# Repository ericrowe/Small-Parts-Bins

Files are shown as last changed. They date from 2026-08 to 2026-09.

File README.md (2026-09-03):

# Gridfinity Glass-Window Cassette System

This project is developing a durable, modular storage system for screws, nuts,
bolts, and other small hardware. Individually closed and labeled cassettes sit
inside stackable Gridfinity-compatible carrier trays, preventing the broad spill
failure of conventional open bins while keeping contents and approximate stock
levels visible through replaceable microscope-slide glass.

> [!WARNING]
> **AI-assisted development:** This project includes dimensions, code, geometry,
> documentation, and recommendations produced with assistance from generative
> AI. AI output can be incomplete, internally inconsistent, or geometrically
> wrong even when source calculations, previews, or mesh audits appear valid.
> Nothing in this repository is a certified engineering design or a substitute
> for independent review, slicer inspection, test prints, measurements, and
> real-world validation.
>
> Printed parts and glass can fail. Inspect every exported STL and sliced toolpath,
> reject chipped or forced glass, wear appropriate eye protection when handling
> or testing glass, and keep hands clear of sharp fragments. Do not rely on an
> unverified cassette or carrier to contain hazardous, valuable, food-contact,
> medical, electrical-safety-critical, or otherwise safety-critical contents.
> The person fabricating and using these parts is responsible for determining
> whether a particular revision, material, printer, and application are safe.

> [!CAUTION]
> **Active development:** This project is a work in progress. Dimensions,
> tolerances, interfaces, filenames, instructions, and compatibility may change
> at any time without notice as physical-test results become available. A part
> that fits one revision, material, printer, or slicer configuration may not fit
> another, and compatibility with future releases is not guaranteed unless it is
> explicitly documented.
>
> Before printing, record the exact Git commit and part version being used,
> review the matching README, manifest, and physical-test notes, and inspect the
> sliced toolpath. Print the supplied functional coupons and one complete sample
> before committing to a large batch. Do not mix revisions based only on similar
> appearance or filenames; use the documented compatibility rules. Keep known-
> good printed parts until their replacements have passed the same real-world
> tests, and expect failed or superseded prototypes during development.

## Project goals

- Keep every cassette individually closed when removed, handled, or tipped.
- Make contents and 9 mm Brother TZe labels visible from above in an open drawer.
- Use replaceable, mechanically retained microscope-slide glass rather than
  press-fit acrylic.
- Build a compatible family of cassette sizes on a consistent cassette sub-grid.
- Support optional removable dividers that form two or three equal compartments
  and minimize very-small-part transfer during rollover.
- Hold cassettes in loaded, stackable carriers using the standard 42 mm
  Gridfinity pitch, base, stacking interface, and 7 mm height increments.
- Fit practical loaded stacks below the measured drawer ceiling of
  **111.125 mm (4 3/8 in)**.
- Treat exported-STL audits and physical prints—not visual plausibility—as the
  authority for functional geometry.

## Human and AI Roles in Development

This project uses an iterative Human-in-the-Loop (HITL) engineering methodology. Responsibilities are clearly divided:

- **Human Collaborator:**
  - **Strategic Direction & Requirements:** Defines project goals, physical boundaries (e.g. drawer depth, glass sizes, hardware volumes), and prioritizes/approves plans.
  - **Fabrication & Machine Operation:** Manages slicer setup, material selection (PETG, ASA, PLA), print profiles, and printer execution.
  - **Ground-Truth Physical Validation:** Performs assembly, caliper measurements, tactile/ergonomic evaluation (grasp ease, latch tension), and real-world failure testing (stacking fit, rollover, drops).
  - **Authoritative Adjudication:** Physical observations are binding. When prints contradict CAD or mathematical models, the human's findings govern all redesigns.

- **AI Coding Agent:**
  - **Parametric CAD Generation:** Maintains editable Python mesh generators producing support-free printable STL files.
  - **Automated Geometry Auditing:** Audits STL meshes for 0 boundary edges, 0 non-manifold edges, finite coordinates, and shell connectivity.
  - **Tolerance Budgeting & Pipeline Management:** Tracks stack calculations, clearance budgets, and structured plans in `Plans/`.
  - **Continuous Documentation Integrity:** Reviews and updates all READMEs, manifests, and test notes with every commit.

## Current status — 2026-08-28

The 14U vertical carrier stack architecture has been **physically verified**
([Plan 001](hardware/plans/Completed/2026-08-28-001-validate-14u-carrier-stack.md)): two 3 × 4 × 7U
carrier trays seat onto standard Gridfinity baseplates in the target drawer with ample
clearance below the 111.125 mm drawer ceiling.

The height-optimized cassette standard is **physically verified** as **v0.8**
([Plan 002](hardware/plans/Completed/2026-08-28-002-optimize-cassette-and-carrier-height.md)):
closed envelope of **$39.55 \times 80.0 \times 36.0\text{ mm}$** (body height $32.80\text{ mm}$,
lid height $3.20\text{ mm}$), providing **$30.80\text{ mm}$ of usable internal depth**
(+35.1% capacity increase over the $28.0\text{ mm}$ baseline) and tested non-interference
clearance below the upper carrier tray's downward-protruding Gridfinity feet ($Z = 44.25\text{ mm}$).
The physically verified v0.7 lid, glass slide channel, 6.75 mm compliant PETG latch, and
3-knuckle filament hinge are 100% reusable.

The removable divider system is **physically verified**
([Plan 003](hardware/plans/Completed/2026-08-28-003-develop-optional-cassette-dividers.md)):
$1.40\text{ mm}$ recessed side-wall channels and floor groove with a thickened $4.30\text{ mm}$
left wall providing $+0.65\text{ mm}$ unobstructed vertical drop-in clearance past the hinge knuckle,
and two stations at $Y = \pm 12.87\text{ mm}$ creating three equal $24.53\text{ mm}$ compartments.

The verified closure latch plan is **[Plan 010](hardware/plans/Completed/2026-08-29-010-re-evaluate-cassette-closure-latch.md)**
(Priority 1): re-evaluate and redesign the cassette closure latch to prevent disengagement
caused by front-wall outward deflection when removable dividers are installed.

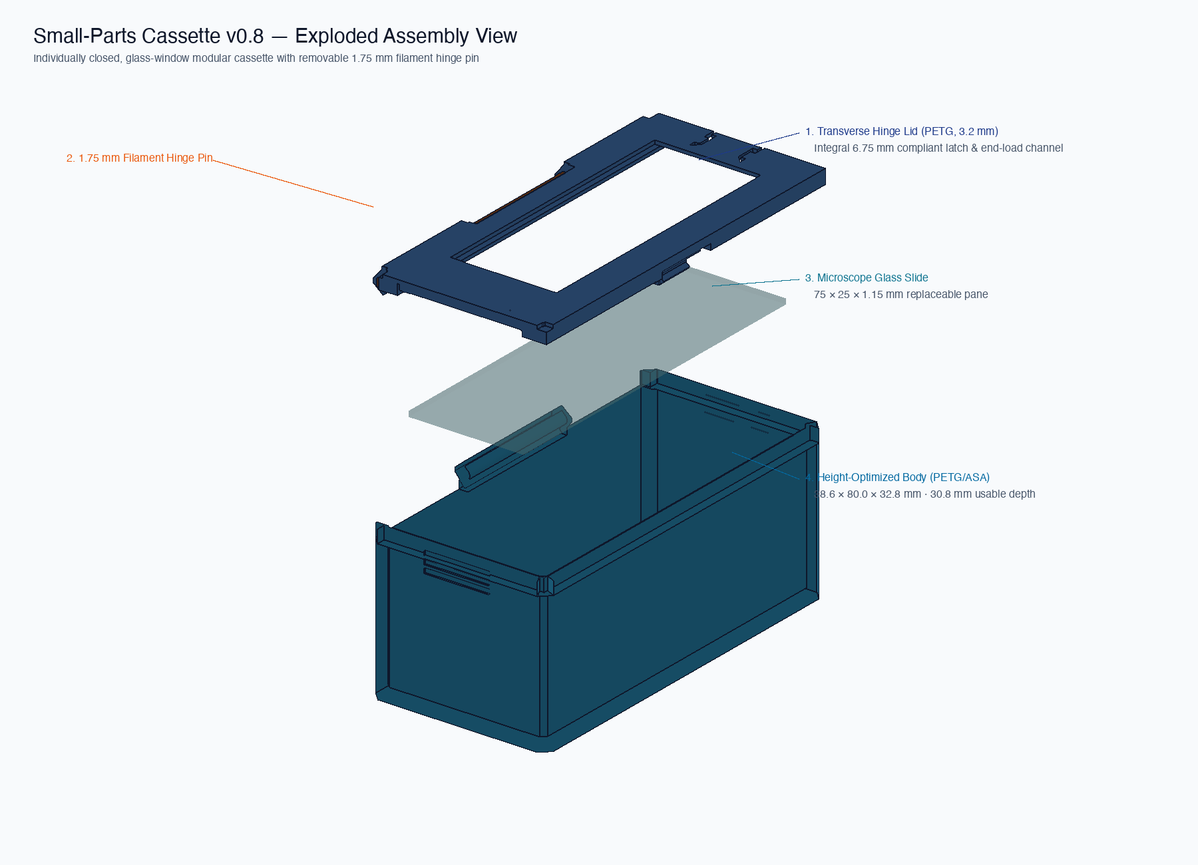
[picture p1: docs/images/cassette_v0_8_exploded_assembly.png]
Small-Parts Cassette v0.8 Exploded Assembly


## 3D System Architecture & Model Gallery

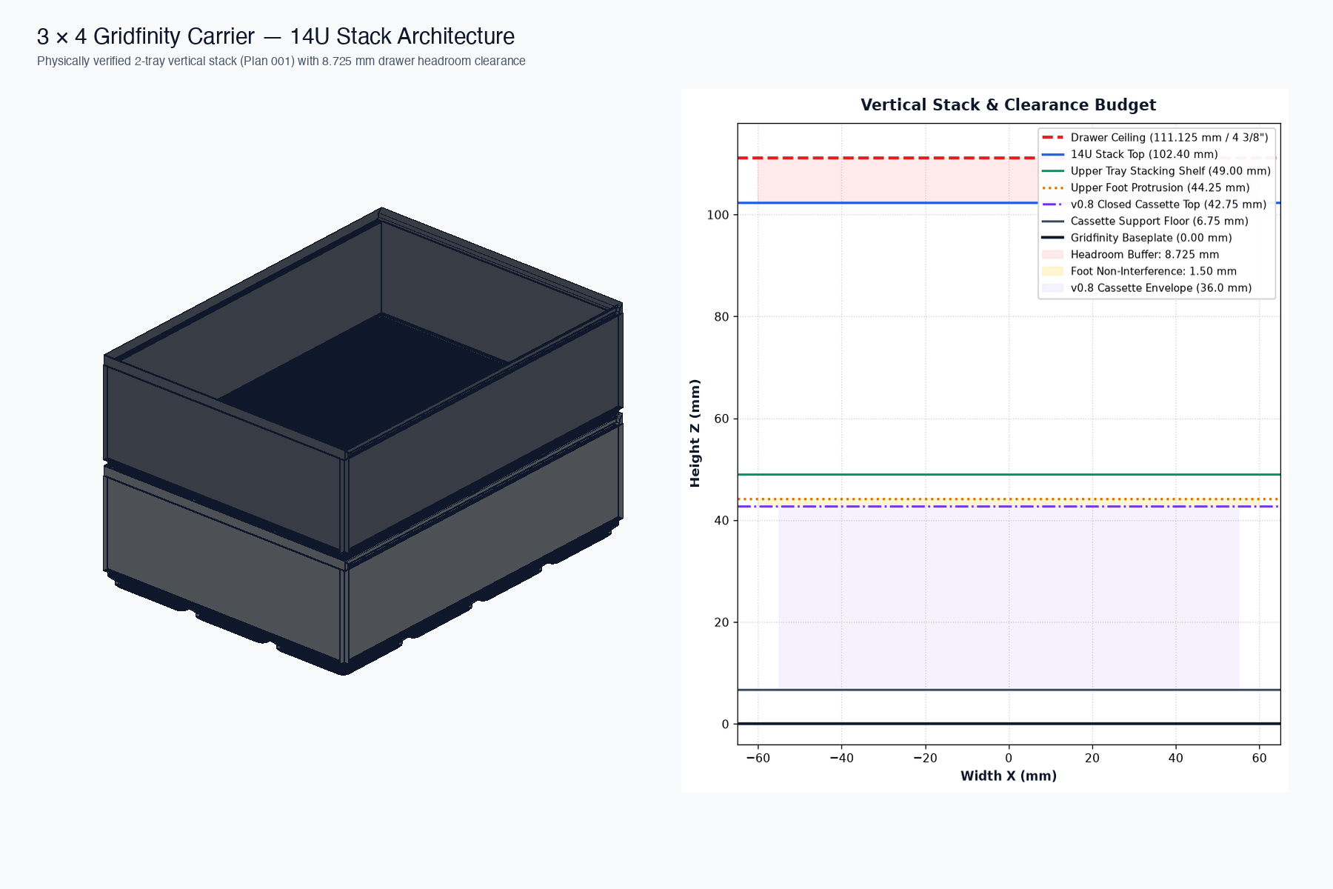
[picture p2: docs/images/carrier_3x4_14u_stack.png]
14U Carrier Stack & Tolerance Budget


| Component 3D Drawing | Description |
|---|---|
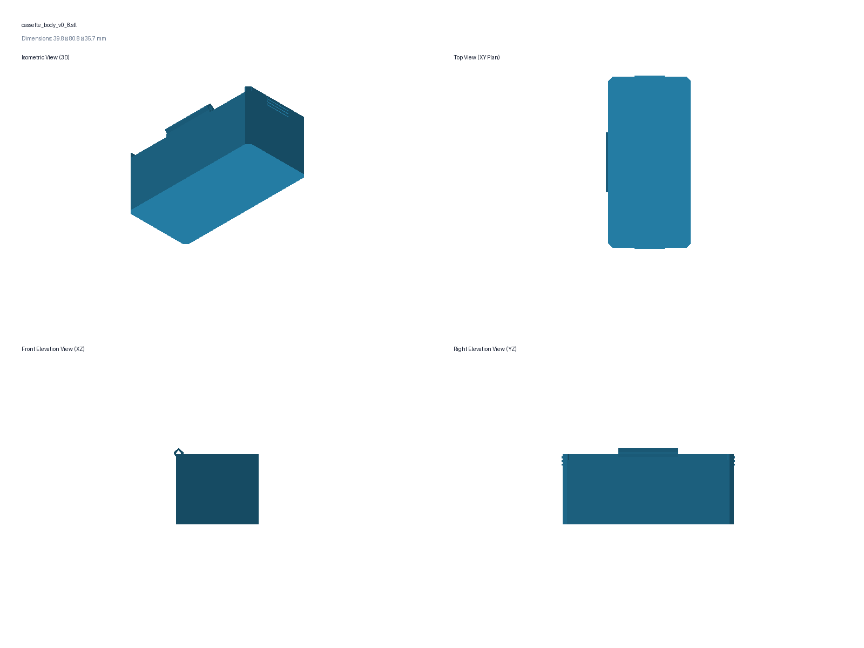
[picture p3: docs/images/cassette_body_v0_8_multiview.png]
v0.8 Body
|  | **v0.8 Cassette Body:** $38.6 \times 80.0 \times 32.8\text{ mm}$, $30.8\text{ mm}$ cavity depth, $2.0\text{ mm}$ floor. |
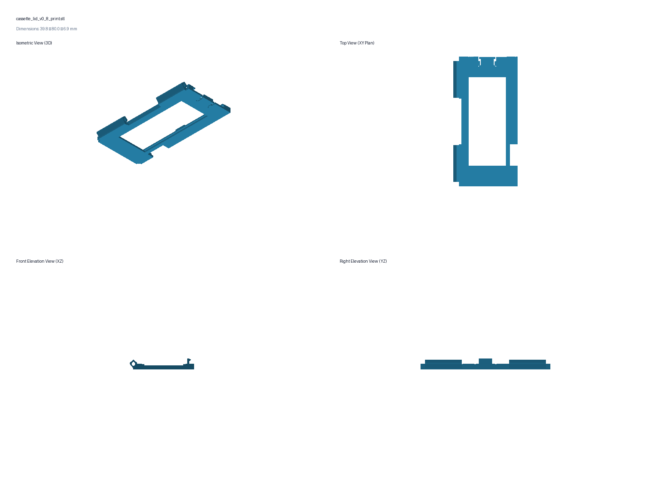
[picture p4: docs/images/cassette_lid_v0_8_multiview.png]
v0.8 Lid
|  | **v0.8 / v0.7 Transverse Lid:** End-loaded $27.0 \times 1.4\text{ mm}$ channel, compliant PETG latch. |
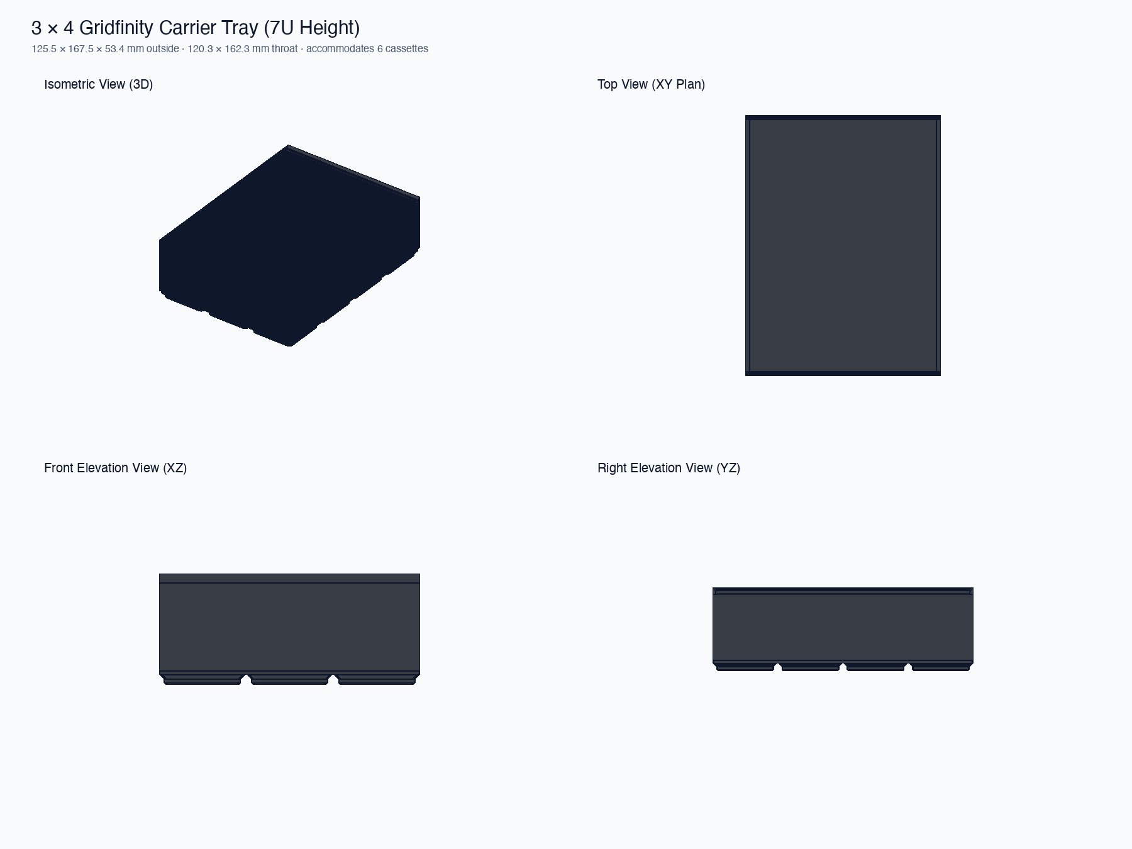
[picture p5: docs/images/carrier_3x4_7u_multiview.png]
Carrier Tray
|  | **3 × 4 × 7U Carrier:** Holds 6 modular cassettes with solid $2.6\text{ mm}$ walls. |

## Current reference configuration

| Component | Current reference | Validation state |
|---|---|---|
| Optimized cassette | v0.8 ($39.55 \times 80.0 \times 36.0\text{ mm}$ closed; $32.8\text{ mm}$ body) | **Physically verified** (Plan 002 complete) |
| Removable dividers | $1.40\text{ mm}$ slot channels, $1.20\text{ mm}$ card, 3 equal compartments | **Physically verified** (Plan 003 complete; latch re-evaluation pending in Plan 010) |
| Low-profile baseline | v0.7 ($39.55 \times 80.0 \times 28.0\text{ mm}$ closed; $24.8\text{ mm}$ body) | Physically verified; hinge, capture, clasp, and split line pass |
| Window | Plain slide glass, maximum intended 26.3 × 76.3 × 1.2 mm | Measure each delivered batch |
| Pane capture | End-loaded 27.0 × 1.4 mm channel; integral 6.75 mm PETG latch | Physically verified (Plan 009 complete) |
| Hinge pin | Straight 1.75 mm printer filament | Works well in the verified hinge pair |
| Reference carrier | 3 × 4 × 7U, six cassettes | **Physically verified** (Plan 001 complete) |
| Two-carrier stack | 14U, modeled 102.4 mm overall | **Physically verified** in target drawer (Plan 001 complete) |
| Drawer ceiling | 111.125 mm | Measured absolute ceiling |

## Development Sequence & Plan Lifecycle

The project utilizes a centralized multi-prefix plan lifecycle under [`docs/plans/`](docs/plans/):
- **`MNN` (Master / Cross-Subsystem Plans)**: End-to-end integration across hardware, labels, web catalog, and server infrastructure.
- **`HNN` (Hardware Subsystem Plans)**: 3D CAD models, Gridfinity carriers, slide cassettes, divider cards, and Cricut cut sheets under [`hardware/`](hardware/).
- **`SNN` (Server Subsystem Plans)**: FastAPI web application, SQLite schema/migrations, REST endpoints, and HTML5 camera QR scanner under [`server/`](server/).

Historical mechanical 3D print plans are archived in [`hardware/plans/Completed/`](hardware/plans/Completed/). Active software and cross-system plans are tracked in [`docs/plans/AGENTS.md`](docs/plans/AGENTS.md).

The active cassette 3D models are located in [`hardware/cassettes/glass_slide_cassette_40x80/`](hardware/cassettes/glass_slide_cassette_40x80/) as `cassette_body_v0_8.stl` and `cassette_lid_v0_8_print.stl`.

New ideas belong in [`docs/plans/IDEAS.md`](docs/plans/IDEAS.md).

## Repository Architecture

- [`AGENTS.md`](AGENTS.md) — binding dimensions, physical findings, validation rules, compatibility history, and repository working agreements.
- [`.agents/`](.agents/) — modular agent customization directory containing `skills/` (e.g. `mesh-auditor`, `cad-renderer`, `plan-pipeline`, `hardware-prototyper`) and `plugins/`.
- [`hardware/`](hardware/) — physical 3D fabrication CAD models, printable releases, manifests, previews, labels, and mechanical test archives:
  - [`hardware/carriers/`](hardware/carriers/) — Gridfinity modular trays and rocker inserts.
  - [`hardware/cassettes/`](hardware/cassettes/) — glass slide storage cassettes and divider cards.
  - [`hardware/labels/`](hardware/labels/) — SVG vector label generators, fastener database, and Cricut print-then-cut sheets.
  - [`hardware/scripts/`](hardware/scripts/) — batch STL rendering and CAD build automation.
  - [`hardware/plans/`](hardware/plans/) — historical mechanical 3D design plan archives.
- [`server/`](server/) — web catalog microservice, inventory database, and QR code scanner:
  - `server/app/` — FastAPI application and catalog routes.
  - `server/database/` — SQLite parts/bins schema and models.
  - `server/static/` & `server/templates/` — responsive web UI and HTML5 camera QR barcode scanner.
  - `server/scripts/` — automated SQLite atomic `VACUUM INTO` backup script ([`server/scripts/backup_parts.sh`](server/scripts/backup_parts.sh)) and turnkey bare-metal node provisioner ([`server/scripts/bootstrap_node.sh`](server/scripts/bootstrap_node.sh)).
  - `server/docs/` — disaster recovery runbook ([`server/docs/BACKUP_AND_RECOVERY.md`](server/docs/BACKUP_AND_RECOVERY.md)).
  - `server/tests/` — hermetic test suite.
- [`docs/plans/`](docs/plans/) — centralized multi-prefix plan lifecycle, master registry ([`docs/plans/AGENTS.md`](docs/plans/AGENTS.md)), and backlog ([`docs/plans/IDEAS.md`](docs/plans/IDEAS.md)).

## Web Catalog Server & Inventory Microservice

The server provides a responsive web UI and REST API for searching hardware specifications, reviewing tap drills, and managing bin inventory. In production, it is deployed to **Node 02 (`tasker-pi`, Pi 4B)** on port `:8090` with persistent storage on the external Samsung SSD at `/srv/database/parts/parts.db`:

1. **Setup & Start Server (Local Workstation):**
   ```bash
   cd server
   ./run.sh  # Starts on http://0.0.0.0:8090
   ```
2. **Access Points:**
   - **Dashboard:** [http://localhost:8090/](http://localhost:8090/) (or `http://tasker-pi.local:8090/`) — Overview metrics, category distribution, and active physical bins.
   - **Fastener Catalog:** [http://localhost:8090/parts](http://localhost:8090/parts) — Full-text searchable database with bi-directional column sorting, thread pitches, and tap drills.
   - **Fastener Technical Specs:** [http://localhost:8090/p/{part_id}](http://localhost:8090/p/M3-12mm-SHCS) — Detailed engineering specs and physical bin locations.
   - **Cassette Bin Management:** [http://localhost:8090/b/{bin_id}](http://localhost:8090/b/BIN-001) — Visual 1, 2, or 3-compartment cassette layout with dynamic part mapper dropdowns and one-tap stock adjusters.
   - **REST API Docs:** [http://localhost:8090/docs](http://localhost:8090/docs) — Interactive OpenAPI Swagger UI.

## Automated Backup & Turnkey Disaster Recovery

- **Target Host**: Node 02 (`tasker-pi.local`, `192.168.0.191`) co-located with Personal-Assistant.
- **Database Location**: Persistent Samsung SSD at `/srv/database/parts/parts.db` (Write-Ahead Logging).
- **Atomic SQLite Snapshots (`VACUUM INTO`)**: Daily zero-downtime snapshots captured via [`server/scripts/backup_parts.sh`](server/scripts/backup_parts.sh).
- **Encrypted Node 04 Storage**: Shipped encrypted via `restic` over SFTP to Node 04 (`pi-backup.local:/srv/backups/restic/parts-database/`).
- **Retention**: 14 daily, 8 weekly, 12 monthly snapshots.
- **Turnkey Provisioning**: Fresh nodes provisioned from bare-metal in under 5 minutes via [`server/scripts/bootstrap_node.sh`](server/scripts/bootstrap_node.sh). See [`server/docs/BACKUP_AND_RECOVERY.md`](server/docs/BACKUP_AND_RECOVERY.md).

## Working rules

- Read this README, `AGENTS.md`, the active plan, relevant release README and
  manifest, and the latest physical-test notes before changing geometry.
- Print exact functional coupons before committing material to complete parts.
- Never scale parts in the slicer to correct tolerances; change named source
  dimensions and release a new version.
- Preserve tested history through Git. A working release directory may replace
  old generated artifacts after a checkpoint when the user explicitly chooses
  Git rather than parallel copies as the revision store.
- Keep modeled, printed, and physically verified claims clearly separated.
- Treat all AI-assisted output as unverified until independently reviewed and
  validated against the actual exported artifact and physical print.
- Record the exact revision before printing, validate one sample before a batch,
  and do not assume compatibility between versions unless it is documented.
- Before completing a plan, reconcile every required project and release
  document listed in `AGENTS.md`, then archive the plan with its walkthrough.

## License

This project is available under the [MIT License](LICENSE). The license's
software warranty disclaimer supplements, and does not replace, the AI-use,
glass-handling, print-validation, and physical-safety warning above.

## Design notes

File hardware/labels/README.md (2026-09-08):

# Printable Fastener Label System & Multi-Medium Batch Exporter

This toolchain generates high-density, standardized, professional hardware labels for the **Gridfinity Glass-Window Cassette System** and workshop parts storage.

Labels adhere to the standard **$34.0 \times 10.0\text{ mm}$ strip layout** ($R = 1.0\text{ mm}$ rounded corners) with color-coded taxonomy bars, high-contrast typography, head/drive silhouette icons, and pure vector QR codes.

---

## 1. Supported Export Formats & Mediums

The batch generation engine supports 4 distinct physical output mediums:

1. **✂️ Cricut Print-Then-Cut (Letter SVG)**:
   - Multi-up Letter sheets (4 columns $\times$ 15 rows = up to 60 labels per sheet).
   - $+1.0\text{ mm}$ full bleed artwork envelope ($36 \times 12\text{ mm}$, $R=2.0\text{ mm}$) to absorb printer/Cricut mechanical drift.
   - Precision vector cut paths ($34 \times 10\text{ mm}$, $R=1.0\text{ mm}$) on red `#FF0000` stroke layer.
   - High-contrast optical registration bounding box for sensor tracking.
2. **📄 Avery 5160 / 8160 Pre-Cut Sheets (30-Up Letter)**:
   - Standard 3 columns $\times$ 10 rows on Letter paper ($1" \times 2-5/8"$ / $66.7 \times 25.4\text{ mm}$).
   - Fastener specs formatted to fit standard commercial laser/inkjet label sheets.
3. **📄 Avery 5167 / 8167 Pre-Cut Micro Sheets (80-Up Letter)**:
   - High-density 4 columns $\times$ 20 rows on Letter paper ($1/2" \times 1-3/4"$ / $44.5 \times 12.7\text{ mm}$).
   - Perfectly centers canonical $34 \times 10\text{ mm}$ labels within micro die-cut cells.
4. **📜 Continuous Thermal Roll Stream**:
   - Continuous vertical stream for Brother QL, Dymo LabelWriter, or Rollo thermal tape printers.
   - Configurable margins, gap spacing, and dashed cut guides.

---

## 2. Interactive Web Catalog Exporter (`:8090/labels`)

Access the batch export UI directly in your browser:
- Open [`http://tasker-pi.local:8090/labels`](http://tasker-pi.local:8090/labels) (or `http://localhost:8090/labels` in staging).
- Filter items by category (Metric, Imperial, Washers, Inserts, Specialty).
- Select individual parts or use "Select All".
- Choose output medium (Cricut, Avery 5160, Avery 5167, Thermal Roll).
- Preview live SVG sheet in-browser and 1-click download print-ready SVGs.

---

## 3. Hardware Taxonomy & Filament Color Mapping

| Category | Primary Hardware | Filament Material / Color | Label Accent Color |
|---|---|---|---|
| **Metric Hardware (ISO)** | M1.6, M2, M2.5, M3, M4, M5, M6, M8 (SHCS, BHCS, FHCS) | **Elegoo Blue PETG** | Blue (`#0077CC`) |
| **Imperial Hardware (SAE)** | #2-56, #4-40, #6-32, #8-32, #10-24, #10-32, 1/4"-20 | **Elegoo Orange PETG** | Orange (`#E65100`) |
| **Washers & Spacers** | Flat washers, Split lock washers, Star washers, Spacers | **Elegoo / Geeetech Green PETG** | Green (`#2E7D32`) |
| **Specialty & Wood/Pins** | Wood screws, sheet metal screws, grub screws, pins | **Elegoo / Overture Yellow PETG** | Yellow (`#D4A017`) |
| **Carrier Trays & Lids** | 3×4 7U Carrier Trays & Cassette Lids | **Elegoo Black PETG** | Neutral Black Base |
| **Heat-Set Inserts** | M2, M2.5, M3 (Short/Std/Voron), M4, M5 Brass Inserts | **Elegoo Black PETG** | Brass / Gold (`#C5A059`) |

---

## 4. Fabrication & Cricut Print-Then-Cut Workflow

1. **Export Batch Sheet:**
   - Download SVG from `/labels` or generate via `generate_labels.py`.
2. **Load into Cricut Design Space / Silhouette Studio:**
   - Import the SVG into Cricut Design Space.
   - Ungroup layers: assign the `cut-lines` layer to **Basic Cut** and `print-artwork` to **Standard Print**.
   - Align both groups to $(0,0)$ and click **Attach**.
3. **Print:**
   - Print on full-sheet printable vinyl/polyester sticker paper with a color laser or inkjet printer at 100% scale ("Actual Size").
4. **Cut:**
   - Place printed sheet on Cricut mat. Optical sensor registers fiducial corner frame and performs precision kiss-cutting ($R = 1.0\text{ mm}$ corners).
5. **Apply:**
   - Peel and apply directly to the $34 \times 10\text{ mm}$ front recessed zone of assembled cassette lids.

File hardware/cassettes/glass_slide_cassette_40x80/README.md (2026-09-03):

# Glass-slide small-parts cassette — prototype v0.8 (Optimized Height, Body Pull Tab & Dividers)

Version 0.8 implements the vertical height optimization (Plan 002), removable divider system (Plan 003), internal flanking wall ridges with reinforced closure clasp (Plan 010), $1.20\text{ mm}$ reinforced compliant glass retention clip, and body-anchored vertical dovetail pull tab for effortless in-drawer extraction (Plan 011).
It establishes the closed cassette envelope at **$39.55 \times 80.0 \times 36.4\text{ mm}$**
(body height $32.80\text{ mm}$, lid height $3.60\text{ mm}$), providing **$30.80\text{ mm}$ of
usable internal cavity depth** (+35.1% internal volume increase over the v0.7 baseline)
while maintaining a safe **$1.10\text{ mm}$ clearance margin** below the upper carrier
tray's bottom Gridfinity feet (lowest foot surface at $Z = 44.25\text{ mm}$, cassette floor at $Z = 6.75\text{ mm}$).

Key features:
1. **Optimized Usable Depth:** $30.80\text{ mm}$ internal cavity depth with $2.0\text{ mm}$ solid floor.
2. **Body-Anchored Vertical Dovetail Pull Tab (`pull_tab_v0_8.stl`):** A $15.0\text{ mm}$ tall male dovetail shank slides vertically into a monolithic reinforced boss keyway on the front/right body wall ($Y \in [15.00, 28.00\text{ mm}]$). Sized at the physically verified **$+0.10\text{ mm}$ fit standard** ($7.80\text{ mm}$ base, $5.80\text{ mm}$ neck, $2.80\text{ mm}$ thickness), it slides firmly and locks against the $45^\circ$ lead-in bottom floor stop. The upper ergonomic grip fin ($11.0\text{ mm}$ wide $\times 4.0\text{ mm}$ raised above lid) provides deep concave finger purchase scoops for effortless vertical one-handed extraction straight out of packed carrier trays in open drawers.
3. **Matching Lid Perimeter Cutaway & Symmetrical Dual Label Zones:** The lid's front perimeter skirt features an enlarged **$15.00\text{ mm}$ through-cutout** ($Y \in [14.00, 29.00\text{ mm}]$, $X \in [14.50, 19.30\text{ mm}]$) providing $+2.0\text{ mm}$ of clear air around the pull tab. Symmetrical solid **$34.0 \times 10.0\text{ mm}$ flat label zones** on BOTH the entry and far ends allow standard 9 mm Brother TZe tape to be applied on either end (or both) so labels read consistently regardless of carrier drawer orientation.
4. **Reinforced $1.20\text{ mm}$ Compliant Glass Clip:** The compliant tongue and solid roof frame are $1.20\text{ mm}$ (6 solid layers in PETG, +125% stronger) with widened $2.5\text{ mm}$ 3D root gussets, eliminating bed-peel root tear failures upon removing prints from PEI build plates while maintaining smooth manual slide service.
5. **Internal Flanking Ridges (Plan 010):** Vertical ridges projecting $+0.80\text{ mm}$ into the cavity ($1.50\text{ mm}$ wide along Y) flank the divider slots on the front wall. They create deep $1.40\text{–}1.60\text{ mm}$ guide channels ($3.00\text{ mm}$ total engagement across the cavity) and brace the front wall span down from $80\text{ mm}$ to $22.6\text{ mm}$ around the center latch.
6. **Loose-Fit Gravity Drop-In Dividers:** $33.00\text{ mm}$ wide divider cards provide **$+1.10\text{ mm}$ of lateral float clearance** across the $34.10\text{ mm}$ channel bottom span, completely eliminating outward wall wedging while maintaining $\ge 0.75\text{ mm}$ of positive capture overlap past the channel lips.
7. **Reinforced $0.85\text{ mm}$ Closure Clasp:** $1.25\text{ mm}$ thick cantilever beam on the lid with $0.85\text{ mm}$ undercut catch on the front body wall guarantees firm, positive snap retention in both divided and undivided configurations.

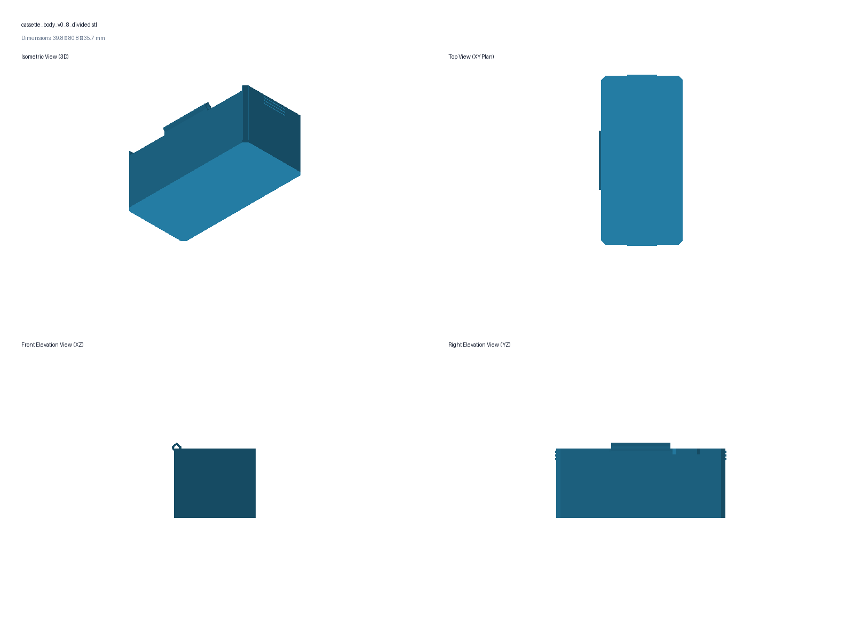
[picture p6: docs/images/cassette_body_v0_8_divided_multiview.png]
v0.8 Body Divided 3D Multi-View


v0.8 Lid 3D Multi-View

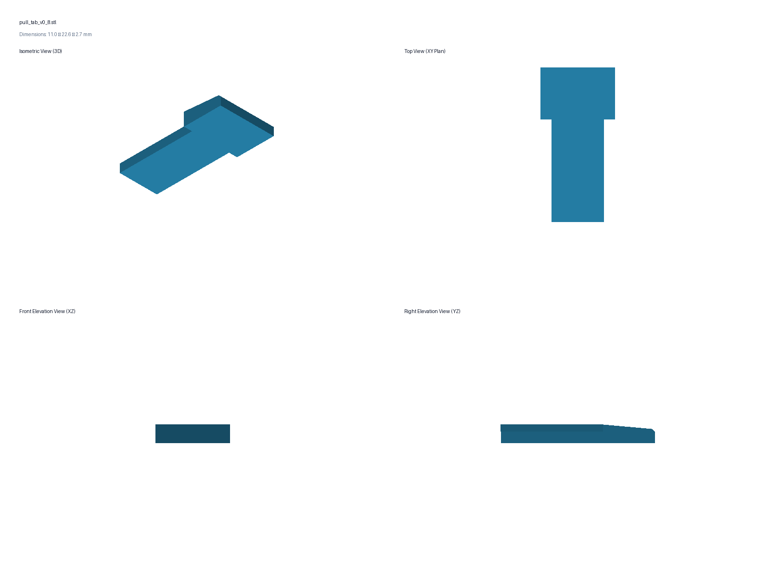
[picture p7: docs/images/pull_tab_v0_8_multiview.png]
v0.8 Pull Tab 3D Multi-View


## Print these files

- `build/cassette_body_v0_8_divided.stl` (divided body with reinforced front-wall dovetail boss keyway, $45^\circ$ under-shelf lead-in, and $0.85\text{ mm}$ catch; print upright in PETG or ASA)
- `build/cassette_body_v0_8.stl` (undivided body with dovetail keyway; print upright in PETG or ASA)
- `build/cassette_lid_v0_8_print.stl` (lid with $15.0\text{ mm}$ pull-tab clearance cutaway, dual 9 mm label zones, & $1.20\text{ mm}$ reinforced clip; print top/label-face down in PETG)
- `build/pull_tab_v0_8.stl` (ergonomic rigid pull tab with physically verified $+0.10\text{ mm}$ fit; print flat on back face in PETG, ~1 min print)
- `build/divider_card_1_2mm.stl` (baseline $33.00 \times 31.20 \times 1.20\text{ mm}$ divider card with top extraction notch and lead-in chamfers)

Print all parts exactly as supplied without internal support. A 0.4 mm nozzle,
0.20 mm layers, and four perimeters remain reasonable starting settings. Keep the
seam away from the hinge bores.

Do not print `REFERENCE_closed_assembly_DO_NOT_PRINT.stl`.

## Pane-capture geometry

| Feature | Dimension |
|---|---:|
| Loading channel | 27.0 mm wide × 1.4 mm clear height |
| Top/visible opening | 23.0 × 55.0 mm (centered at Y = 0.0 mm) |
| Opposite opening | 24.0 mm |
| Tested glass width | 24.9 mm |
| Overlap per side on tested glass | 0.95 mm top / 0.45 mm opposite |
| Maximum intended pane | 26.3 × 76.3 × 1.2 mm |
| Axial clearance at 76.3 mm length | 0.70 mm |
| PETG tongue | 8.0 mm wide × **1.20 mm thick** (6 layers) × 6.75 mm free length with 2.5 mm 3D root gussets |
| Latch finger pad | 10.0 mm wide |
| Frame entry slot cutout | Tight 0.50 mm perimeter outline (11.0 mm pad cut / 9.0 mm tongue cut) |
| Relaxed tongue-to-glass gap | Flush at channel ceiling (0.2–0.3 mm clearance over 1.1–1.2 mm glass) |
| Symmetrical end borders | Symmetrical 12.5 mm end borders (34.0 × 10.0 mm label zones) on both ends for 9 mm TZe tape |

The pane enters at the end opposite the label, slides under the solid label band,
and stops at the far end. Manually depress the compliant tongue outward, slide
the pane completely past the shoulder, then release it.

The visible window is **23.0 × 55.0 mm** (centered at $Y = 0.0\text{ mm}$) and both label zones are **34.0 × 10.0 mm**.
The closed envelope without pull tab is **39.55 × 80.0 × 36.4 mm**; with pull tab installed, height reaches **40.4 mm** in the inter-foot stacking clearance valley (+1.85 mm safety margin).

## Assembly and test order

1. Inspect the printed body, dovetail keyway, divider channels, flanking ridges, pane channel, and hinge bores.
2. Insert pane into lid by depressing compliant tongue manually. Slide pane to far stop and release.
3. Slide `pull_tab_v0_8.stl` down into the body's front-wall dovetail keyway until seated against the bottom stop.
4. Assemble the lid to the body with approximately 75 mm of straight 1.75 mm filament.
5. Drop in divider cards: verify smooth gravity drop-in without wall friction.
6. Verify smooth hinge rotation through at least 120 degrees, clean lid closure around pull tab, and positive clasp closure.
7. Place cassette inside a 3 × 4 carrier tray, pinch the pull tab, and verify effortless vertical extraction directly from above.
8. Stack a second carrier tray on top to confirm full seating with $+1.85\text{ mm}$ clearance above pull tabs.

## Export validation

All binary STLs pass topological inspection reporting zero boundary edges, zero non-manifold edges, zero degenerate triangles, and finite coordinates.

Regenerate all current artifacts with:

```bash
python3 generate_cassette.py --out build --preview
```

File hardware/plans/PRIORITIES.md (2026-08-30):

# Queued-plan priorities

Plan numbers are permanent historical identifiers, not execution priority. This
file is the authoritative order for selecting the next queued plan after the
currently in-work plans. Priority ranks exist only in this file; never copy them
into individual plan documents.

## Prioritization method

Review every queued plan against these factors, in order:

1. **Safety and containment risk:** known failures involving glass, spills,
   sharp parts, or unstable loaded assemblies take precedence.
2. **Dependency blocking:** work needed by several later plans ranks ahead of
   work that affects only one optional variant.
3. **Rework avoidance:** resolve uncertain interfaces before optimizing or
   duplicating geometry that depends on them.
4. **Evidence and information gain:** prefer focused tests that can eliminate
   major design uncertainty at reasonable print cost.
5. **User value:** prioritize features that materially improve routine storage,
   handling, visibility, capacity, or configuration.
6. **Readiness and cost:** when higher factors are comparable, prefer work that
   can be tested with available parts and smaller prints.

Priority is reassessed whenever physical feedback reveals a new failure, a plan
changes a downstream dependency, or the user changes project goals. Changing
priority does not renumber plan files. Record the reason and date below, edit
only this table, run the pipeline checker, and commit the change.

Several plans may be in work simultaneously. The table orders work that remains
queued; it does not rank active plans against one another. A lower-ranked queued
plan may be activated alongside higher-ranked work when its current steps are
independent, capacity is available, and all dependency-gated decisions remain
explicitly provisional.

## Current order — 2026-08-29

| Priority | Plan | Reason |
|---:|---|---|
| 1 | 005 — Develop the larger cassette family | Extends the verified smallest interfaces without propagating unresolved geometry. |
| 2 | 006 — Develop mixed-layout carriers | Requires physical envelopes from the completed cassette family. |
| 3 | 007 — Validate system durability and materials | Exercises production-candidate cassettes and carriers after their interfaces stabilize. |
| 4 | 008 — Prepare and archive the production baseline | Final integration and release work; depends on all prior physical evidence. |

Plans 001 (14U carrier stack validation), 002 (cassette height optimization),
003 (removable cassette dividers), 004 (smallest cassette & carrier finalization),
010 (closure latch re-evaluation & clip reinforcement), and 011 (cassette removal features) are completed and archived.
Plan 013 (direct 1x2 7U Gridfinity cassette bin) was canceled per user directive.
Plan 012 (generate printable label sheets) is currently active in execution. The next queued plan is Plan 005.

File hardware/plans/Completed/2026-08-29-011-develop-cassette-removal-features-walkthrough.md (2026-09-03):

# Walkthrough — Plan 011: Develop Cassette Features to Aid Removal from Carrier

## Executive Summary

Plan 011 resolved the challenge of extracting individual cassettes from tightly packed Gridfinity carrier trays ($3 \times 4$ array with minimal $0.4\text{ mm}$ inter-cassette spacing) directly from above inside open drawers.
Through rapid prototyping and Human-in-the-Loop (HITL) physical validation, a modular, body-anchored vertical dovetail pull tab (`pull_tab_v0_8.stl`), reinforced boss keyway on the body wall, and matching enlarged lid through-notch were designed, printed in PETG, and physically verified.

---

## 1. Problem Exploration & Mechanism Selection

In densely packed $3 \times 4$ carrier arrays:
* **Friction & Finger Purchase:** Smooth-sided cassettes with $0.4\text{ mm}$ gaps leave no purchase room for fingers to lift them vertically.
* **Evaluated Alternatives:**
  * *Top Pinch Flutes:* Tested on earlier lids; lacked sufficient tactile purchase for heavy hardware bins.
  * *Push-to-Tilt Tray Rockers:* Evaluated with physical rocker prints; pivoting the cassette elevated the corner by only ~4 mm, which was inadequate for comfortable finger grasp without disturbing neighboring bins.
  * *Tray Side Scallops:* Rejected to prevent reducing carrier wall strength under heavy loads and to avoid requiring tray removal from drawers.
  * *Lid-Mounted Pull Tabs:* Investigated; determined there was insufficient structural room on the front lid rail without compromising the internal glass channel or label area.
* **Selected Standard:** A rigid, standalone pull tab (`pull_tab_v0_8.stl`) that anchors into a vertical dovetail keyway integrated directly into the front body wall, passing through a generous clearance notch in the lid.

---

## 2. Geometry Architecture & Design

```
+-------------------------------------------------------------+
|                     Closed Cassette v0.8                    |
|                                                             |
|  [ Hinge ] ===== [ Glass Window ] ===== [ Lid Clearance ]   |
|     |                                           |           |
|     +-----------------------------------+       |           |
|     |  Body Cavity & Dividers           |   [ Pull Tab ]    |
|     |                                   |  (Grip + Shank)   |
|     |                                   |       |           |
|     +-----------------------------------+   [ Dovetail ]    |
|                                             [ Boss Keyway ] |
+-------------------------------------------------------------+
```

### Key Dimensions & Features:
1. **Monolithic Reinforced Body Boss Keyway:**
   * **Span:** $Y \in [15.00, 28.00\text{ mm}]$ ($13.00\text{ mm}$ wide solid boss column) on the inside front/right body wall.
   * **Sidewalls:** Solid **$2.50\text{ mm}$ thick sidewalls** ($X \in [14.80, 17.80\text{ mm}]$) flanking the dovetail slot with $45^\circ$ lead-in chamfers into the cavity wall.
   * **Outer Wall:** **$1.50\text{ mm}$ solid wall** behind the keyway ($X \in [17.80, 19.30\text{ mm}]$).
   * **Floor Stop:** Solid bottom stop at $Z = 17.80\text{ mm}$ supported by a **$45^\circ$ support-free lead-in taper** sloping down to $Z = 15.30\text{ mm}$ where it meets the inner vertical cavity wall.
   * **Slot Envelope:** $8.00\text{ mm}$ base width, $6.00\text{ mm}$ throat neck width, $3.00\text{ mm}$ depth ($X \in [14.80, 17.80\text{ mm}]$).

2. **Physically Verified Pull Tab (`pull_tab_v0_8.stl`):**
   * Sized at the physically verified **$+0.10\text{ mm}$ fit clearance standard**:
     * **Base Width:** $7.80\text{ mm}$ ($Y \in [-3.90, +3.90\text{ mm}]$).
     * **Throat Neck Width:** $5.80\text{ mm}$ ($Y \in [-2.90, +2.90\text{ mm}]$).
     * **Shank Thickness:** $2.80\text{ mm}$ ($X \in [14.90, 17.70\text{ mm}]$).
   * **Ergonomic Grip Head:** $+4.00\text{ mm}$ raised fin above the lid with deep concave thumb/finger hollow scoops and tactile horizontal grip ribs on the face-up side.
   * **Print Orientation:** Prints 100% flat on its back face directly on the print bed with zero supports in **~60 seconds** in PETG.

3. **Enlarged Sloppy Lid Clearance Cutaway:**
   * **Notch Span:** Full-depth through-notch spanning **$15.00\text{ mm}$** ($Y \in [14.00, 29.00\text{ mm}]$) from $X = 14.50$ to $19.30\text{ mm}$ across all $3.60\text{ mm}$ of lid thickness.
   * **Clearance:** Provides **$+2.00\text{ mm}$ clear sloppy air** on each side around the $11.0\text{ mm}$ pull tab grip fin, allowing the lid to swing freely through 120° and latch securely with zero binding.
   * **Protection:** Preserves a solid plastic barrier enclosing the internal glass microscope slide loading channel.

4. **Stacking Clearance Budget:**
   * Pull tab apex sits at $Z = 40.40\text{ mm}$ (carrier $Z = 47.15\text{ mm}$).
   * Located inside the upper carrier tray's central inter-foot clearance valley (ceiling $Z = 49.00\text{ mm}$), preserving **$+1.85\text{ mm}$ of clear vertical air** below loaded upper carrier trays.

---

## 3. Physical Validation Record

* **2026-08-29 (HITL Physical Validation):**
  * **Test Articles:** Body with reinforced boss keyway, lid with $15.00\text{ mm}$ through-notch, and progressive pull tab tolerance ladder (`_fit_0_20`, `_fit_0_15`, `_fit_0_10`, `_fit_0_05`) printed in PETG on PEI textured sheet.
  * **Results:**
    * The $+0.10\text{ mm}$ clearance variant (`pull_tab_v0_8_fit_0_10.stl`) seated firmly into the keyway, locked positively against the bottom stop, and eliminated lateral wobble while remaining removable by hand when desired.
    * The lid closed, swung through its full arc, and latched securely with zero interference against the installed tab: *"10 worked, and the cover closes now."*
  * **Outcome:** $+0.10\text{ mm}$ adopted as the standard default for `pull_tab_v0_8.stl`.

---

## 4. Verification and Artifact Deliverables

| Artifact | Description | Audit Status |
|---|---|---|
| [`cassette_body_v0_8_divided.stl`](../../cassettes/glass_slide_cassette_40x80/build/cassette_body_v0_8_divided.stl) | Divided body with monolithic reinforced boss keyway & $45^\circ$ lead-in | Passed (0 boundary / 0 non-manifold) |
| [`cassette_body_v0_8.stl`](../../cassettes/glass_slide_cassette_40x80/build/cassette_body_v0_8.stl) | Undivided body with monolithic reinforced boss keyway & $45^\circ$ lead-in | Passed (0 boundary / 0 non-manifold) |
| [`cassette_lid_v0_8_print.stl`](../../cassettes/glass_slide_cassette_40x80/build/cassette_lid_v0_8_print.stl) | Lid with $15.0\text{ mm}$ sloppy through-cutout & $1.20\text{ mm}$ glass clip | Passed (0 boundary / 0 non-manifold) |
| [`pull_tab_v0_8.stl`](../../cassettes/glass_slide_cassette_40x80/build/pull_tab_v0_8.stl) | Production pull tab (+0.10 mm verified fit standard) | Passed (0 boundary / 0 non-manifold) |
| [`pull_tab_v0_8_multiview.png`](../../../docs/images/pull_tab_v0_8_multiview.png) | 3D multi-view engineering drawing of pull tab | Complete |
| [`cassette_lid_v0_8_multiview.png`](../../../docs/images/cassette_lid_v0_8_multiview.png) | 3D multi-view engineering drawing of lid with pull tab cutout | Complete |
| [`cassette_body_v0_8_divided_multiview.png`](../../../docs/images/cassette_body_v0_8_divided_multiview.png) | 3D multi-view engineering drawing of divided body | Complete |

Plan 011 is complete and archived.

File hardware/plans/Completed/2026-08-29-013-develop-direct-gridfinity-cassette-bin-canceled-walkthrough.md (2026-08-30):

# Plan 013 Walkthrough — Develop Direct 1x2 7U Gridfinity Cassette Bin (CANCELED)

## Summary

Plan 013 explored developing a standalone $1 \times 2$ Gridfinity-compatible cassette bin (7U height) with a direct bin-on-bin stacking interface and replaceable glass microscope slide window.

## Iteration History

1. **Embedded Hinge Exploration:** Attempts to embed the peaked 3-knuckle filament hinge below the stacking lip encountered geometry conflicts between the hinge pin insertion bore and the divider channels.
2. **Horizontal Sliding Lid Variant:** A horizontal sliding lid architecture was developed with continuous guide rails recessed below the stacking lip and an open front entry mouth.
3. **Cancellation:** The design iterations highlighted excessive geometric complexity around the sliding guide tracks, corner closures, and finger pull mechanisms compared to the verified, highly functional **Cassette + Carrier Tray System Architecture** (Plans 001–004, 010, 011).

Per user directive on 2026-08-29, the experiment was canceled to preserve project focus on the proven modular cassette family and carrier ecosystem.

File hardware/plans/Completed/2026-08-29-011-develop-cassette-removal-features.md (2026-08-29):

# Plan 011 — Develop cassette features to aid removal from carrier

- Status: Completed
- Depends on: Plans 001–003, 009, and 010 completed
- Created: 2026-08-29
- Started: 2026-08-29
- Completed: 2026-08-29
- Git start: `d3ba095`
- Git completion: `3e2091f`

## Outcome

Develop and evaluate cassette and carrier features to solve the problem of extracting individual
cassettes from closely packed Gridfinity carrier trays (3 × 4 layout with 0.4 mm inter-cassette gaps),
enabling human fingers to easily and reliably grasp and remove any loaded cassette directly from above
while the carrier remains inside an open drawer.

## Problem Statement & Exploratory Scope

In tightly packed $3 \times 4$ carrier arrays with minimal ($0.4\text{ mm}$) inter-cassette spacing:
* Smooth-sided cassettes leave insufficient purchase room for fingers to lift them vertically.
* Shallow tilt/rocker mechanisms do not elevate the cassette enough above adjacent bins.
* Outer tray scallops weaken carrier wall integrity under heavy hardware loads and require removing the tray from the drawer.

This plan encompasses designing, testing, and selecting effective extraction solutions—such as body-anchored vertical pull tabs, finger purchase contours, push-assist aids, or lid clearance features—to provide effortless tool-free removal from above.

## Requirements

- Enable effortless two-finger vertical extraction directly from above without tools and without prying against the glass.
- Provide a robust anchor mechanism:
  - Utilize a $15.0\text{ mm}$ vertical dovetail keyway integrated into the front/right body wall ($X \in [14.80, 17.80\text{ mm}]$, $Y \in [15.00, 28.00\text{ mm}]$).
  - Add a clean clearance notch in the lid's front perimeter skirt ($Y \in [14.00, 29.00\text{ mm}]$) leaving $\ge 0.5\text{ mm}$ solid plastic between the glass channel and the cutout.
  - Sized pull tab (`pull_tab_v0_8.stl`) with $15.0\text{ mm}$ vertical dovetail shank and $+4.0\text{ mm}$ raised contoured grip fin with concave finger purchase scoops.
- Maintain support-free FDM 3D printing for all parts (lid prints top-face down directly on bed; pull tab prints flat on its back face in PETG in ~1 minute).
- Stacking clearance: Ensure all removal features remain strictly below the upper carrier tray's central inter-foot clearance valley ($Z \le 40.50\text{ mm}$, providing $\ge +1.80\text{ mm}$ of clear vertical air below upper carrier trays).
- Preserve backwards compatibility and modularity: pull tab is modular and optional per box.

## Non-goals

- Do not alter the 14U carrier tray external walls, base feet, or stacking interface.
- Do not reduce carrier wall thickness or add cutouts that weaken carrier load capacity.
- Do not alter the glass microscope slide dimensions ($75 \times 25 \times 1.1\text{–}1.2\text{ mm}$) or positive slide retention mechanism.

## Implementation steps

1. [x] **Problem Exploration & Mechanism Prototyping:** Evaluated top pinch flutes, push-to-tilt rocker inserts, and lid-mounted tabs; established requirement for robust body-anchored vertical extraction feature.
2. [x] **Body Dovetail Keyway Integration:** Added monolithic reinforced $13.0\text{ mm}$ boss column with $2.5\text{ mm}$ solid sidewalls, $1.5\text{ mm}$ outer back wall, and $45^\circ$ under-shelf lead-in taper into `build_divided_body()` and `build_body()`.
3. [x] **Lid Clearance Cutaway & Solid Roof Restoration:** Added $15.0\text{ mm}$ wide full-depth through-notch ($Y \in [14.00, 29.00\text{ mm}]$) in `build_lid_local()` allowing generous sloppy clearance around the pull tab while preserving the solid flat rear label roof.
4. [x] **Pull Tab Generator (`pull_tab_v0_8.stl`):** Modeled vertical shank male dovetail and ergonomic grip head in `build_pull_tab()`, printable flat on back face.
5. [x] **Tolerance Fit Ladder Calibration:** Generated progressive fit variants (`_fit_0_20`, `_fit_0_15`, `_fit_0_10`, `_fit_0_05`).
6. [x] **Physical Validation:** Sliced and printed in PETG. The $+0.10\text{ mm}$ fit variant (`pull_tab_v0_8_fit_0_10.stl`) seated firmly against the bottom stop, eliminated wobble, and the lid closed and latched cleanly without interference. Set $+0.10\text{ mm}$ as production baseline standard.
7. [x] **Export & Mesh Audit:** Verified all STLs for 0 boundary edges and 0 non-manifold edges.
8. [x] **CAD Multi-Views & Documentation:** Rendered multi-view sheets and updated `README.md` and `AGENTS.md`.
9. [x] **Plan Archive:** Archived Plan 011 with comprehensive walkthrough narrative.

## Acceptance criteria

- [x] Pull tab slides firmly down into the body wall dovetail keyway and seats against the bottom stop.
- [x] Lid closes completely and latches without binding against the pull tab.
- [x] Pull tab allows effortless vertical finger extraction from a fully packed carrier tray.
- [x] Closed assembly with pull tab fits under stacked upper carrier trays with $\ge +1.50\text{ mm}$ clearance.
- [x] All exported binary STLs pass mesh audit (0 boundary edges, 0 non-manifold edges).

## Validation record

- **Physical Finding (2026-08-29):** The $+0.10\text{ mm}$ fit clearance variant (`pull_tab_v0_8_fit_0_10.stl`, $7.80\text{ mm}$ base, $5.80\text{ mm}$ neck, $2.80\text{ mm}$ thickness) was physically printed and tested by the user. Confirmed: "10 worked, and the cover closes now."
- **Lid Cutout Finding (2026-08-29):** The enlarged $15.00\text{ mm}$ through-notch allows the lid to swing freely through 120° and positively latch without touching or deflecting against the installed pull tab.

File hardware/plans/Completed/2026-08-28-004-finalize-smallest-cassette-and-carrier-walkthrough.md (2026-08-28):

# Plan 004 Walkthrough — Finalize the Smallest Cassette and Six-Cassette Carrier

- Completed: 2026-08-28
- Archived plan: `2026-08-28-004-finalize-smallest-cassette-and-carrier.md`
- Git range: `main..main`

## 1. Objective and Scope

Plan 004 aimed to consolidate the verified carrier (Plan 001), height-optimized cassette body (Plan 002), removable divider system (Plan 003), and positive glass capture (Plan 009) into a production release candidate for the smallest $40 \times 80\text{ mm}$ cassette family member and its 6-cassette $3 \times 4$ carrier tray.

## 2. Boundary Condition & Physical Failure Mode

During physical testing of the integrated v0.8 divided body and divider cards:
1. **Front-Wall Deflection:** Inserting the baseline $1.20\text{ mm}$ divider cards into the $1.40\text{ mm}$ side-wall slots creates outward deflection on the front (latch-side) long wall of the cassette body.
2. **Latch Disengagement:** The v0.7/v0.8 closure clasp features a $1.20\text{ mm}$ thick cantilever beam on the lid that engages a central $0.65\text{ mm}$ undercut catch on the front body wall ($Y \in [-4.0, +4.0\text{ mm}]$). The outward deflection of the front wall under divider insertion reduces or eliminates this $0.65\text{ mm}$ engagement overlap, causing the latch to fail to remain positively closed.

## 3. Plan Closeout and Transition

Per the stop and rollback criteria defined in Plan 004, production candidate finalization cannot proceed while a critical containment interface (the closure latch) fails under valid operational conditions (divider installation).

Plan 004 is therefore closed, and a dedicated, focused engineering ticket—**Plan 010: Re-evaluate Cassette Closure Latch**—has been created and queued at **Priority 1** to redesign the latch and front-wall interface.

## 4. Reusable Parts & Stable Baseline

- **3 × 4 × 7U Carrier Trays:** Fully verified and physically stable (Plan 001).
- **v0.8 Envelope & Internal Cavity:** $39.55 \times 80.0 \times 36.0\text{ mm}$ closed envelope, $30.8\text{ mm}$ depth (Plan 002).
- **Thickened Hinge Wall & Divider Channels:** $4.30\text{ mm}$ left wall with $+0.65\text{ mm}$ knuckle clearance and $1.40\text{ mm}$ slot channels (Plan 003).
- **Glass Capture & Hinge:** $27.0 \times 1.4\text{ mm}$ end-loaded glass channel, $6.75\text{ mm}$ PETG slide tongue, and support-free 3-knuckle filament hinge (Plan 009).

## 5. Next Steps

Execution proceeds immediately to **Plan 010** to investigate and resolve the latch engagement failure across divided and undivided configurations via rapid tolerance and geometry coupons before resuming the production release freeze.

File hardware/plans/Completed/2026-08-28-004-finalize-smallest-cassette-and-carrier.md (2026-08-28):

# Plan 004 — Finalize the smallest cassette and six-cassette carrier

- Status: Complete
- Depends on: Plans 001–003 and 009 completed and physically accepted
- Created: 2026-08-27
- Started: 2026-08-28
- Completed: 2026-08-28
- Git start: `main` (activating Plan 004)
- Git completion: `main` (Plan 004 closeout)

## Outcome

Combine the verified carrier, optimized height, divider system, hinge, latch,
glass retention, label, and dedicated cassette grab/removal features into the
production candidate for the smallest cassette module and its six-cassette 3 × 4 carrier.

## Requirements

- Preserve all binding dimensions selected by Plans 001–003.
- Provide zero-, one-, and two-divider cassette configurations without changing
  the closed external envelope.
- Implement positive grab features (such as tactile pinch ribs, recessed end
  grips, or edge-grasping features on the cassette ends/rim) to facilitate
  grasping and lifting cassettes from tightly packed carrier trays without
  requiring tools or loading/prying against the glass.
- Keep all cassette features, including grab ribs and pulls, below the carrier
  stacking engagement plane.
- Address outside hinge overhang geometry to ensure clean printability, minimal droop, and proper inter-cassette packing clearance.
- Remove legacy corner overhangs / step blocks at the ends of the hinge side of the body and lid.
- Preserve the standard Gridfinity base/lip interface and 2.0 mm minimum carrier
  walls.
- Maintain visible glass and labels when the drawer is open.
- Retain individual cassette closure during removal and carrier tip-over.

## Non-goals

- Do not add larger cassette footprints or mixed-size layouts.
- Do not introduce cosmetic geometry that jeopardizes verified interfaces.
- Do not replace microscope-slide glass or the 1.75 mm filament hinge pin.

## Reusable parts and compatibility

- Identify and reuse every verified lid, body, retainer, glass pane, hinge pin,
  and carrier that remains geometrically compatible.
- A version-label change alone must not force a reprint.
- Preserve all earlier tested release directories and document superseded parts.

## Implementation steps and test prints

1. [x] Reconcile the authoritative dimensions and physical results from Plans
   001–003 into one release parameter table.
2. [x] Review source geometry and examine hinge overhang, pocket, label, divider, and clasp interfaces.
3. [x] Evaluate divider-body physical interaction and closure latch holding force under loaded divider conditions.
4. [x] **Physical Finding / Boundary Event:** Physical testing revealed that inserting divider cards into the body channels exerts outward lateral deflection on the front (latch-side) wall, causing the central closure clasp ($0.65\text{ mm}$ undercut) to lose engagement and fail to hold closed.
5. [x] **Closeout Decision:** Per the stop condition, close out Plan 004 and spin out a dedicated high-priority plan (**Plan 010: Re-evaluate Cassette Closure Latch**) before final production candidate freeze.

## Acceptance criteria

- [x] Physical boundary conditions and failure modes documented.
- [x] Latch failure under divider insertion identified and isolated.
- [x] Dedicated follow-up plan (Plan 010) created and prioritized to resolve latch retention.
- [x] Repository documentation reconciled.

## Validation record

### Physical Testing Finding — 2026-08-28

- **Test Assembly:** Full-size v0.8 divided cassette body with baseline $1.20\text{ mm}$ divider cards installed in the $1.40\text{ mm}$ wall slots, paired with the v0.7/v0.8 lid.
- **Observed Behavior:** Inserting the divider cards pushes the front (latch-side) wall of the body outward. Because the existing closure clasp relies on a $1.20\text{ mm}$ cantilever beam engaging a $0.65\text{ mm}$ undercut catch on the center of the front body wall ($Y \in [-4.0, +4.0\text{ mm}]$), the outward wall deflection reduces the effective clasp overlap below retention threshold, causing the latch to fail/disengage.
- **Action Taken:** Plan 004 is closed. Plan 010 is queued at Priority 1 to re-evaluate and redesign the latch architecture (evaluating deeper catch engagement, front-wall stiffening ribs, divider width clearance, and/or alternative latch geometries) before final cassette release.

## Stop and rollback conditions

- Do not declare a production candidate if any accepted feature regresses.
- If a feature needs geometry changes, keep this plan active only for a bounded
  correction to the established smallest system; place broader redesigns back
  into the idea pipeline.

## Archive handoff

This walkthrough documents the state of the smallest cassette system at closeout of Plan 004, the discovery of the divider-induced latch failure mode, and the transition to Plan 010 for latch re-evaluation.

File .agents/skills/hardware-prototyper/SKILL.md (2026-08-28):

---
name: hardware-prototyper
description: >-
  Design rapid physical test coupons, tolerance fit ladders, and document Human-in-the-Loop (HITL)
  physical measurements. Use this skill when calibrating 3D printer tolerances, snap-fits,
  sliding channels, or hinge clearances before committing to large production prints.
---

# Hardware Prototyper Skill

This skill standardizes rapid iterative physical prototyping and caliper measurement logging.

## Core Rules for Physical Validation

1. **Always Print Fit Coupons First:**
   - Never print a large 5-hour multi-feature part to test a 0.2 mm fit tolerance.
   - Design isolated, 15-minute test coupons (e.g. 4-step fit ladder) to physically calibrate clearances under actual slicer and material conditions.
2. **Preserve Tested Ladders in Git History:**
   - Record exact measured dimensions (e.g. caliper readings to 2 decimal places), material (PETG/ASA/PLA), nozzle size, and slicer layer height.
3. **The Physical Print Governs CAD:**
   - If a physical print contradicts CAD model assumptions (e.g. bore sag, thermal shrinkage, bed adhesion warping), update the model to match physical reality rather than scaling in the slicer.

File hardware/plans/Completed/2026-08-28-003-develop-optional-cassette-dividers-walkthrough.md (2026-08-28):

# Plan 003 Walkthrough — Develop Optional Cassette Dividers

## 1. Objective and Scope

Plan 003 developed a removable divider system for the height-optimized **v0.8** cassette ($36.0\text{ mm}$ closed height). The goal was to provide optional multi-compartment storage (dividing the cassette into 3 equal compartments) with positive floor and side-wall retention to prevent part transfer during rollover, while keeping the cavity smooth and unobstructed when dividers are omitted.

## 2. Locating Concept & Fit Coupon Validation

1. **Locating Architecture:**
   - Rather than protruding internal ribs that consume volume when undivided, Plan 003 uses **$0.60\text{ mm}$ recessed side-wall channels** and a continuous **$0.60\text{ mm}$ floor groove**.
   - A dedicated 4-station tolerance coupon (`Cassettes/divider_fit_coupon_v0_1/`) evaluated slot widths from $1.30\text{ mm}$ to $1.60\text{ mm}$ against a baseline $1.20\text{ mm}$ divider card.
2. **Coupon Physical Result:**
   - **Station 2 ($1.40\text{ mm}$ slot width, $+0.20\text{ mm}$ clearance)** was physically selected for its smooth tactile slide, secure seating, and absence of binding.

## 3. Full-Size Body Engineering & Hinge/Clasp Clearance

When translating the coupon interface to the full $80.0\text{ mm}$ body span, two physical geometric interferences were resolved:

1. **Straight-Line Vertical Drop-In (Hinge Knuckle Clearance):**
   - The body's peaked hinge knuckle on the left rim extends inward to $X = -16.15\text{ mm}$.
   - To provide a 100% straight vertical drop-in path without requiring the user to angle or tilt the card, the inner left wall was thickened to **$4.30\text{ mm}$** (inner face at $X = -15.00\text{ mm}$, slot recess to $X = -15.60\text{ mm}$).
   - The divider card's left edge ($X = -15.50\text{ mm}$) has **$+0.65\text{ mm}$ of clear vertical air** past the hinge knuckle, while the increased wall thickness eliminates long-wall flex.
2. **Closure Clasp Integrity & Station Layout:**
   - The central closure catch on the right wall spans $Y \in [-4.00, +4.00\text{ mm}]$.
   - Testing showed that a center slot crowded the clasp and was redundant with the two thirds stations.
   - The center slot was omitted, leaving the closure catch 100% solid and continuous. Two stations at **$Y = \pm 12.87\text{ mm}$** create three equal **$24.53\text{ mm}$** compartments.

## 4. Final Standard Specifications

- **Cassette Body Envelope:** $38.60 \times 80.00 \times 32.80\text{ mm}$ ($36.0\text{ mm}$ closed height).
- **Usable Cavity:** $32.30\text{ mm}$ width $\times 76.00\text{ mm}$ length $\times 30.80\text{ mm}$ depth.
- **Divider Stations:** $Y = \pm 12.87\text{ mm}$ (3 equal $24.53\text{ mm}$ compartments).
- **Slot Geometry:** $1.40\text{ mm}$ slot width, $0.60\text{ mm}$ wall recess, $0.60\text{ mm}$ floor groove.
- **Divider Card:** $33.30 \times 31.20 \times 1.20\text{ mm}$ with top finger notch ($10 \times 1.5\text{ mm}$) and $0.6\text{ mm}$ bottom corner lead-ins ($0.20\text{ mm}$ lid clearance).
- **STL Audits:**
  - `cassette_body_v0_8_divided.stl`: 476 triangles, **0 boundary / 0 non-manifold edges**.
  - `divider_card_full_1_2mm.stl`: 48 triangles, **0 boundary / 0 non-manifold edges**.

## 5. Physical Validation & Status

The full-size divided body and divider cards were 3D printed in PETG and physically verified: straight drop-in insertion, positive retention, and smooth lid closure were confirmed. Plan 003 is complete and ready for integration into the production candidate release in **Plan 004**.

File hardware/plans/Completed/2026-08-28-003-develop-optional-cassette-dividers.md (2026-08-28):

# Plan 003 — Develop optional cassette dividers

- Status: Complete
- Depends on: Early concept/coupon work may use the v0.6 cavity; final divider geometry requires Plan 002 verified height and internal cavity
- Created: 2026-08-27
- Started: 2026-08-28
- Completed: 2026-08-28
- Git start: `ac102ce`
- Git completion: `main` (Plan 003 completion commit)

## Outcome

Provide removable divider configurations for one, two, or three equal cassette
compartments while minimizing transfer of very small parts when a closed
cassette rolls over.

## Requirements

- Support zero dividers or two equally spaced dividers (creating three equal compartments).
- Positively locate dividers at the floor and side walls so they cannot become
  loose inside a closed cassette.
- Minimize transfer gaps at the floor, walls, and closed-lid interface; complete
  isolation is explicitly not required.
- Permit removal without damaging the body, lid, glass, or divider.
- Avoid interference with the hinge, latch, glass pocket, retainer, label area,
  fingernail relief, and cassette removal features.
- Provide straight-line vertical drop-in clearance past the hinge knuckle without tilting.
- Establish a divider interface that can be repeated or scaled consistently in
  larger cassette sizes.

## Non-goals

- Do not create sealed or liquid-tight compartments.
- Do not change the outer cassette or carrier envelope solely to fit dividers.
- Do not require supports trapped inside divider slots.

## Reusable parts and compatibility

- The verified v0.8/v0.7 lid, glass pane, 1.75 mm filament pin, and 3 × 4 7U carrier trays remain 100% reusable with the divided cassette body.
- Retain an undivided configuration when dividers are omitted (smooth floor and recessed wall channels maintain full usable volume).
- Existing v0.6/v0.8 bodies remain valid undivided cassettes even if they cannot accept the new removable dividers.

## Implementation steps and test prints

1. [x] Measure the Plan 002 printed cavity ($34.60\text{ mm}$ width, $76.00\text{ mm}$ length, $30.80\text{ mm}$ usable depth) and closed lid-to-floor relationship at the proposed divider stations.
2. [x] Select representative small test parts and record their dimensions so rollover results are reproducible.
3. [x] Compare locating concepts (recessed wall channels and floor groove selected to maintain smooth cavity walls when dividers are omitted).
4. [x] Generate a compact divider-fit coupon containing the real floor, both side-wall interfaces, lid-side clearance, and a ladder of named tolerances ($1.30, 1.40, 1.50, 1.60\text{ mm}$).
5. [x] Print the coupon and test insertion, retention, removal, floor gaps, wall gaps, deformation, and rattling. *(Coupon result: 1.2 mm card in Station 2 [1.40 mm slot] preferred by physical tactile test).*
6. [x] Generate full-width test bodies using equal cavity spacing measured between the functional divider faces.
7. [x] Audit the exported body and divider STLs, including slot support, minimum wall thickness, floating islands, manifold edges, and closed-envelope compatibility.
8. [x] Thickened left hinge wall to $4.30\text{ mm}$ ($X = -15.00\text{ mm}$) to provide $+0.65\text{ mm}$ straight vertical drop-in clearance past the hinge knuckle and eliminate 80 mm wall flex.
9. [x] Omit center 1-divider slot for simplicity and complete clearance of the right-wall closure catch tab.
10. [x] Physically test full-size v0.8 divided cassette body with baseline 1.20 mm divider cards; confirm tactile sliding fit, straight drop-in, and positive seating.
11. [x] Reconcile all documentation, generate multi-view CAD sheets, update AGENTS.md and README.md, and archive Plan 003.

## Acceptance criteria

- [x] Two dividers create three equal usable compartments ($24.53\text{ mm}$ each) within documented print tolerance.
- [x] Dividers remain located during normal handling and rollover.
- [x] Observed transfer is limited and documented; no claim of complete isolation is made.
- [x] No divider contacts or applies force to the installed glass ($0.20\text{ mm}$ nominal lid clearance).
- [x] The hinge, latch, label, fingernail opening, and carrier fit remain 100% usable.
- [x] Divider installation/removal does not require destructive flexing or tools likely to contact the glass.
- [x] All printable files pass the complete exported-STL audit (0 boundary edges, 0 non-manifold edges).

## Validation record

### Physical Full-Size Body Validation — 2026-08-28

- **Test Article:** `cassette_body_v0_8_divided.stl` and `divider_card_full_1_2mm.stl` printed in PETG.
- **Physical Finding:** The full-size divided cassette body and 1.20 mm cards work well at this scale. The straight vertical drop-in, sliding fit in the $1.40\text{ mm}$ slots, floor groove seating, and lid/clasp interactions are physically verified.
- **Center Slot Decision:** The center slot is omitted from the production layout as it is too close to the two side stations to provide meaningful utility and would crowd the closure clasp. The two thirds stations at $Y = \pm 12.87\text{ mm}$ are frozen for the smallest cassette standard.

### Full-Size Body Geometry Standard — 2026-08-28

- **Directory:** `Cassettes/divider_test_cassette_v0_8/`
- **Body Dimensions:** $38.60 \times 80.00 \times 32.80\text{ mm}$ ($36.0\text{ mm}$ closed height).
- **Thickened Left Wall:** $4.30\text{ mm}$ thickness (inner face at $X = -15.00\text{ mm}$), providing **$+0.65\text{ mm}$ straight vertical drop-in clearance** past the hinge knuckle ($X = -16.15\text{ mm}$) and high structural rigidity.
- **Right Wall:** $2.00\text{ mm}$ thickness (inner face at $X = +17.30\text{ mm}$) with continuous, uncut closure catch profile at $Y \in [-4.00, +4.00\text{ mm}]$.
- **Usable Cavity:** $32.30\text{ mm}$ width $\times 76.00\text{ mm}$ length $\times 30.80\text{ mm}$ depth.
- **Divider Stations:** $Y = \pm 12.87\text{ mm}$ (3 equal $24.53\text{ mm}$ compartments).
- **Slot Cross-Section:** $1.40\text{ mm}$ width, $0.60\text{ mm}$ wall recess, $0.60\text{ mm}$ floor groove.
- **Divider Card:** $33.30\text{ mm}$ width $\times 31.20\text{ mm}$ height $\times 1.20\text{ mm}$ thickness with top finger notch ($10 \times 1.5\text{ mm}$) and $0.6\text{ mm}$ bottom lead-in chamfers.
- **STL Audits:**
  - `cassette_body_v0_8_divided.stl`: 476 triangles, 0 boundary edges, 0 non-manifold edges, 0 degenerate triangles.
  - `divider_card_full_1_2mm.stl`: 48 triangles, 0 boundary edges, 0 non-manifold edges, 0 degenerate triangles.

### Physical Divider Coupon Fit Test — 2026-08-28

- **Test Article:** `divider_slot_coupon.stl` and `divider_card_1_2mm.stl` printed in PETG.
- **Physical Finding:** The **1.20 mm card in Station 2 (1.40 mm slot, +0.20 mm clearance)** is the preferred fit for insertion, smooth sliding, and positive seating without binding.

### Divider Coupon Architecture — 2026-08-28

- **Coupon Directory:** `Cassettes/divider_fit_coupon_v0_1/`
- **Slot Width Ladder (on 1.20 mm test card):**
  - Station 1 ($Y = -12.0\text{ mm}$): $1.30\text{ mm}$ slot width ($+0.10\text{ mm}$ clearance)
  - Station 2 ($Y = -4.0\text{ mm}$): $1.40\text{ mm}$ slot width ($+0.20\text{ mm}$ clearance) — **PHYSICALLY SELECTED**
  - Station 3 ($Y = +4.0\text{ mm}$): $1.50\text{ mm}$ slot width ($+0.30\text{ mm}$ clearance)
  - Station 4 ($Y = +12.0\text{ mm}$): $1.60\text{ mm}$ slot width ($+0.40\text{ mm}$ clearance)
- **Recess Depths:** $0.60\text{ mm}$ wall recess, $0.60\text{ mm}$ floor groove.
- **STL Audits:**
  - `divider_slot_coupon.stl`: 240 triangles, 0 boundary edges, 0 non-manifold edges, 0 degenerate triangles.
  - `divider_card_1_2mm.stl`: 24 triangles, 0 boundary edges, 0 non-manifold edges, 0 degenerate triangles.

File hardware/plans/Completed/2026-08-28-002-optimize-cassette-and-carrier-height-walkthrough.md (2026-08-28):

# Plan 002 Walkthrough — Optimize Cassette and Carrier Height

- Plan: `Plans/Completed/2026-08-28-002-optimize-cassette-and-carrier-height.md`
- Completed: 2026-08-28
- Outcome: **Physically Verified and Accepted**

## 1. Executive Summary

Plan 002 optimized the vertical height of the modular small-parts cassette to maximize internal hardware storage volume while maintaining strict non-interference clearance below the upper carrier tray's downward-protruding Gridfinity feet.

The physical test confirmed:
1. The **v0.8 body** ($32.80\text{ mm}$ body height, $36.00\text{ mm}$ closed cassette height) fits cleanly inside the 3 × 4 × 7U carrier tray with positive non-interference clearance below the upper carrier's Gridfinity feet.
2. Usable cavity depth increased from $22.80\text{ mm}$ (v0.7 baseline) to **$30.80\text{ mm}$ (+35.1% capacity gain)**.
3. The lid remains 100% backwards-compatible: existing printed v0.7 lids, glass slides, 6.75 mm compliant PETG latches, and 1.75 mm filament hinge pins mate directly with the v0.8 body.
4. The $36.00\text{ mm}$ closed height ($32.80\text{ mm}$ body height) is frozen as the system vertical standard for all 1U cassette models.

## 2. Complete Vertical Tolerance Budget

| Datum / Feature | Z Height | Delta / Role |
|---|---:|---|
| Drawer Ceiling Datum | $111.125\text{ mm}$ | Measured absolute ceiling ($4\text{ }^3/_8\text{ in}$) |
| Top of Upper Carrier Lip | $102.40\text{ mm}$ | $+8.725\text{ mm}$ drawer headroom |
| Upper Carrier Stacking Lip Shelf | $49.00\text{ mm}$ | Standard 7U engaged height plane |
| Lowest Surface of Upper Carrier Feet | $44.25\text{ mm}$ | Feet protrude $4.75\text{ mm}$ below shelf |
| Top of Closed v0.8 Cassette Lid | $42.75\text{ mm}$ | $+1.50\text{ mm}$ safe foot non-interference buffer |
| Cassette Split-Line Rim | $39.55\text{ mm}$ | $3.20\text{ mm}$ lid thickness |
| Cassette Inside Floor | $8.75\text{ mm}$ | $30.80\text{ mm}$ usable cavity depth (+35.1% volume) |
| Lower Carrier Support Floor Datum | $6.75\text{ mm}$ | $2.00\text{ mm}$ cassette bottom floor |
| Baseplate Datum | $0.00\text{ mm}$ | $6.75\text{ mm}$ carrier base & floor |

## 3. Physical Validation Results

- **Component:** `Cassettes/glass_slide_cassette_40x80/build/cassette_body_v0_8.stl` printed in PETG.
- **Assembly:** Paired with physically verified v0.7/v0.8 PETG lid, 1.15 mm microscope slide glass, and 1.75 mm filament hinge pin.
- **Fit & Stacking:** Installed into the lower 3 × 4 carrier tray; upper carrier tray placed on top. The upper tray seated completely on the lower tray's lip shelf without any contact or binding against the cassette.

## 4. Released Component Inventory

- Printable Body STL: `Cassettes/glass_slide_cassette_40x80/build/cassette_body_v0_8.stl` (376 triangles, 0 boundary edges, 0 non-manifold edges)
- Printable Lid STL: `Cassettes/glass_slide_cassette_40x80/build/cassette_lid_v0_8_print.stl` (780 triangles, 0 boundary edges, 0 non-manifold edges)
- Component README: `Cassettes/glass_slide_cassette_40x80/README.md`

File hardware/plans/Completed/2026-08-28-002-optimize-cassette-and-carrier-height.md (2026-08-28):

# Plan 002 — Optimize cassette and carrier height

- Status: Complete
- Depends on: Plan 001 physical measurements and Plan 009 verified lid/capture envelope
- Created: 2026-08-27
- Started: 2026-08-27
- Completed: 2026-08-28
- Git start: `e13dfba`
- Git completion: `main` (Plan 002 completion commit)

## Outcome

Establish the physically supported vertical design standard and use it to
increase cassette capacity without violating the 7U carrier engagement plane,
the 14U drawer stack, or practical handling clearance.

## Requirements

- Treat 111.125 mm as the absolute measured drawer ceiling.
- Preserve 7 mm Gridfinity height increments and the selected base/lip profile.
- Include the support floor, print variation, labels, hinge, latch, glass, and
  removal motion in the usable-height calculation.
- Keep every cassette feature below the carrier stacking engagement plane and upper tray feet.
- Retain 2.0 mm cassette walls and floor unless a tested revision explicitly
  documents a stronger requirement.
- Preserve the microscope-slide standard, 1.75 mm hinge pin, label format, and
  verified v0.6 hinge principles.

## Non-goals

- Do not change the cassette XY sub-grid in this plan.
- Do not develop dividers or larger cassette footprints.
- Do not claim that the tallest modeled cassette is usable without a print.

## Reusable parts and compatibility

- Reuse the Plan 009 verified lid/capture interface and successful v0.6 hinge
  components. The v0.8 height increase is confined to the body, making the v0.7 lid 100% reusable.
- Preserve the tested Plan 001 carriers.
- Version changed body as v0.8.

## Implementation steps and test prints

1. [x] Import Plan 001 measurements for engaged height, support-floor height,
   lip seating, drawer clearance, warping, and loaded behavior.
2. [x] Define the vertical tolerance budget, including a named practical drawer
   clearance, carrier foot depth, and cassette-to-engagement-plane clearance.
3. [x] Generate a low-material stepped height gauge reproducing the actual
   carrier floor and stacking plane, with clearly labeled candidate cassette
   heights.
4. [x] Measure carrier foot protrusion (4.75 mm downward from lip shelf) and calculate exact upper foot datum (Z = 44.25 mm).
5. [x] Generate a body-height coupon / full model using the selected wall, floor, hinge-side
   attachment, and latch-side geometry in the full print orientation.
6. [x] Print the v0.8 body and check wall quality, hinge/latch attachment support,
   dimensional accuracy, and fit in a loaded carrier.
7. [x] Create a versioned optimized-height cassette body and assembly reference.
8. [x] Audit the exported STL for topology, integrity, envelope, hinge/latch
   clearances, unsupported starts, and engagement-plane clearance.
9. [x] Assemble v0.8 body with verified v0.7/v0.8 lid and test closure, handling, and carrier stacking.
10. [x] Physically test two-tray 14U stack loaded with v0.8 cassette in target drawer; verify upper carrier seats fully with clearance under feet.
11. [x] Record measurements, settings, reusable components, and the selected vertical standard in release notes and manifest.

## Acceptance criteria

- [x] The selected cassette height has a documented tolerance budget rather
  than relying on nominal subtraction.
- [x] The complete cassette closes and operates without altered slicer scale.
- [x] The upper loaded carrier seats fully without cassette contact under Gridfinity feet.
- [x] The 14U loaded stack fits the drawer with the practical clearance defined
  from Plan 001 evidence.
- [x] The height increase produces useful internal capacity (+35.1% volume gain) and does not make
  cassette removal materially worse.
- [x] All printable STLs pass binary, finite-coordinate, degenerate-triangle,
  boundary-edge, and non-manifold-edge audits.
- [x] Physical results distinguish the tested material/settings from untested
  alternatives.

## Validation record

### Vertical Tolerance Budget & Upper Tray Foot Clearance — 2026-08-28

- **Measured Drawer Ceiling:** 111.125 mm (4 3/8 in).
- **14U Stack Engagement Height (Two 7U carriers):** 49.00 + 53.40 = 102.40 mm.
- **Stack-to-Drawer Ceiling Margin:** 111.125 - 102.40 = 8.725 mm.
- **Carrier Internal Vertical Cavity:** Carrier support floor at Z = 6.75 mm, stacking plane at Z = 49.00 mm.
- **Upper Tray Gridfinity Feet Protrusion:** The 3 × 4 array of feet extends 4.75 mm downward below the 49.00 mm lip shelf into the lower tray's throat cavity -> lowest surface of upper tray sits at Z = 44.25 mm.
- **Total Usable Internal Space:** 44.25 mm - 6.75 mm = 37.50 mm.
- **Selected Closed Cassette Height:** 36.00 mm (`BODY_H = 32.80 mm`, `LID_H = 3.20 mm`).
- **Internal Usable Cavity Depth:** 30.80 mm (2.0 mm floor) vs. baseline 22.80 mm (+35.1% capacity increase).
- **Stacking Non-Interference Buffer:** 37.50 - 36.00 = 1.50 mm safe clearance below the upper carrier feet (accounting for 0.15 mm label tape and print layer variations).

### Physical Test Outcome — 2026-08-28

- Printed `cassette_body_v0_8.stl` in PETG.
- Assembled with existing v0.7/v0.8 lid and glass slide.
- Installed in lower 3 × 4 carrier tray and stacked upper carrier tray on top.
- Confirmed: Upper tray seats completely with clean clearance under its Gridfinity feet. Height standard is physically verified and frozen at 36.00 mm closed height (32.80 mm body).

### Exported v0.8 STL Audit — 2026-08-28

- `cassette_body_v0_8.stl`: 39.55 × 80.0 × 35.45 mm (nominal 38.6 × 80.0 × 32.8 mm), 376 triangles, 0 boundary edges, 0 non-manifold edges, 0 degenerate triangles, finite coordinates.
- `cassette_lid_v0_8_print.stl`: 39.55 × 80.0 × 6.5 mm, 780 triangles, 0 boundary edges, 0 non-manifold edges, 0 degenerate triangles, fully connected shell overlap graph.
- `REFERENCE_closed_assembly_DO_NOT_PRINT.stl`: 39.55 × 80.0 × 36.0 mm, 1168 triangles, 0 boundary edges, 0 non-manifold edges, 0 degenerate triangles.

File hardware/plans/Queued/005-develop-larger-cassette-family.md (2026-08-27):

# Plan 005 — Develop the larger cassette family

- Status: Queued
- Depends on: Plan 004 verified smallest-module baseline
- Created: 2026-08-27
- Started: Not started
- Completed: Not completed
- Git start: Not committed
- Git completion: Not completed

## Outcome

Develop a deliberately limited family of larger, individually closed cassettes
using integer multiples of the verified cassette sub-grid and the same carrier,
window, label, closure, and divider principles.

## Requirements

- Select sizes from demonstrated hardware-volume needs and useful carrier mixes.
- Use integer multiples of the verified cassette sub-grid; do not enlarge parts
  merely to align them to a 42 mm Gridfinity cell.
- Maintain a consistent external clearance convention across the family.
- Support removable dividers that create equal partitions and minimize small-
  part transfer during rollover.
- Use one or more standard microscope-slide window modules without press fits.
- Keep hinge access, latch access, labels, and all features below the carrier
  engagement plane.

## Non-goals

- Do not attempt every mathematically possible sub-grid multiple.
- Do not change the verified smallest cassette to simplify larger sizes.
- Do not assume one long hinge or one large glass pane will print or behave like
  the smallest verified components.

## Reusable parts and compatibility

- Reuse the verified hinge profile, pin material, Plan 009 pane-capture strategy,
  label tape, divider interface, and carrier datums when their tested spans
  permit.
- Prefer repeated standard window or hinge modules over untested long spans.
- Mark every new size provisional until its own complete print passes.

## Implementation steps and test prints

1. [ ] Inventory representative stored hardware and select the smallest useful
   set of larger module footprints and target volumes.
2. [ ] Produce a packing matrix showing each proposed cassette in verified and
   prospective carrier throats with real inter-cassette clearance.
3. [ ] Define per-size window count, hinge-knuckle arrangement, latch count,
   divider stations, label zones, and removal access.
4. [ ] Generate size-specific fit coupons for hinge spans, latch regions,
   divider interfaces, glass pockets/retainers, and carrier throat clearance.
5. [ ] Print and validate coupons for the first proposed size; revise named
   tolerances instead of scaling parts.
6. [ ] Generate and audit one complete cassette of that size, including opening
   sweep, pin containment, glass capture, divider clearance, islands, topology,
   and closed envelope.
7. [ ] Print, assemble, load, and test the complete cassette for hinge/latch
   operation, divider transfer, glass security, removal, rollover, and stacking.
8. [ ] Repeat steps 4–7 independently for each additional selected size; do not
   infer physical success from another footprint.
9. [ ] Print a representative mixed group and verify that the family shares a
   consistent sub-grid and clearance convention.
10. [ ] Publish a compatibility matrix covering bodies, lids, retainers,
    dividers, pins, windows, and carrier layouts.

## Acceptance criteria

- [ ] Every released size occupies an integer sub-grid multiple and participates
  in at least one useful carrier layout.
- [ ] Each size has its own successful coupon and complete physical print.
- [ ] Windows are mechanically captured without forcing glass.
- [ ] Hinges and latches operate throughout their required range without support
  trapped in functional voids.
- [ ] Divider configurations remain installed and have documented rollover
  transfer results.
- [ ] All features remain below the appropriate carrier engagement plane.
- [ ] Every printable STL passes the full exported-artifact audit.

## Validation record

Maintain a per-size table of dimensions, material/settings, coupon results,
complete-print measurements, cycle tests, rollover transfers, compatible layouts,
and verified versus provisional components.

## Stop and rollback conditions

- Remove a proposed size from this plan if it lacks a useful carrier layout or
  requires an incompatible interface solely for extra volume.
- Split an unexpectedly complex size into a later idea rather than holding the
  entire family plan open indefinitely.

## Archive handoff

The walkthrough must explain the selected family, rejected sizes, sub-grid
math, per-size test evidence, shared parts, unique parts, and mixing rules.

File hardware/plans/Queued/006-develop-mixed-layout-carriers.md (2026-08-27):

# Plan 006 — Develop mixed-layout carriers

- Status: Queued
- Depends on: Plan 005 verified cassette-family envelopes
- Created: 2026-08-27
- Started: Not started
- Completed: Not completed
- Git start: Not committed
- Git completion: Not completed

## Outcome

Create a small, useful carrier family that organizes verified cassette-size
combinations while remaining stackable, Gridfinity compatible, removable from
the drawer, and safe for the glass windows.

## Requirements

- Base footprints on the 42 mm Gridfinity pitch and verified base/lip profile.
- Calculate layouts against each carrier's narrowest measured or authoritative
  stacking-lip throat.
- Maintain at least 2.0 mm printed walls and real insertion clearance.
- Keep every cassette feature below the stacking engagement plane.
- Provide fingertip or equivalent removal access without prying on glass.
- Prefer fewer than ten cassettes per carrier when practical while allowing
  dense layouts where part size or packing clearly benefits.

## Non-goals

- Do not create a unique carrier for every possible cassette permutation.
- Do not reduce walls or use zero-clearance packing to rescue a layout.
- Do not alter cassette envelopes in this plan.

## Reusable parts and compatibility

- Preserve the verified 3 × 4 six-smallest-cassette carrier as the baseline.
- Reuse the verified 7U vertical architecture unless a specific cassette family
  member has an already documented height requirement.
- Keep carriers mutually stackable regardless of their internal layout.

## Implementation steps and test prints

1. [ ] Rank mixed layouts by real storage use, cassette count, wasted throat
   area, removal access, and compatibility with drawer footprints.
2. [ ] Select the minimum carrier set that covers the valuable combinations.
3. [ ] Calculate exact packed envelopes, inter-cassette gaps, throat clearances,
   wall thicknesses, and engagement-plane clearance for each layout.
4. [ ] Generate shallow throat/packing coupons with the actual corner and access
   geometry for every selected layout.
5. [ ] Print coupons and insert the complete physical cassette mix; record
   binding, rattle, orientation errors, and removal behavior.
6. [ ] Revise named clearances and generate one full carrier for the first layout.
7. [ ] Audit its STL for profile, topology, coordinates, degenerates, islands,
   throat dimensions, floor support, walls, and stacking envelope.
8. [ ] Print the full carrier, load it, stack it above and below the baseline
   carrier, and test handling and drawer clearance.
9. [ ] Repeat full generation and testing for each remaining selected layout.
10. [ ] Test deliberately incorrect cassette placements and add simple visual or
    geometric orientation cues only where they prevent plausible misuse.
11. [ ] Publish layout diagrams and a compatibility table.

## Acceptance criteria

- [ ] Every released layout has a successful packing coupon and full loaded print.
- [ ] All intended cassettes insert and remove without glass loading.
- [ ] No unintended orientation appears to fit while preventing stacking or
  damaging a functional feature.
- [ ] Mixed carriers stack with the baseline in both orders and remain engaged
  during normal handling.
- [ ] Loaded stacks fit the drawer with the verified practical clearance.
- [ ] All printed walls meet the 2.0 mm minimum and all STLs pass their audits.

## Validation record

Record each layout, physical cassette identities, measured gaps, material and
settings, stack order, drawer measurements, access observations, failures, and
final compatibility classification.

## Stop and rollback conditions

- Reject layouts that require fragile wall sections, glass contact, awkward
  removal, or ambiguous cassette orientation.
- Keep low-value mathematical permutations documented but unreleased.

## Archive handoff

The walkthrough must show each released layout, supported combinations, stacking
tests, removal method, packing clearances, and which layouts were rejected.

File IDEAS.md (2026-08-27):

# Ideas

This is the project inbox. Each idea must be no more than three sentences and
must describe the desired outcome rather than a complete implementation.

When an idea is selected, remove it from this file and develop it into the next
numbered plan in `Plans/`. Only one numbered plan may be active at a time.

## Inbox

No unprocessed ideas currently recorded.

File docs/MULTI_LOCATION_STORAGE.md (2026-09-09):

# Multi-Location Inventory Allocation & Bulk Overstock Management

## 1. Overview & Storage Philosophy

The **Parts-Database** workshop inventory platform supports tiered physical storage architectures. High-frequency assembly workflows demand immediate accessibility at the workbench, whereas large bulk orders (such as 500-pack or 1000-pack fastener boxes) occupy significant physical volume that should not consume prime benchtop real estate.

To solve this, inventory is partitioned across two primary operational tiers:

```mermaid
flowchart TD
    subgraph Ingress["Incoming Bulk Orders / Restock"]
        Box["500-Pack / 1000-Pack Fastener Box"]
    end

    subgraph DeepStorage["Drawer 06: Bulk Overstock (BULK_RESERVE)"]
        BulkBin["High-Capacity Bulk Bin / Tub<br/>(e.g., BIN-080 · 500 pcs)"]
    end

    subgraph Workbench["Drawer 01: Benchtop Cassette (PRIMARY)"]
        PrimaryBin["14U Modular Gridfinity Cassette<br/>(e.g., BIN-001 · 25 pcs)"]
    end

    subgraph Workstation["Active Fabrication / Assembly"]
        Assembly["3D Printer / CNC Assembly Bench"]
    end

    Box -->|"Initial Ingest"| BulkBin
    BulkBin -->|"POST /api/inventory/transfer<br/>(Restock Transfer)"| PrimaryBin
    PrimaryBin -->|"Consume Fasteners"| Assembly
    PrimaryBin -.->|"Low Stock Alert Triggered"| BulkBin
```

---

## 2. Storage Roles & Tiers

Each physical compartment in the database is tagged with an operational `storage_role`:

| Storage Role | Typical Location | Description | Restock Behavior |
| :--- | :--- | :--- | :--- |
| **`PRIMARY`** | Benchtop Gridfinity Drawers (`DRAWER-01`) | Fast-access modular slide cassette bins immediately within arm's reach. | Generates low-stock replenishment alert when $Q \le \text{reorder\_threshold}$. |
| **`BULK_RESERVE`** | Deep Workshop Drawers (`DRAWER-06`) | High-capacity bulk tubs, original manufacturer packaging, or deep storage bins. | Acts as replenishment source for `PRIMARY` bins. |
| **`OVERFLOW`** | Auxiliary Storage Shelves / Staging | Overflow inventory when bulk capacity is exceeded or staging for upcoming builds. | Acts as secondary replenishment source. |

---

## 3. Inventory Aggregation & Technical Views

When browsing the Fastener Catalog or viewing an individual part's specifications:

1. **Total Stock on Hand**: $Q_{\text{total}} = Q_{\text{primary}} + Q_{\text{bulk}} + Q_{\text{overflow}}$
2. **Primary Working Stock**: $Q_{\text{primary}} = \sum_{c \in \text{PRIMARY}} c.q$
3. **Bulk Reserve Stock**: $Q_{\text{bulk}} = \sum_{c \in \text{BULK\_RESERVE}} c.q$

### API Representation (`GET /api/parts/{part_id}`)
```json
{
  "id": "M3-12mm-SHCS",
  "name": "M3 × 12 mm Socket Head Cap Screw",
  "primary_quantity": 25,
  "bulk_quantity": 480,
  "total_quantity": 505,
  "compartments": [
    {
      "id": "BIN-002-C1",
      "bin_id": "BIN-002",
      "storage_role": "PRIMARY",
      "quantity_on_hand": 25,
      "reorder_threshold": 10,
      "location_name": "Modular Fastener Drawer 01",
      "location_tier": "PRIMARY_BENCH"
    },
    {
      "id": "BIN-081-C1",
      "bin_id": "BIN-081",
      "storage_role": "BULK_RESERVE",
      "quantity_on_hand": 480,
      "reorder_threshold": 50,
      "location_name": "Deep Storage Drawer 06",
      "location_tier": "BULK_OVERSTOCK"
    }
  ]
}
```

---

## 4. Atomic Stock Transfer Workflow

When primary benchtop inventory runs low, technicians can transfer stock from bulk storage into the primary cassette without manual math:

### API Endpoint: `POST /api/inventory/transfer`

**Request Payload**:
```json
{
  "from_compartment_id": "BIN-081-C1",
  "to_compartment_id": "BIN-002-C1",
  "quantity": 25,
  "reason": "Restock primary bench bin from bulk overstock"
}
```

**Validation Rules**:
1. **Quantity Gating**: $Q_{\text{transfer}} > 0$.
2. **Source Balance Gating**: $Q_{\text{source}} \ge Q_{\text{transfer}}$.
3. **Part Compatibility**: `from_comp.part_id` must match `to_comp.part_id` (or target compartment must be unassigned, in which case the part assignment is inherited).
4. **Audit Logging**: Every transfer is permanently committed to `stock_transfer_logs` with a unique UUID, timestamp, and reason.

---

## 5. Automated Replenishment Alerts

The dashboard monitors all `PRIMARY` compartments in real-time. When a compartment falls below its `reorder_threshold` and there exists stock in a `BULK_RESERVE` or `OVERFLOW` compartment for the same part, a **Restock Required** alert card is displayed on the dashboard:

- **Endpoint**: `GET /api/inventory/replenish-alerts`
- **Dashboard Widget**: Lists low primary bins alongside available bulk source locations and provides a 1-click **Restock →** shortcut to execute the transfer.

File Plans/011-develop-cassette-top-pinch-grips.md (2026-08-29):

# Plan 011 — Develop cassette top-surface pinch grips

- Status: Executing
- Depends on: Plans 001–003, 009, 010 completed
- Created: 2026-08-28
- Started: 2026-08-29
- Completed: Not completed
- Git start: `845f42c`
- Git completion: Not completed

## Outcome

Design and integrate low-profile, ergonomic top-surface pinch grips directly onto the
solid roof zones of the cassette lid. This enables effortless, reliable one-handed
vertical extraction of cassettes from tightly packed carrier trays from directly above,
without requiring lateral finger clearance between adjacent cassettes, without loading
or touching the glass, and while remaining strictly within the carrier stacking clearance envelope.

## Requirements

- Implement positive top-surface pinch features on the two solid roof zones of the lid:
  1. **Entry End Roof:** $Y \in [-39.5, -34.5\text{ mm}]$ (flanking the slide entry slot).
  2. **Label End Roof:** $Y \in [33.0, 38.0\text{ mm}]$ (adjacent to the 34 × 10 mm label zone).
- Keep pull feature height low-profile: $\le 1.00\text{ mm}$ above the $Z = 3.20\text{ mm}$ lid top surface.
  - Inside the carrier, cassette bottom sits at $Z = 6.75\text{ mm}$, giving a maximum top feature height of $Z = 6.75 + 3.20 + 32.80 + 1.00 = 43.75\text{ mm}$.
  - This preserves $\ge \mathbf{+0.50\text{ mm}}$ of clear vertical air below the lowest Gridfinity feet of an upper stacked carrier tray ($Z = 44.25\text{ mm}$).
- Ensure support-free FDM 3D printing in PETG:
  - Since the lid prints top-face-down on the build plate (print $Z = 0$), design the top pinch grips with $45^\circ$ draft chamfers or as bed-level textured grip flutes that print cleanly without support.
- Eliminate external body end protrusions:
  - Remove the legacy $+0.40\text{ mm}$ horizontal body end ribs to keep the body ends flat at $80.00\text{ mm}$ overall length, restoring the full $\approx 2.30\text{ mm}$ lateral clearance in $Y$ across the carrier throat and preventing inter-row binding.
- Preserve all existing verified functional interfaces:
  - 34 × 10 mm Brother TZe label zone.
  - 23.0 × 58.5 mm visible glass aperture.
  - $27.0 \times 1.4\text{ mm}$ end-loaded slide channel and 6.75 mm compliant PETG pane latch.
  - 3-knuckle 1.75 mm filament hinge.
  - $0.85\text{ mm}$ undercut closure clasp.

## Non-goals

- Do not modify the Gridfinity 3 × 4 carrier tray walls or stacking lip.
- Do not alter the microscope-slide glass dimensions.
- Do not require tools, picks, or prying against the glass for extraction.

## Reusable parts and compatibility

- The v0.8 divided cassette bodies (`cassette_body_v0_8_divided.stl`), 3 × 4 7U carrier trays, glass slide panes, hinge pins, and divider cards remain 100% compatible.
- Upgrading to top pinch grips requires reprinting only the lid (`cassette_lid_v0_8_print.stl`), minimizing reprint time and material.

## Implementation steps

1. [ ] **Top-Pinch Geometry Design:** Model candidate top-surface pinch grip profiles in `generate_cassette.py` on the solid entry and label roof areas (evaluating transverse serrated grip ribs and recessed fingernail ledges with $45^\circ$ bed draft).
2. [ ] **Body End Clearance Cleanup:** Remove the $+0.40\text{ mm}$ protruding end ribs from `build_body()` and `build_divided_body()` to ensure flat $80.0\text{ mm}$ end walls.
3. [ ] **STL Export & Mesh Audit:** Generate and audit updated STLs for 0 boundary edges and 0 non-manifold edges.
4. [ ] **Print Test Lids:** Print test lids in PETG (top-face-down) and verify first-layer bed adhesion, grip sharpness, and smooth hinge/clasp action.
5. [ ] **Packed Carrier Extraction Test:** Load a 3 × 4 carrier with 6 cassettes; test thumb-and-forefinger extraction from center and edge positions. Verify zero binding and effortless lifting.
6. [ ] **Stacking Clearance Verification:** Stack a loaded upper 7U carrier tray on top; measure and confirm non-interference below the upper tray feet.
7. [ ] **Documentation & Archive:** Update READMEs, manifests, CAD drawings, and archive Plan 011 with its walkthrough narrative.

## Acceptance criteria

- [ ] Cassettes can be extracted easily with one hand from any position in a packed carrier using only the top-surface pinch grips.
- [ ] No feature contacts or applies force to the glass during extraction.
- [ ] Body ends are flat with zero inter-row binding in the carrier tray.
- [ ] Upper carrier tray stacks fully with $\ge +0.50\text{ mm}$ clearance below its Gridfinity feet.
- [ ] All exported STLs pass topological mesh audit (0 boundary edges, 0 non-manifold edges).
- [ ] Release documentation unambiguously identifies print settings and compatibility.

## Validation record

Record measurements, print settings, tactile extraction findings, and stacking clearances here during execution.

## Stop and rollback conditions

- If top grip features exceed the $Z = 44.25\text{ mm}$ upper carrier foot clearance limit or interfere with tray stacking, reduce feature height immediately.
- If top grip features impair top-face-down print bed adhesion, adjust draft angles.

## Archive handoff

The walkthrough must document the top grip geometry, extraction ergonomic evaluation, and verified stacking clearance budget.

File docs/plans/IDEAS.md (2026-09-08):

# Parts-Database Idea Backlog & Design Intake

Persistent asynchronous backlog for database schema design, QR code generation, physical bin tagging, and inventory API endpoints for **Parts-Database**.

---

## 1. Master & Cross-Subsystem Backlog (`MNN`)

### [FEATURE] End-to-End QR Fastener Tagging & Camera Scanner Resolution
- **Context**: Need a seamless pipeline connecting vector SVG label generation with QR codes to immediate mobile camera scanning and SQLite record resolution.
- **Proposed Solution**: Standardize QR payload format (e.g. `https://parts.local/b/<bin_uuid>` or `PARTS:<id>`), inject dynamic QR codes into SVG label sheets, and decode instantly in the web catalog.
- **Status**: Prioritized for follow-up after Plan M01.

---

## 2. Server Subsystem Backlog (`SNN`)

### [FEATURE] FastAPI Catalog Server & SQLite Parts Database (`S01`)
- **Context**: Need a fast, lightweight, self-hosted web catalog to query fastener specs, thread pitches, quantities on hand, and bin slot assignments.
- **Proposed Solution**: FastAPI backend, SQLite WAL storage, Jinja2/Tailwind templates, and mobile-first responsive layout.
- **Status**: Queued for S01.

### [FEATURE] Camera QR Barcode Scanner (`S02`)
- **Context**: Scanning bin QR codes directly from a phone browser without installing a native app.
- **Proposed Solution**: Integrated HTML5 QR scanner using WebRTC / `html5-qrcode` library pointing to `/scan`.
- **Status**: Queued for S02.

### [FEATURE] Household Consumables & Fleet Maintenance Inventory Expansion (`S03`)
- **Context**: The database is currently focused on small modular fastener bins. Household maintenance items (HVAC air filters, water filters, LED light bulbs, lawnmower blades) and vehicle maintenance items (motor oil, oil filters, spark plugs, brake pads) require tracking larger items in shelves, cabinets, and closets.
- **Proposed Solution**: Expand schema to support broader location hierarchies (e.g. `Garage Shelf B2`, `Utility Closet Rack`), multi-pack quantities, item specification attributes (e.g. `16x25x1 MERV 11`, `5W-30 Full Synthetic`), and minimum stock reorder thresholds.
- **Status**: Triaged Idea (Backlog)

### [FEATURE] Computer Vision Camera Fastener Counter (Snapshot Piece Counting) (`S04`)
- **Context**: Counting small fasteners (screws, nuts, washers, pins) by hand is slow, and weight scales can suffer from tare/tolerance inaccuracies. Spreading fasteners across a tray or bin and taking a quick smartphone photo provides an instant, auditable count.
- **Proposed Solution**:
  1. Add a camera snapshot / file upload dialog on the restock page.
  2. Process the image using computer vision / contour blob detection (or local vision AI inference) to segment and count individual items.
  3. Overlay detected dot markers / count badges on the image with the calculated count (e.g. "Detected: 48 pieces"), allowing 1-tap manual adjustment before committing to `parts.db`.
- **Status**: Triaged Idea (Backlog)

### [FEATURE] Standardized Batch Label Sheet Generator & Cricut Print-Then-Cut Exporter (`S05`)
- **Context**: Setting up workshop storage requires batch-generating labels for dozens or hundreds of bins at once. The visual format must remain strictly standardized and consistent across all physical media types, whether using pre-cut label templates, continuous thermal tape, or uncut sticker paper cut on a digital crafting cutter.
- **Proposed Solution**:
  1. Define a strict canonical label specification (QR code placement, high-contrast typography, part description, pitch/drive icon, bin coordinate ID).
  2. Implement batch export in the web catalog supporting:
     - **Pre-cut Label Sheets**: Standard Avery templates (e.g. Avery 5160, 5167).
     - **Continuous Thermal Rolls**: Brother QL / Dymo label streams.
     - **Cricut "Print Then Cut"**: Full-sheet SVG/PDF generator with standard registration marks and precision cut-boundary vector paths for kiss-cutting on uncut vinyl/sticker sheets.
- **Status**: Completed & Operational ([`Plan S05`](complete/2026-09-08-S05_standardized_batch_labels_and_cricut_exporter_plan.md)).

---

## 3. Hardware Subsystem Backlog (`HNN`)

### [FEATURE] Mixed-Layout Gridfinity Carriers & Deep Bin Cassettes (`H01`)
- **Context**: Expanding the 3D-printable modular hardware catalog for larger bolts (M8+) and mixed compartment carriers.
- **Proposed Solution**: Parametric OpenSCAD / Build123d generators for 2x2 and 3x3 deep Gridfinity carriers.
- **Status**: Queued in hardware backlog.

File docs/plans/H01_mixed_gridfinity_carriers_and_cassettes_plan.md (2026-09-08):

# Plan H01: Mixed-Layout Gridfinity Carriers & Deep Bin Cassettes

## 1. Goal Description
While standard 1x1, 1x2, and 2x2 Gridfinity bins hold standard M2–M4 screws, larger hardware (M8+ structural bolts, long screws > 50mm, and mixed fastener kits) requires deeper bin cassettes and custom multi-compartment carriers.
This plan expands the 3D parametric CAD generator pipeline:
1. **Parametric OpenSCAD / Build123d Models**: Create parametric models for 2x2, 2x3, and 3x3 deep Gridfinity carriers with reinforced ribs and magnet pockets.
2. **Divided & Mixed Compartment Cassettes**: Support 1/2/3/4 compartment divided cassettes with removable slide lids.
3. **Automated STL & Render Generation**: Integrate into `hardware/scripts/generate_all_renders.py` for automated vector previews and 3D print file generation.

---

## 2. Architecture & Workflow Diagram

```mermaid
flowchart TD
    subgraph CAD["Parametric CAD Pipeline"]
        Script["hardware/cad/generate_deep_bins.py (Build123d / OpenSCAD)"]
        Configs["Bin Configs (Units: 2x3, Height: 12U, Dividers: 3)"]
    end

    subgraph Output["Generated 3D Assets"]
        STL["Exported STL / 3MF Print Files"]
        Previews["Multi-View Orthographic Previews (docs/images/)"]
    end

    subgraph WebCatalog["Web Catalog (:8090)"]
        Catalog["Parts Database STL Download & 3D Viewer"]
    end

    Configs --> Script
    Script --> STL
    Script --> Previews
    STL --> Catalog
```

---

## 3. Code Modifications

### Hardware CAD & Automation Scripts
- `[NEW]` `hardware/cad/generate_deep_bins.py`: Parametric Build123d script generating deep 2x2 and 3x3 Gridfinity carriers and slide-lid cassettes.
- `[MODIFY]` [`hardware/scripts/generate_all_renders.py`](../../hardware/scripts/generate_all_renders.py): Add build targets for large cassettes and carriers.
- `[MODIFY]` [`server/templates/parts.html`](../../server/templates/parts.html): Link 3D STL download buttons for large bins.

### Tests
- `[NEW]` `hardware/tests/test_cad_generation.py`: Unit tests asserting non-empty STL generation and valid geometric bounding boxes.

---

## 4. Test Updates & Specifications

### Test Harness (`hardware/tests/test_cad_generation.py`)
1. **`test_parametric_bin_generation()`**:
   - Executes `generate_deep_bins.py` with test dimensions (2x2, 12U).
   - Asserts generated STL file size > 50KB and mesh bounding box equals $(84\text{mm} \times 84\text{mm} \times 84\text{mm} \pm 0.5\text{mm})$.

---

## 5. Documentation Updates
- `[MODIFY]` [`Parts-Database/README.md`](../../README.md): Document new hardware carrier specs and print recommendations (PETG / PLA).
- `[MODIFY]` [`Parts-Database/docs/plans/AGENTS.md`](AGENTS.md): Register Plan H01.

---

## 6. Verification Plan

### Automated Tests:
```bash
./run_tests.sh
```

### Manual Verification:
1. Run `python3 hardware/cad/generate_deep_bins.py --preview`.
2. Inspect exported STL in slicer (PrusaSlicer / Bambu Studio / Cura) to verify base Gridfinity mesh fit and wall thicknesses.

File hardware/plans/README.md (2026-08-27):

# Plan pipeline

The project may execute multiple defined plans concurrently while retaining a
prioritized queue for work that has not started:

`Idea → Queued plan → In-work execution → Archive`

## 1. Idea

Record new work in `../IDEAS.md`. Keep each idea under three sentences. Ideas
may be clarified or combined in the inbox, but implementation does not begin
until one idea is promoted into a numbered plan.

## 2. Plan

Create a Markdown file in `Queued/` using the next unused number and a short
kebab-case name, such as `Queued/009-design-carrier-removal-feature.md`. Copy
`_templates/plan.md`, replace every placeholder, and develop the idea into a
bounded implementation plan with requirements, non-goals, ordered steps, test
prints, validation, and rollback/reuse notes.

Plan numbers are permanent and never reused. `README.md` and `_templates/` do
not count as plans. Queued plans may be developed in advance, but they authorize
no implementation work and must use `Status: Queued`.

## Prioritization

[`PRIORITIES.md`](PRIORITIES.md) is the authoritative execution order for queued
plans and the only location where priority ranks are stored. Permanent plan
numbers describe creation history and do not determine priority. Do not add
priority fields to individual plan files. The priority table must list every
queued plan exactly once in a contiguous sequence beginning at 1.

Prioritize known safety/containment failures first, followed by dependency
blocking, rework avoidance, information gain, user value, and finally readiness
and print cost. Reassess and commit the priority table whenever physical
feedback reveals a failure, dependencies change, or project goals change.
Record the reason in that single file; never renumber existing plan files merely
to reorder execution.

## 3. Execution

Move a selected plan from `Queued/` directly into `Plans/` and set its status to
`Executing` before changing implementation files. Remove it from the priority
table and renumber the remaining queued ranks in `PRIORITIES.md` in the same
transition.

Multiple numbered plans may be in work directly inside `Plans/`. Concurrency is
appropriate when work is independent or when one plan is waiting for a print,
measurement, material, or other external result. For example, Plan 009 glass-
capture concepts and Plan 003 divider concepts may progress while Plan 001 waits
for carrier prints.

Concurrency does not waive dependencies. Each plan must state which steps may
proceed provisionally and which steps are gated by another plan's verified
result. Do not freeze dependent dimensions, release geometry, or claim physical
validation before the prerequisite evidence exists.

Keep concurrent work traceable:

- Update each plan's status and checklist independently.
- Use plan-numbered, focused Git commits; avoid combining unrelated plan changes
  in one commit.
- Record shared-interface decisions in every affected plan and update queue
  priorities if the dependency graph changes.
- A plan waiting on a physical result remains `Executing — waiting on ...`; it
  does not prevent eligible work in another active plan.

Use Git to preserve continuity:

1. Commit the accepted plan before implementation with a message beginning
   `plan-NNN:`.
2. Make focused implementation checkpoints that reference the same plan
   number.
3. Do not rewrite or delete tested revisions; record replacements explicitly.
4. Before archiving, require a clean validation result or clearly document
   every remaining limitation.

## 4. Archive

When every acceptance criterion is satisfied:

1. Set the plan status to `Complete` and add its completion date and final
   commit references.
2. Complete the required documentation reconciliation checklist in `AGENTS.md`,
   including the top-level project README and all applicable release records.
3. Move it into `Completed/`, prefixing the original filename with the ISO
   completion date: `YYYY-MM-DD-NNN-name.md`.
4. Create a detailed walkthrough beside it named
   `YYYY-MM-DD-NNN-name-walkthrough.md`, using the walkthrough template.
5. Commit the move and walkthrough with a message beginning `plan-NNN:`.
6. After that archive commit, continue other in-work plans and activate further
   eligible queued work only when the dependency and workload rules above permit.

Archived plans and walkthroughs are immutable historical records. Corrections
must be appended and committed, not silently rewritten.

Run `python3 Plans/check_pipeline.py` from the repository root before committing
a plan transition. It verifies active and queued filenames, unique plan numbers,
the single-source priority table, contiguous queued ranks, and completed
plan/walkthrough pairs.

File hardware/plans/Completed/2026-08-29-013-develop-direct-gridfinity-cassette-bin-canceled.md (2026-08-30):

# Plan 013 — Develop direct 1x2 7U Gridfinity cassette bin (CANCELED)

- Status: CANCELED
- Depends on: Baseline glass slide capture, hinge, and closure latch mechanics
- Created: 2026-08-29
- Started: 2026-08-29
- Completed: 2026-08-29 (Discontinued per user directive)
- Git start: `7e03e71`
- Git completion: `4dc3d9d`

## Outcome

Develop a standalone $1 \times 2$ Gridfinity-compatible cassette bin (7U height) that sits directly on standard Gridfinity baseplates and accepts standard Gridfinity bins stacked directly on top of its lid, while retaining the replaceable glass microscope slide window, positive slide capture, and internal dividers.

## Cancellation Rationale

During design iterations of both the embedded hinge mechanism and the subsequent horizontal sliding lid variant with stacking lip, the geometric complexity of integrating direct bin-on-bin stacking interfaces around a removable cassette lid proved excessive and problematic compared to the proven, physically verified **Cassette + Carrier Tray System Architecture** (Plans 001, 002, 003, 010, 011).

Per user directive on 2026-08-29 ("Cancel this experiment. We're not making progress."), this experiment was discontinued. The project maintains focus on the verified cassette family, removable dividers, dovetail pull tabs, 14U carrier trays, and fastener label generation.

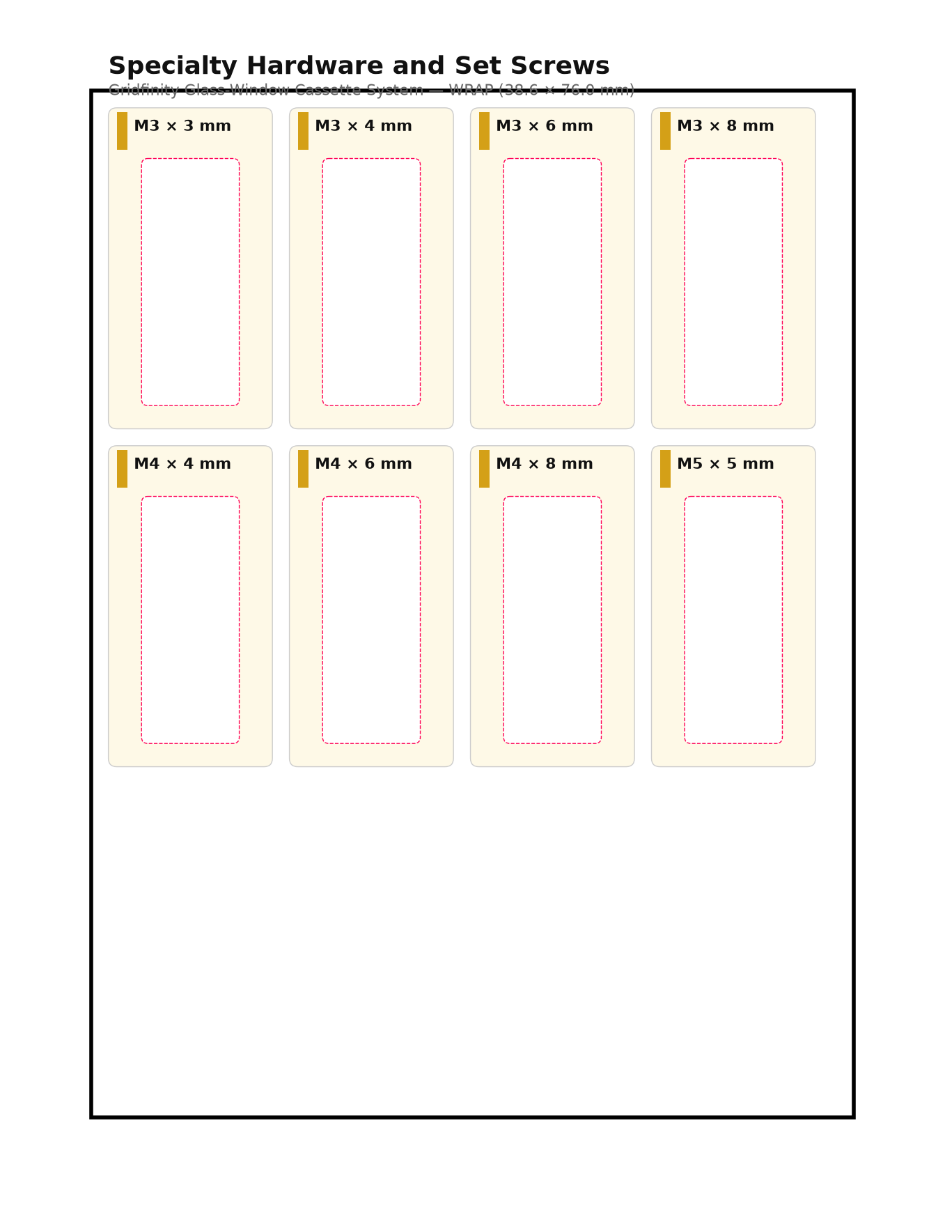
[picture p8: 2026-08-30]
hardware/labels/build/specialty_hardware_and_set_screws_preview_wrap.png

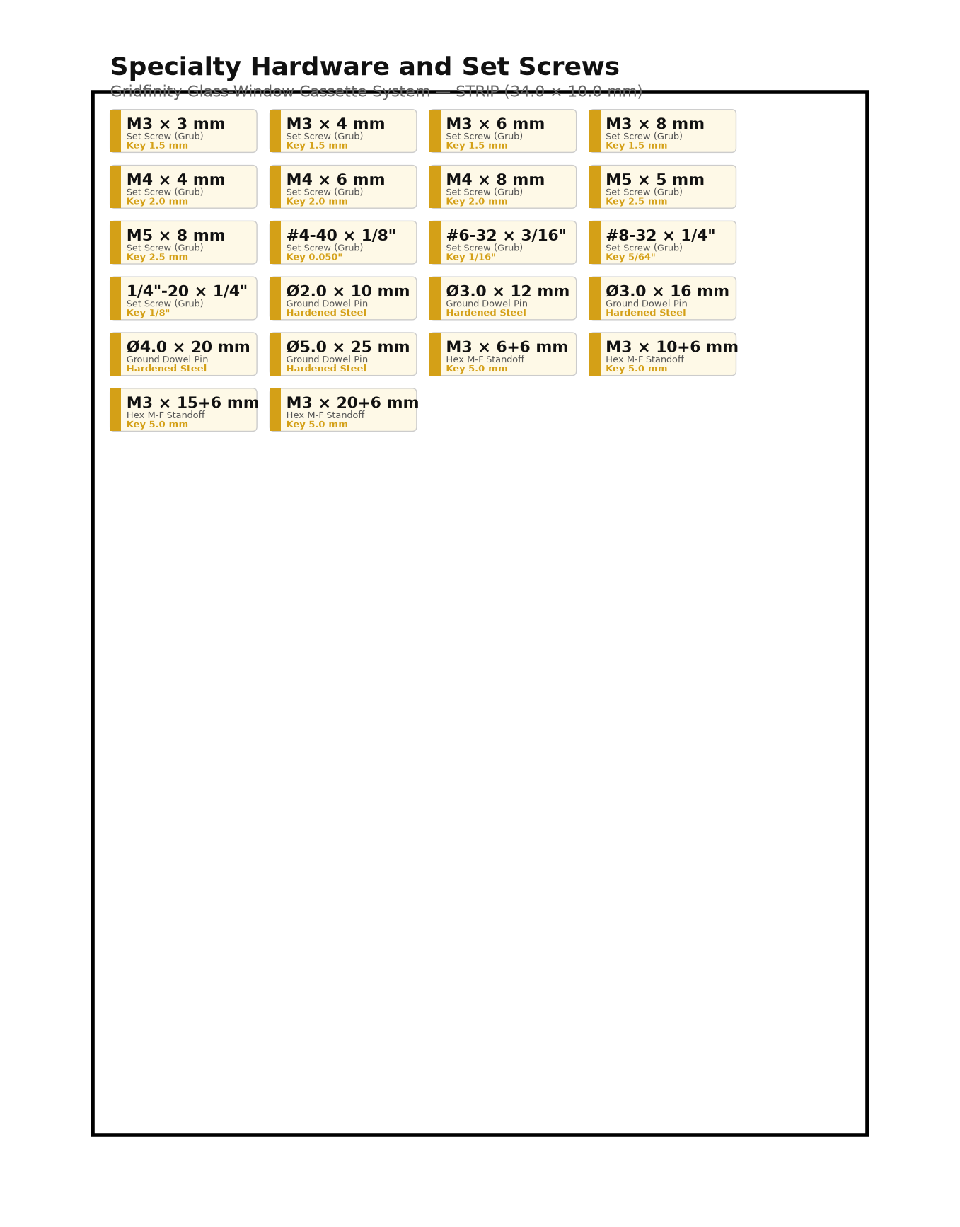
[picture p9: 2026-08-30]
hardware/labels/build/specialty_hardware_and_set_screws_preview_strip.png

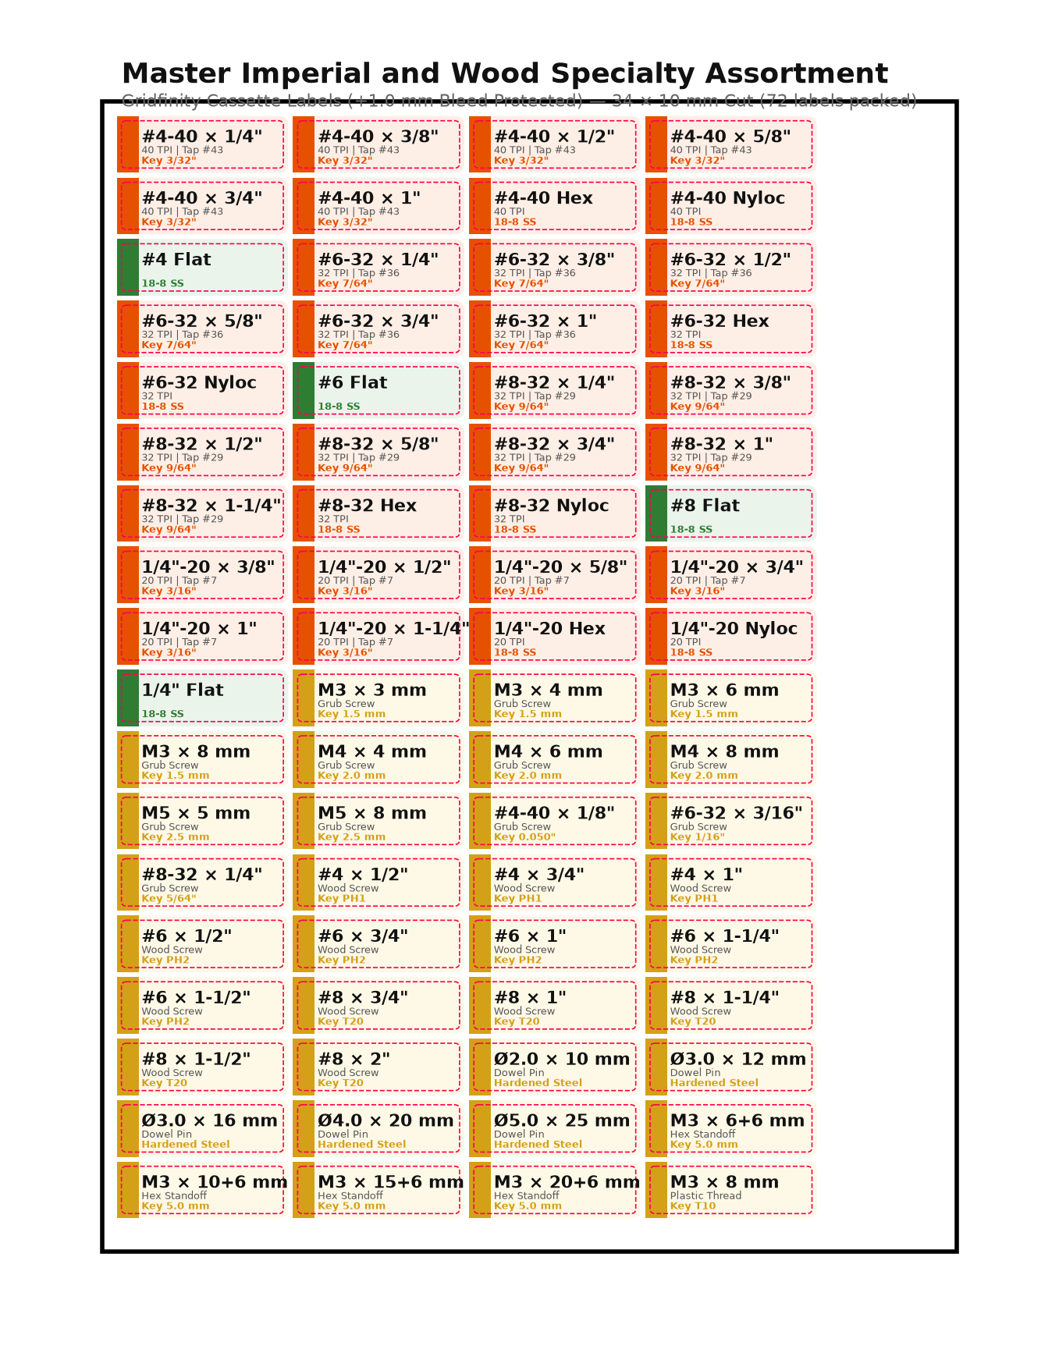
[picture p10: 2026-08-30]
hardware/labels/build/master_imperial_and_wood_specialty_assortment_preview.png

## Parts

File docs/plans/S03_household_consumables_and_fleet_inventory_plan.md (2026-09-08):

# Plan S03: Household Consumables & Fleet Maintenance Inventory Expansion

## 1. Goal Description
The `Parts-Database` schema is currently optimized for small fasteners in modular Gridfinity bins. To support whole-home and estate operations, the system needs to expand to track larger household maintenance consumables (HVAC air filters, water filters, LED light bulbs, lawnmower blades) and automotive fleet parts (motor oil, oil filters, spark plugs, fluids) stored across various locations (garage shelves, utility closets, basement racks).
This plan:
1. Expands `server/app/models.py` to support hierarchical storage locations (`Shelf`, `Cabinet`, `Bin`, `Rack`, `Slot`) and multi-pack item quantities.
2. Adds structured specification attributes (e.g. `16x25x1 MERV 11`, `5W-30 Full Synthetic`, `E26 2700K 60W`).
3. Introduces low-stock reorder thresholds and REST endpoints for external consumers (such as `Personal-Assistant`).

---

## 2. Architecture & Workflow Diagram

```mermaid
flowchart TD
    subgraph LocationHierarchy["Expanded Location Hierarchy"]
        Room["Location: Garage / Workshop / Utility Closet"]
        Unit["Storage Unit: Shelf B2 / Cabinet 01 / Wire Rack"]
        Bin["Container: Gridfinity Bin / Box / Bulk Shelf Spot"]
    end

    subgraph DataModel["SQLite Schema Expansion"]
        PartItem["Part / Consumable Record"]
        Specs["Item Specs JSON (MERV rating, Viscosity, Dimensions)"]
        Stock["Stock Ledger (Quantity, Minimum Threshold, Pack Size)"]
    end

    subgraph Clients["Consumers"]
        WebCatalog["Parts Catalog UI (:8090)"]
        PersonalAssistant["Personal-Assistant (:5000) REST Link"]
    end

    Room --> Unit --> Bin --> PartItem
    PartItem --> Specs
    PartItem --> Stock
    PartItem --> WebCatalog
    PartItem --> PersonalAssistant
```

---

## 3. Code Modifications

### Backend Server & Models
- `[MODIFY]` [`server/app/models.py`](../../server/app/models.py): Add `LocationHierarchy`, `ItemCategory` (Fastener, HVAC, Fleet, Plumbing, Electrical), `item_attributes` JSON field, and `reorder_threshold`.
- `[MODIFY]` [`server/app/database.py`](../../server/app/database.py): Add schema migration for new location and category columns.
- `[MODIFY]` [`server/app/main.py`](../../server/app/main.py): Add `/api/parts/search` and `/api/parts/{part_id}/decrement` endpoints.
- `[MODIFY]` [`server/templates/parts.html`](../../server/templates/parts.html): Add category filters (Hardware, HVAC, Fleet, Electrical) and location hierarchy breadcrumbs.

### Tests
- `[NEW]` `server/tests/test_consumables_inventory.py`: Automated tests verifying location hierarchy creation, attribute queries, reorder threshold alerts, and stock decrements.

---

## 4. Test Updates & Specifications

### Test Harness (`server/tests/test_consumables_inventory.py`)
1. **`test_create_consumable_with_hierarchy_location()`**:
   - Creates an HVAC filter record with location `"Utility Room > Shelf 2 > Rack A"`, specs `{"size": "16x25x1", "merv": 11}`, quantity 4, reorder threshold 2.
   - Asserts record persists and queries return correct hierarchy path.
2. **`test_stock_decrement_below_threshold_flags_reorder()`**:
   - Decrements stock from 2 to 1. Asserts `is_low_stock` boolean evaluates to True.

---

## 5. Documentation Updates
- `[MODIFY]` [`Parts-Database/README.md`](../../README.md): Document expanded taxonomy and API specifications.
- `[MODIFY]` [`Parts-Database/docs/plans/AGENTS.md`](AGENTS.md): Register Plan S03.

---

## 6. Verification Plan

### Automated Tests:
```bash
./run_tests.sh
```

### Manual Verification:
1. Open catalog web UI (`:8090/catalog`).
2. Add a new fleet oil filter item with location `Garage Shelf 1`.
3. Filter catalog by `Fleet` category and verify item appears with location breadcrumb.

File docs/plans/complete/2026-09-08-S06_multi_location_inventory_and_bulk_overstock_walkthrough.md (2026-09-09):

# Plan S06 Walkthrough: Multi-Location Inventory Allocation & Bulk Overstock Management

## 1. Executive Summary

- **Plan ID**: `Plan S06`
- **Subsystem**: `Parts-Database`
- **Status**: `COMPLETED & ARCHIVED`
- **Pass Rate**: 100% (29 of 29 hermetic tests passing)
- **Coverage**: 88% statement coverage ($\ge 85\%$ target) | 100% behavioral invariant coverage

Plan S06 introduces multi-location physical inventory allocation, bulk reserve storage tiers, replenishment alerts, and atomic stock transfer workflows in `Parts-Database`. Technicians can now keep compact working quantities at benchtop workstations while tracking high-volume bulk overstock in deep storage drawers.

---

## 2. Implemented Architecture & Data Flow

```mermaid
flowchart TD
    subgraph MultiLocationStorage["Workshop Tiered Storage Hierarchy"]
        direction TB
        subgraph PrimaryTier["Drawer 01: Benchtop Gridfinity (PRIMARY)"]
            PBIN["BIN-001-C1 (M3x12 Socket Head)<br/>Role: PRIMARY<br/>Qty: 25 / Reorder Threshold: 10"]
        end
        
        subgraph BulkTier["Drawer 06: Deep Storage (BULK_RESERVE)"]
            BBIN["BIN-081-C1 (M3x12 Socket Head)<br/>Role: BULK_RESERVE<br/>Qty: 480 pieces"]
        end
    end

    subgraph REST_API["FastAPI REST Endpoints & Ledger"]
        PART["PartRecord: M3-12mm-SHCS<br/>Total: 505x | Primary: 25x | Bulk: 480x"]
        XFER["POST /api/inventory/transfer<br/>(Atomic Decrement / Increment)"]
        ALERT["GET /api/inventory/replenish-alerts<br/>(Finds low primary bins with bulk stock)"]
        LOG["StockTransferLogRecord<br/>(Immutable audit log with UUID)"]

        PART --> PBIN
        PART --> BBIN
        BBIN -->|Atomic Stock Move| XFER --> PBIN
        XFER --> LOG
        PBIN -.->|Stock <= 10| ALERT
    end
```

---

## 3. Code Modifications & Key Files

| File | Status | Description |
| :--- | :--- | :--- |
| [`server/app/models.py`](../../server/app/models.py) | `[MODIFY]` | Added `storage_role` to `BinCompartmentRecord`, `tier` to `StorageLocationRecord`, and created `StockTransferLogRecord`. |
| [`server/app/routes/api.py`](../../server/app/routes/api.py) | `[MODIFY]` | Implemented `POST /api/inventory/transfer`, `GET /api/inventory/replenish-alerts`, `POST /api/compartments/{id}/role`, and enhanced part stock aggregations. |
| [`server/app/routes/views.py`](../../server/app/routes/views.py) | `[MODIFY]` | Updated `part_detail_view` and `dashboard_view` contexts with multi-location stock rollups and replenish alerts. |
| [`server/app/seed.py`](../../server/app/seed.py) | `[MODIFY]` | Added `DRAWER-06` (`BULK_OVERSTOCK`), `CARRIER-BULK-01`, and bulk bins `BIN-080` to `BIN-083`. |
| [`server/templates/part_detail.html`](../../server/templates/part_detail.html) | `[MODIFY]` | Partitioned Primary vs Bulk storage tiers and added interactive 1-click restock transfer modal. |
| [`server/templates/parts.html`](../../server/templates/parts.html) | `[MODIFY]` | Added color-coded multi-location badges in parts table. |
| [`server/templates/dashboard.html`](../../server/templates/dashboard.html) | `[MODIFY]` | Added real-time "Restock Required from Bulk Overstock" alert widget. |
| [`server/templates/bin_detail.html`](../../server/templates/bin_detail.html) | `[MODIFY]` | Added storage role dropdown selector and badge for compartments. |
| [`docs/MULTI_LOCATION_STORAGE.md`](../MULTI_LOCATION_STORAGE.md) | `[NEW]` | Published comprehensive multi-location organization and restock workflow guide. |
| [`server/tests/test_multi_location_inventory.py`](../../server/tests/test_multi_location_inventory.py) | `[NEW]` | Comprehensive test suite covering roles, aggregation, atomic transfers, insufficient balance validation, and alerts. |

---

## 4. Test Verification & Coverage Ratchet Scorecard

```
🧪 Running Parts-Database tests with: /Volumes/T9/Sync/Working/Server Rack/Parts-Database/server/.venv/bin/python
============================= test session starts ==============================
collected 29 items

server/tests/test_backup_pipeline.py ....                                [ 13%]
server/tests/test_batch_label_generator.py .........                     [ 44%]
server/tests/test_compartments_and_routes.py .....                       [ 62%]
server/tests/test_multi_location_inventory.py .......                    [ 86%]
server/tests/test_server_api.py ....                                     [100%]

============================= 29 passed in 2.13s ===============================
```

### Coverage Ratchet Metrics
| Metric | Pre-Plan Baseline | Post-Plan Value | Delta | Ratchet Status |
| :--- | :---: | :---: | :---: | :---: |
| **Hermetic Tests** | 22 tests | 29 tests | +7 tests | 🟢 Increased |
| **Statement Coverage** | 86% | 88% | +2% | 🟢 Increased |
| **Behavioral Invariants** | 4/4 (100%) | 4/4 (100%) | 0 | 🟢 Maintained |
| **Pass Rate** | 100% | 100% | 0 | 🟢 Maintained |

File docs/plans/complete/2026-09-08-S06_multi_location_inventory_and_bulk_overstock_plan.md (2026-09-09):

# Plan S06: Multi-Location Inventory Allocation, Bulk Overstock Storage & Transfer Management

## 1. Goal Description

### Context & Problem Statement
In workshop hardware and fastener management, parts are frequently purchased in bulk quantities (e.g. 100-pack or 500-pack boxes of M3x12 screws or heat-set inserts). Keeping full bulk containers in active benchtop Gridfinity trays wastes valuable primary drawer real estate and causes cassette crowding.

The standard organizational pattern is **tiered multi-location storage**:
1. **Primary Workstation Bins (`PRIMARY_PICK`)**: A usable working quantity (e.g. 20–50 pieces) resides in the most accessible, high-traffic modular Gridfinity carrier directly above or next to the workbench (e.g. Workbench Drawer 1).
2. **Bulk Overstock & Deep Storage (`BULK_RESERVE`)**: The bulk remainder (e.g. 450 pieces) is stored in a larger cassette, deep bin, or bulk hardware tub in a secondary, less accessible drawer, back cabinet, or overhead shelf (e.g. Deep Storage Drawer 6).

While `Parts-Database` supports linking a `part_id` to multiple `BinCompartmentRecord` rows, the system currently lacks:
- Explicit storage tier classification (`PRIMARY_PICK` vs `BULK_RESERVE` vs `OVERFLOW`).
- Combined multi-location stock rollups and tier breakdowns in the catalog views.
- Automatic replenishment alerts when primary benchtop stock drops below reorder thresholds while bulk overstock exists.
- An atomic, 1-click or scan-to-transfer inventory movement workflow (`POST /api/inventory/transfer`) with auditable transfer logging (`StockTransferLogRecord`).

### Objectives
1. **Model Storage Tiering & Compartment Roles**: Enhance [`server/app/models.py`](../../server/app/models.py) with storage roles (`PRIMARY`, `BULK_RESERVE`, `OVERFLOW`), location tiering, and an auditable `StockTransferLogRecord`.
2. **Atomic Inventory Transfer API**: Implement `POST /api/inventory/transfer` and `GET /api/inventory/replenish-alerts` in [`server/app/routes/api.py`](../../server/app/routes/api.py).
3. **Multi-Location Catalog & Part Detail Views**: Update [`server/app/routes/views.py`](../../server/app/routes/views.py) and templates ([`part_detail.html`](../../server/templates/part_detail.html), [`parts.html`](../../server/templates/parts.html), [`dashboard.html`](../../server/templates/dashboard.html)) to display multi-tier location breakdowns (e.g. `25x Primary [BIN-001-C1] + 500x Bulk [BIN-080-C1] = 525x Total`) with interactive "Transfer from Bulk to Primary" restock modals.
4. **Hermetic Test Suite**: Add comprehensive unit tests in `server/tests/test_multi_location_inventory.py` verifying multi-location aggregation, transfer atomicity, insufficient stock validation, and replenishment alerts.
5. **Documentation**: Create `server/docs/MULTI_LOCATION_STORAGE.md` covering multi-tier organization, bin replenishment, and transfer mechanics.

---

## 2. Architecture & Workflow Diagram

```mermaid
flowchart TD
    subgraph MultiLocationStorage["Multi-Location Workshop Storage Architecture"]
        direction TB
        subgraph PrimaryTier["Primary Workstation Tier (Drawer 1 / Bench Carrier)"]
            PBIN["BIN-001-C1 (M3x12 Socket Head)<br/>Role: PRIMARY_PICK<br/>Qty: 15 / Threshold: 20"]
        end
        
        subgraph BulkTier["Bulk Overstock Tier (Drawer 6 / Deep Storage)"]
            BBIN["BIN-080-C1 (M3x12 Socket Head)<br/>Role: BULK_RESERVE<br/>Qty: 480 pieces"]
        end
    end

    subgraph DataModel["SQLite Relational Schema (SQLAlchemy Async)"]
        PART["PartRecord: part_id='m3_12_shcs'<br/>Total Aggregated Stock: 495 pcs"]
        COMP1["BinCompartmentRecord #1<br/>bin_id='BIN-001', role='PRIMARY', qty=15"]
        COMP2["BinCompartmentRecord #2<br/>bin_id='BIN-080', role='BULK_RESERVE', qty=480"]
        LOG["StockTransferLogRecord<br/>from='BIN-080-C1', to='BIN-001-C1', qty=50"]

        PART --> COMP1
        PART --> COMP2
        COMP2 -.->|Transfer 50 pcs| COMP1
        COMP2 -.->|Records Audit| LOG
    end

    subgraph Workflow["Replenishment & Transfer Workflow"]
        CHECK{"Primary Stock <= Threshold?"}
        ALERT["Trigger Replenish Alert<br/>'Restock BIN-001 from Bulk BIN-080'"]
        MODAL["Open Transfer Dialog<br/>Transfer Qty: 50 pcs"]
        API["POST /api/inventory/transfer"]
        ATOMIC["Atomic DB Transaction:<br/>1. BIN-080: 480 -> 430<br/>2. BIN-001: 15 -> 65<br/>3. Log Audit Entry"]

        PBIN --> CHECK
        CHECK -- Yes (15 <= 20) --> ALERT
        ALERT --> MODAL
        MODAL --> API --> ATOMIC
    end
```

---

## 3. Code Modifications

### 1. Database Schema & Data Models
- `[MODIFY]` [`server/app/models.py`](../../server/app/models.py):
  - Add `storage_role: Mapped[str] = mapped_column(String(32), nullable=False, default="PRIMARY")` (`PRIMARY`, `BULK_RESERVE`, `OVERFLOW`, `SECONDARY`) to `BinCompartmentRecord`.
  - Add `tier: Mapped[str] = mapped_column(String(32), nullable=False, default="PRIMARY_BENCH")` (`PRIMARY_BENCH`, `SECONDARY_DRAWER`, `BULK_OVERSTOCK`, `DEEP_STORAGE`) to `StorageLocationRecord`.
  - Add `StockTransferLogRecord(Base)`:
    - `id`: `String(64)` primary key (UUID / timestamped ID).
    - `part_id`: `String(64)` foreign key to `parts.id`.
    - `from_compartment_id`: `String(64)` foreign key to `bin_compartments.id`.
    - `to_compartment_id`: `String(64)` foreign key to `bin_compartments.id`.
    - `quantity`: `Integer` (positive integer moved).
    - `reason`: `Optional[str]` (e.g. "Restock primary bin", "Manual adjustment").
    - `created_at`: `DateTime` timestamp.

### 2. REST API Endpoints
- `[MODIFY]` [`server/app/routes/api.py`](../../server/app/routes/api.py):
  - `POST /api/inventory/transfer`:
    - Payload: `{"from_compartment_id": str, "to_compartment_id": str, "quantity": int, "reason": Optional[str]}`.
    - Validates both compartments hold the same `part_id`.
    - Validates source compartment has `quantity_on_hand >= quantity`.
    - Executes atomic decrement of source, increment of destination, and inserts `StockTransferLogRecord`.
  - `GET /api/inventory/replenish-alerts`:
    - Queries all `PRIMARY` compartments where `quantity_on_hand <= reorder_threshold` and at least one corresponding `BULK_RESERVE` compartment exists with `quantity_on_hand > 0`.
    - Returns actionable list of restock opportunities with source/dest bin IDs and recommended transfer amounts.
  - `POST /api/compartments/{compartment_id}/role`:
    - Updates storage role (`PRIMARY` vs `BULK_RESERVE`).

### 3. Web Catalog Views & UI Templates
- `[MODIFY]` [`server/app/routes/views.py`](../../server/app/routes/views.py):
  - Update `part_detail_view` (`/p/{part_id}`) to compute:
    - `primary_stock`: sum of `PRIMARY` compartments.
    - `bulk_stock`: sum of `BULK_RESERVE` and `OVERFLOW` compartments.
    - `total_stock`: sum of all compartments.
    - `replenish_sources`: list of bulk compartments available for quick restock.
  - Update `parts_catalog_view` (`/parts`) to aggregate total stock across all locations and render multi-location badges.
  - Update `dashboard_view` (`/`) to include a "Restock Needed from Bulk" alert card.
- `[MODIFY]` [`server/templates/part_detail.html`](../../server/templates/part_detail.html):
  - Group storage locations by tier: **Primary Workstation Bins** vs **Bulk Overstock & Deep Storage**.
  - Add interactive "Transfer from Bulk to Primary" 1-click modal / button.
  - Add visual status pill: `🟢 Stocked (Primary: 45x | Bulk: 500x)` or `🟡 Primary Low (Restock Available from Drawer 6)`.
- `[MODIFY]` [`server/templates/parts.html`](../../server/templates/parts.html):
  - Display multi-location breakdown in the parts table (`45x Primary / 500x Bulk`).
- `[MODIFY]` [`server/templates/dashboard.html`](../../server/templates/dashboard.html):
  - Add "Replenish from Bulk Overstock" quick-action widget.
- `[MODIFY]` [`server/templates/bin_detail.html`](../../server/templates/bin_detail.html):
  - Allow toggling compartment role (`Primary Pick` vs `Bulk Overstock`).

### 4. Database Seed Data
- `[MODIFY]` [`server/app/seed.py`](../../server/app/seed.py):
  - Add deep storage location (`LOC-DRAWER-06`, "Deep Storage Drawer 6", type `BULK_OVERSTOCK`).
  - Add bulk carrier and bulk bin (`BIN-080`, 1-compartment, `BULK_RESERVE`) storing overstock for common fasteners (`M3x8mm`, `M3x12mm`, `M4x16mm`).

---

## 4. Test Updates & Specifications

### 1. `server/tests/test_multi_location_inventory.py` `[NEW]`
- `test_part_multi_location_aggregation()`: Verifies that a part with stock in both a primary bench bin and bulk storage bin correctly reports isolated primary, bulk, and combined total quantities.
- `test_compartment_storage_roles()`: Verifies setting and updating storage roles (`PRIMARY` vs `BULK_RESERVE`) on compartments.
- `test_atomic_inventory_transfer_success()`: Verifies transferring stock from bulk compartment to primary compartment decrements source, increments target, and logs audit record.
- `test_atomic_inventory_transfer_insufficient_stock()`: Verifies transfer is rejected with HTTP 400 when requested quantity exceeds source stock.
- `test_atomic_inventory_transfer_part_mismatch()`: Verifies transfer is rejected when source and target compartments contain different part IDs.
- `test_replenishment_alert_trigger()`: Verifies `GET /api/inventory/replenish-alerts` detects low primary bins with available bulk overstock.
- `test_part_detail_multi_location_context()`: Verifies `/p/{part_id}` view context includes primary/bulk stock breakdowns and replenishment sources.

---

## 5. Documentation Updates

### 1. `server/docs/MULTI_LOCATION_STORAGE.md` `[NEW]`
- Document multi-tier storage philosophy (benchtop Gridfinity pick bins vs deep storage bulk tubs).
- Detail the bin-to-bin restock transfer workflow, role configuration, and low-stock replenishment alerts.

---

## 6. Verification Plan

### Automated Tests
```bash
./run_tests.sh
```
All test suites across `Parts-Database` must pass 100%.

### Manual Verification
1. Launch Parts-Database web server:
   ```bash
   .venv/bin/python -m uvicorn server.app.main:app --port 8090 --reload
   ```
2. Open `http://localhost:8090/parts` in browser:
   - Confirm parts stored in multiple locations show multi-tier badges (e.g. `25x Primary | 500x Bulk`).
3. Click on a multi-location part (e.g. `/p/m3_12_shcs`):
   - Confirm both Primary Bench Bin (`BIN-001-C1`) and Bulk Reserve Bin (`BIN-080-C1`) appear in separate tier sections.
   - Click "Restock Primary (Transfer from Bulk)", specify 25 pieces, and submit.
   - Confirm live update: Primary stock increases by 25, Bulk stock decreases by 25, Total remains constant.
4. Verify `/` Dashboard displays the "Restock Needed from Bulk" alert card when primary stock is low.

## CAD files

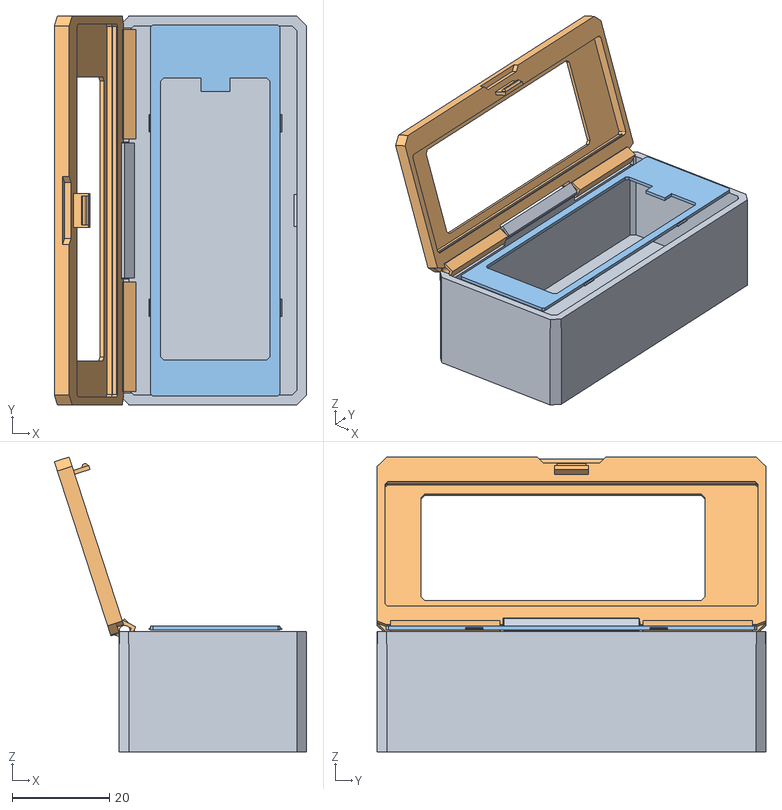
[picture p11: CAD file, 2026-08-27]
Cassettes/glass_slide_cassette_40x80/build/cassette_assembly_reference_v0_6.obj
51.9 x 80.0 x 60.7
lid_open_108deg
retainer_installed

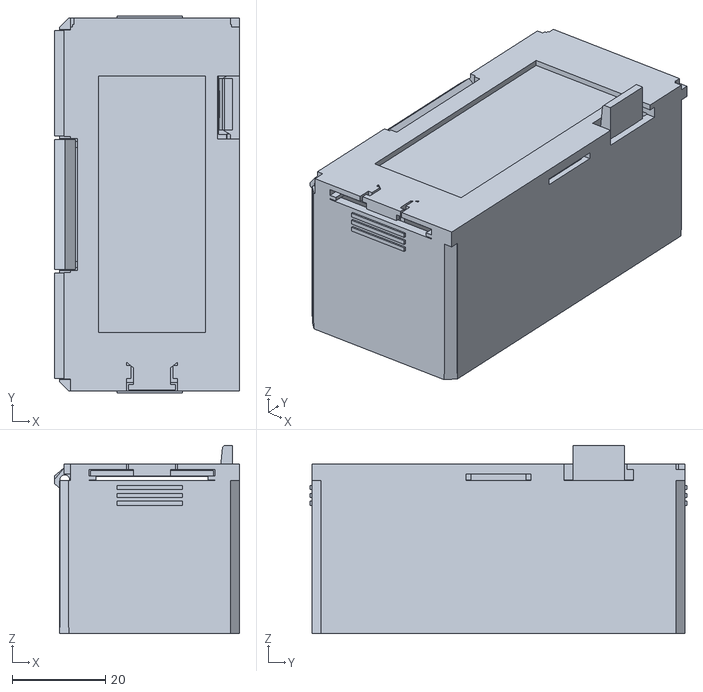
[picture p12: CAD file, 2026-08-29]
hardware/cassettes/glass_slide_cassette_40x80/build/REFERENCE_closed_assembly_DO_NOT_PRINT.stl
39.8 x 80.8 x 40.4

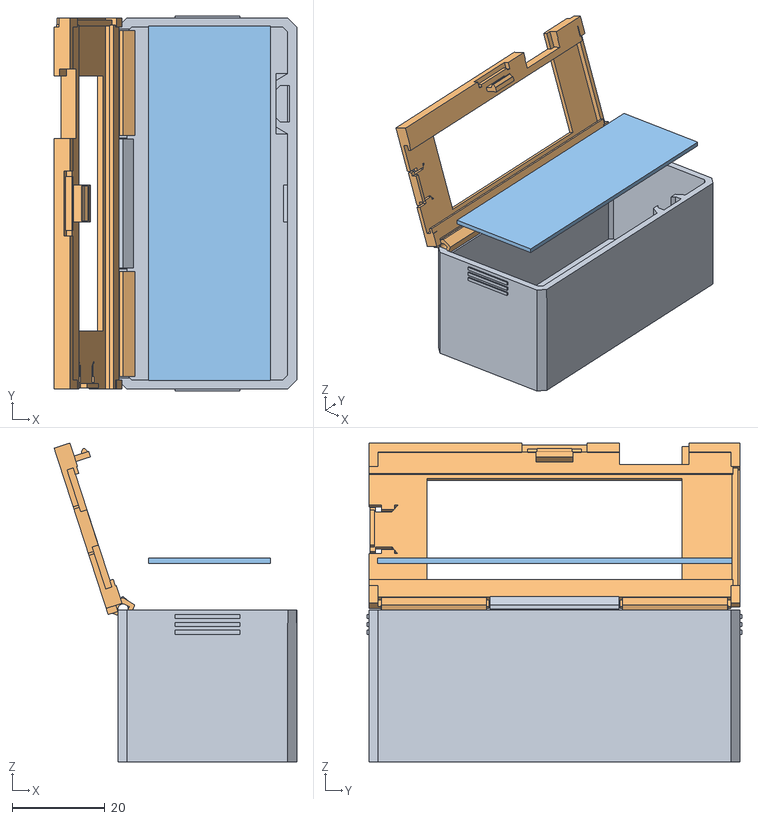
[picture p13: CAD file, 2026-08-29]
hardware/cassettes/glass_slide_cassette_40x80/build/cassette_assembly_reference_v0_8.obj
52.3 x 80.8 x 68.7
lid_open_108deg
glass_reference_separated

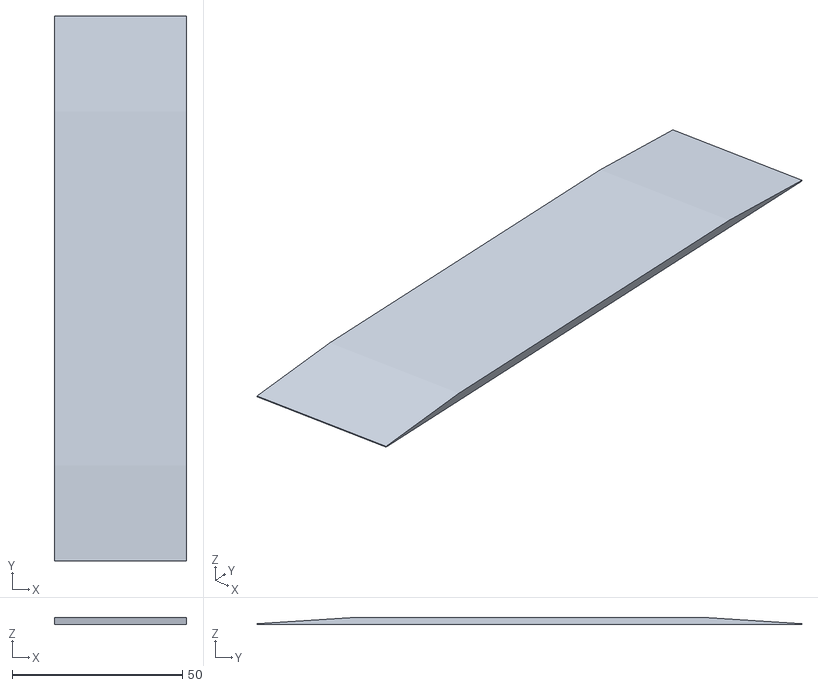
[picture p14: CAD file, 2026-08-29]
hardware/carriers/carrier_3x4_14u_test/build/rocker_insert_dual_slot_reversed.stl
38.8 x 160.0 x 2.00

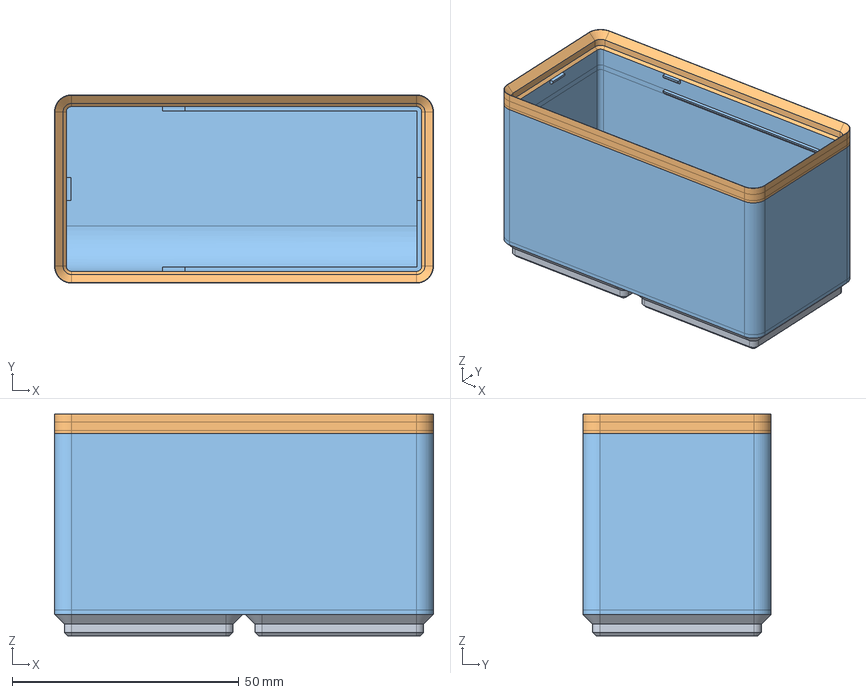
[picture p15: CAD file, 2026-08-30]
hardware/cassettes/glass_slide_gridfinity/glass_slide_gridfinity_box.step
83.5 x 41.5 x 48.9 mm
1U Baseplate
1U Baseplate001

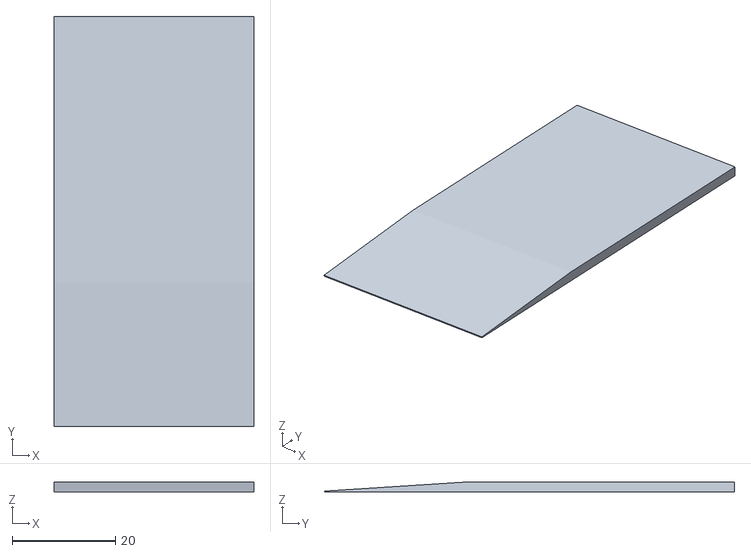
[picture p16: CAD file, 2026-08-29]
hardware/carriers/carrier_3x4_14u_test/build/rocker_insert_single_slot_reversed.stl
38.8 x 79.6 x 2.00

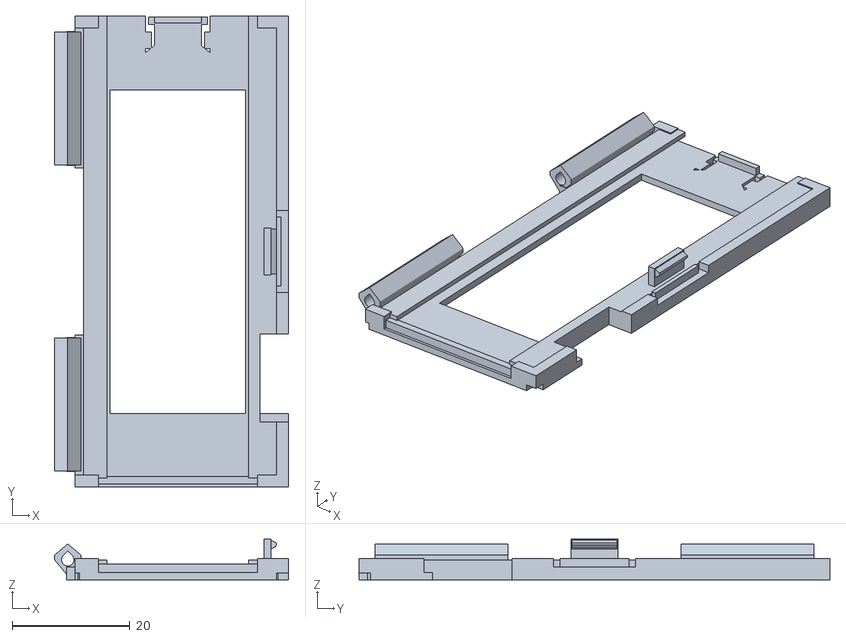
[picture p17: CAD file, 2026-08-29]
hardware/cassettes/glass_slide_cassette_40x80/build/cassette_lid_v0_8_print.stl
39.8 x 80.0 x 6.90

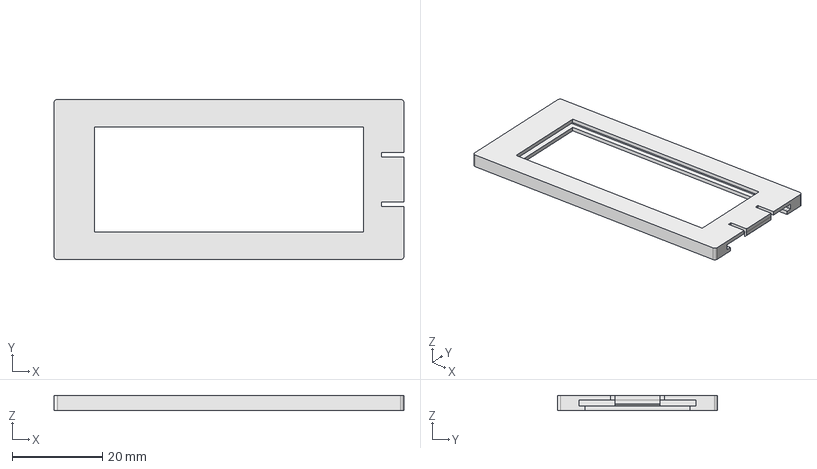
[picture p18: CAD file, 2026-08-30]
hardware/cassettes/glass_slide_gridfinity/glass_slide_gridfinity_lid.step
77.5 x 35.5 x 3.40 mm

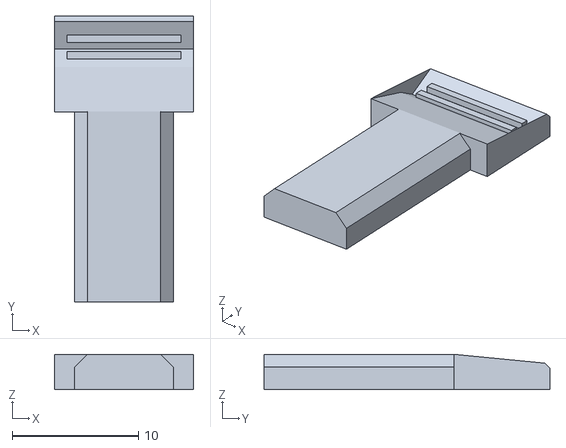
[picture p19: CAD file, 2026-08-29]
hardware/cassettes/glass_slide_cassette_40x80/build/pull_tab_v0_8.stl
11.0 x 22.6 x 2.80

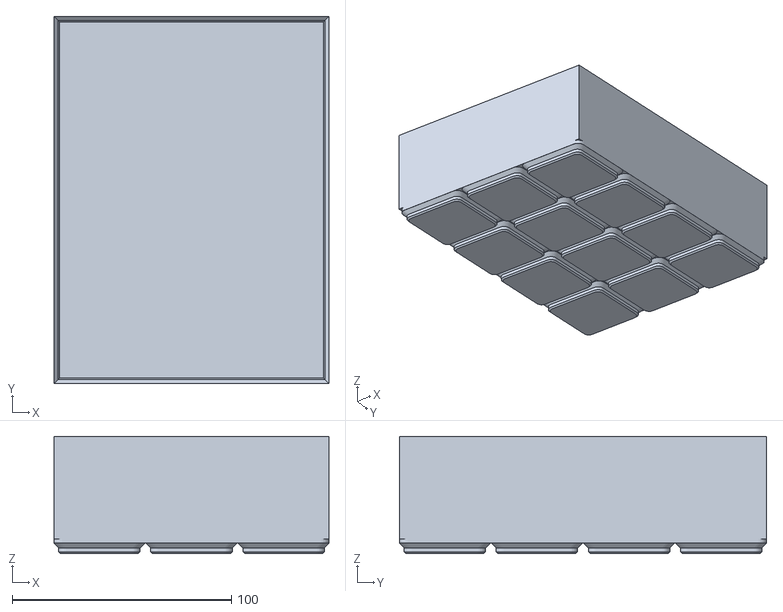
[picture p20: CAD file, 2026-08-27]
hardware/carriers/carrier_3x4_14u_test/build/carrier_3x4_7u_v0_1.stl
125.5 x 167.5 x 53.4

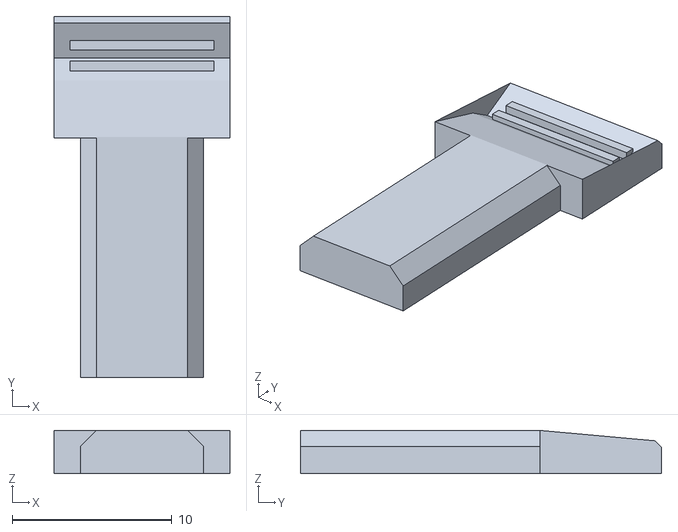
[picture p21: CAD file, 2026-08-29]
hardware/cassettes/glass_slide_cassette_40x80/build/pull_tab_v0_8_fit_0_15.stl
11.0 x 22.6 x 2.70

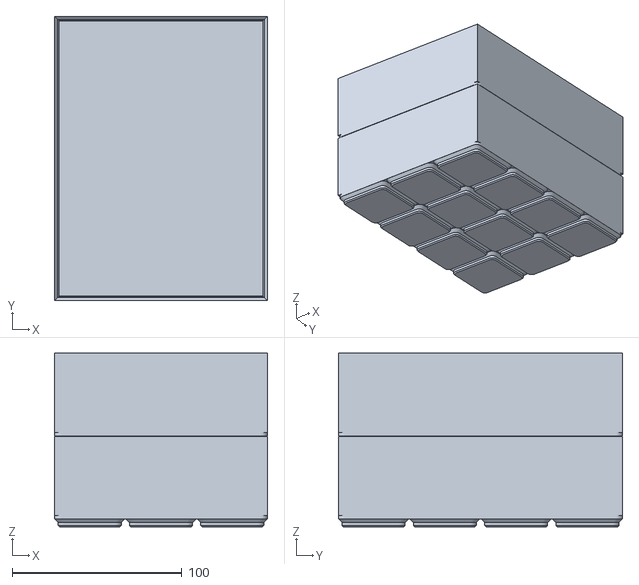
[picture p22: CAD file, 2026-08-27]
hardware/carriers/carrier_3x4_14u_test/build/REFERENCE_two_carrier_14u_stack_DO_NOT_PRINT.stl
125.5 x 167.5 x 102.4

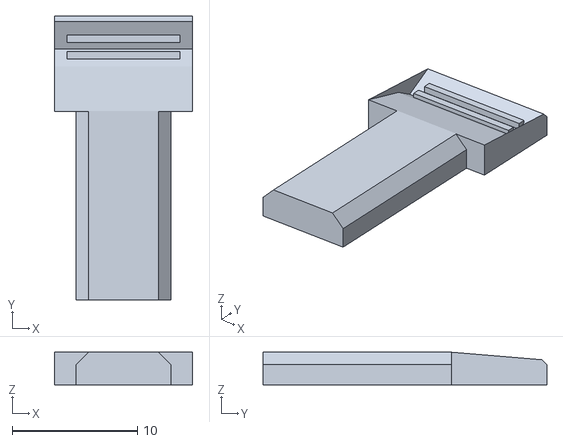
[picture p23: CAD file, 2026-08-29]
hardware/cassettes/glass_slide_cassette_40x80/build/pull_tab_v0_8_fit_0_20.stl
11.0 x 22.6 x 2.60

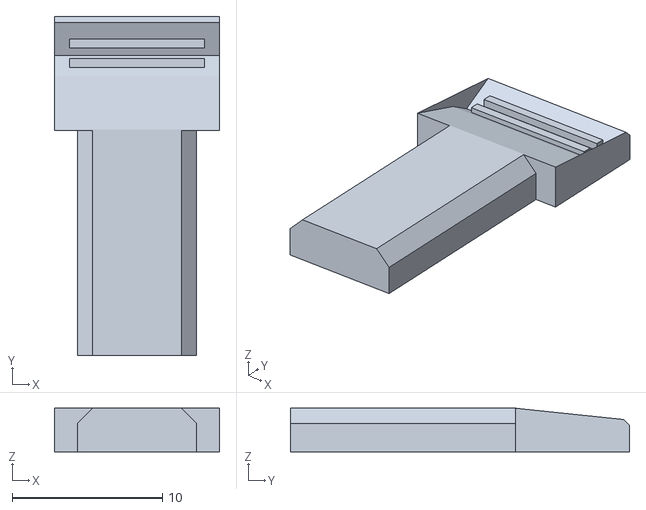
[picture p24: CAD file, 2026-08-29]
hardware/cassettes/glass_slide_cassette_40x80/build/pull_tab_v0_8_fit_0_05.stl
11.0 x 22.6 x 2.90

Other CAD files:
hardware/carriers/carrier_3x4_14u_test/build/rocker_insert_dual_slot.stl
hardware/cassettes/glass_slide_gridfinity/glass_slide_gridfinity.FCStd
hardware/carriers/carrier_3x4_14u_test/build/rocker_insert_single_slot.stl
hardware/cassettes/glass_slide_cassette_40x80/build/pull_tab_v0_8_fit_0_10.stl
hardware/cassettes/glass_slide_cassette_40x80/build/cassette_body_v0_8.stl
hardware/cassettes/glass_slide_cassette_40x80/build/cassette_body_v0_8_divided.stl
hardware/cassettes/glass_slide_cassette_40x80/build/divider_card_1_0mm.stl
hardware/cassettes/glass_slide_cassette_40x80/build/divider_card_1_2mm.stl
hardware/cassettes/glass_slide_cassette_40x80/build/divider_card_1_4mm.stl

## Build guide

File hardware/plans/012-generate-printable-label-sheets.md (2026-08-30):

# Plan 012 — Generate printable label sheets

- Status: In Work
- Depends on: Baseline cassette lid geometry ($34 \times 10\text{ mm}$ label zone)
- Created: 2026-08-29
- Started: 2026-08-29
- Completed: Not completed
- Git start: `3e2091f`
- Git completion: Not completed

## Outcome

Develop an automated Python generator that outputs high-density, printable, Cricut-ready
label sheets (PDF / SVG / PNG) for standard US (Imperial / SAE) and Metric fasteners
(nuts, bolts, machine screws, wood screws, flat/lock washers, and inserts). Labels
will display standardized technical specifications (size, pitch, length, head type,
drive type, material/grade, and silhouette iconography), tailored for the $34 \times 10\text{ mm}$
solid lid zone with optional full-lid wrap overlays, integrating seamlessly with bin body
color-coding for rapid visual retrieval in shop drawers.

## Requirements

### 1. Fastener Taxonomy and Data Architecture
- Build a structured JSON / YAML / Python hardware catalog covering standard shop fasteners:
  - **Metric Threads:** M1.6, M2, M2.5, M3, M4, M5, M6, M8, M10, M12 (standard coarse and common fine pitches).
  - **Imperial / SAE Threads:** #0-80, #2-56, #4-40, #6-32, #8-32, #10-24, #10-32, 1/4"-20, 1/4"-28, 5/16"-18, 3/8"-16, 1/2"-13.
  - **Fastener Classes:**
    - **Bolts & Machine Screws:** Standard lengths (e.g. 4 mm to 60 mm; 3/16" to 3").
    - **Nuts:** Hex, nylon-insert lock (Nyloc), flanged, wing, cap/acorn, square, coupling, and brass heat-set threaded inserts (M2–M8).
    - **Washers:** Flat (standard, fender, small OD), split lock, external/internal tooth star, countersunk finishing, and Belleville.
  - **Head Profiles (with vector silhouettes):**
    - Socket Head Cap (SHCS), Button Head (BHCS), Flat/Countersunk (FHCS), Pan Head, Truss Head, Round Head, Hex Head, Oval/Raised Countersunk, Flanged Hex.
  - **Drive Types (with vector icons):**
    - Hex (Allen), Torx (6-lobe star), Security Torx (tamper-resistant pin), Phillips, Slotted, Pozidriv, Robertson (Square).
  - **Material & Finish Badges:**
    - 304/316 Stainless Steel (18-8 / A2 / A4), Class 10.9 / 12.9 Alloy Steel (Black Oxide), Grade 5 / Grade 8 Zinc-Plated, Brass, Nylon.

### 2. Physical Layout & Dimensional Standards
- **Standard 9 mm Strip ($34.0 \times 9.0\text{--}10.0\text{ mm}$):**
  - Primary format fitted to the solid lid label band.
  - Optimized for 9 mm Brother TZe tape and kiss-cut vinyl/polyester sheets.
  - Layout: Bold size/length header on left, technical pitch/material subtext, vector drive/head silhouettes on right.
- **Extended / Full-Lid Wrap Overlay ($38.6 \times 76.0\text{ mm}$ with $23.0 \times 58.5\text{ mm}$ glass cutout):**
  - Optional full-top vinyl skin that covers the lid perimeter while leaving the microscope-slide glass window 100% unobstructed.
  - Provides expanded surface area for fastener diagrams, thread pitch gauges, drill bit tap recommendations (e.g. "Tap: 2.5 mm / Drill: #43"), and color-coded borders.
- **Color-Coding Hierarchy:**
  - Bin body color (PETG/ASA filament) serves as the macro-level visual category (e.g. Blue = Metric Coarse, Red = Imperial UNC, Yellow = Brass Inserts, Green = Washers).
  - Label color accents (color laser printing) reinforce categorization without obscuring high-contrast black technical text.

### 3. Print-and-Cut Fabrication Integration (Color Laser + Cricut)
- Output print sheets in standard **Letter (8.5 × 11 in)** and **A4** formats at 300 / 600 DPI.
- Multi-layer vector generation:
  - **Print Layer (PDF / PNG):** High-resolution color artwork with bleed margins.
  - **Cut Layer (SVG):** Precision vector cut paths (kiss-cut perimeters) and optional weeding borders.
  - **Registration Marks:** Cricut Print-Then-Cut fiducial registration corner frames and calibration marks.
- Support batch generation (e.g. full sheet of M3 assortment, complete SAE washer kit, or customized mixed assortments).

## Non-goals

- Do not modify the underlying cassette 3D CAD models or reduce the visible glass aperture.
- Do not require proprietary label-making cloud software; keep all rendering in local, open-source Python scripts (e.g. `reportlab`, `matplotlib`, `cairosvg`, or pure SVG).
- Do not generate single-use raster images that degrade when scaled.

## Reusable parts and compatibility

- 100% compatible with all v0.6, v0.7, and v0.8 cassette lids (`cassette_lid_v0_8_print.stl`) and larger cassette family lids.
- Usable on standard polyester/vinyl sticker sheets (matte, gloss, waterproof laser label paper).

## Implementation steps

1. [x] **Hardware Taxonomy & Schema:** Define `Labels/data/fasteners.json` (or YAML) with comprehensive US and Metric fastener parameters, pitches, tap drills, and categories.
2. [x] **Vector Iconography Library:** Create clean, scalable SVG vector silhouettes for head types (socket, button, flat, pan, hex, oval) and drive types (hex, torx, phillips, slotted, square).
3. [x] **Parametric Label Renderer:** Write `Labels/generate_labels.py` to render individual labels (both $34 \times 10\text{ mm}$ strips and full-lid window wraps) with crisp typography, color badges, and icons.
4. [x] **Cricut Sheet Composer:** Implement automated sheet tiling (Letter / A4) with Cricut Print-Then-Cut fiducial marks, bleed margins, and SVG cut path export.
5. [x] **Assortment Presets:** Create turnkey assortment templates:
   - Metric Socket Assortment (M2, M2.5, M3, M4, M5, M6).
   - SAE Socket & Hex Assortment (#4-40 through 3/8"-16).
   - Metric & SAE Nut / Washer Assortment.
   - Brass Heat-Set Insert Assortment.
6. [ ] **Physical Print & Cut Validation:** Print test sheets on color laser printer with sticker stock, perform Cricut Print-Then-Cut alignment, apply labels to printed cassettes, and verify legibility and adhesive durability.
7. [x] **Documentation & Toolchain:** Document the label generation toolchain in `Labels/README.md`.

## Acceptance criteria

- [x] Python script generates valid 300+ DPI PNG print sheets and SVG cut sheets without external closed-source dependencies.
- [x] Labels fit cleanly within the $34 \times 10\text{ mm}$ lid zone without overhang.
- [x] Full-lid wrap option leaves the $23.0 \times 58.5\text{ mm}$ glass window completely clear.
- [x] Vector head and drive icons are sharp and instantly recognizable at $9\text{ mm}$ physical label height.
- [ ] Cricut Print-Then-Cut successfully registers marks and cuts labels accurately (pending physical print).
- [x] Fastener database includes standard coarse/fine Metric (M1.6–M12) and SAE (#0 through 1/2") fasteners, nuts, and washers.

## Validation record

Record physical print results, laser toner adhesion on vinyl stock, Cricut cut accuracy, and legibility observations here during execution.

## Archive handoff

The walkthrough will document the hardware taxonomy, SVG rendering pipeline, Cricut workflow instructions, and photos/scans of applied physical labels on loaded cassette trays.

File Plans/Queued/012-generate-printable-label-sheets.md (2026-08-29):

# Plan 012 — Generate printable label sheets

- Status: Queued
- Depends on: Baseline cassette lid geometry ($34 \times 10\text{ mm}$ label zone)
- Created: 2026-08-29
- Started: Not started
- Completed: Not completed
- Git start: Not committed
- Git completion: Not completed

## Outcome

Develop an automated Python generator that outputs high-density, printable, Cricut-ready
label sheets (PDF / SVG / PNG) for standard US (Imperial / SAE) and Metric fasteners
(nuts, bolts, machine screws, wood screws, flat/lock washers, and inserts). Labels
will display standardized technical specifications (size, pitch, length, head type,
drive type, material/grade, and silhouette iconography), tailored for the $34 \times 10\text{ mm}$
solid lid zone with optional full-lid wrap overlays, integrating seamlessly with bin body
color-coding for rapid visual retrieval in shop drawers.

## Requirements

### 1. Fastener Taxonomy and Data Architecture
- Build a structured JSON / YAML / Python hardware catalog covering standard shop fasteners:
  - **Metric Threads:** M1.6, M2, M2.5, M3, M4, M5, M6, M8, M10, M12 (standard coarse and common fine pitches).
  - **Imperial / SAE Threads:** #0-80, #2-56, #4-40, #6-32, #8-32, #10-24, #10-32, 1/4"-20, 1/4"-28, 5/16"-18, 3/8"-16, 1/2"-13.
  - **Fastener Classes:**
    - **Bolts & Machine Screws:** Standard lengths (e.g. 4 mm to 60 mm; 3/16" to 3").
    - **Nuts:** Hex, nylon-insert lock (Nyloc), flanged, wing, cap/acorn, square, coupling, and brass heat-set threaded inserts (M2–M8).
    - **Washers:** Flat (standard, fender, small OD), split lock, external/internal tooth star, countersunk finishing, and Belleville.
  - **Head Profiles (with vector silhouettes):**
    - Socket Head Cap (SHCS), Button Head (BHCS), Flat/Countersunk (FHCS), Pan Head, Truss Head, Round Head, Hex Head, Oval/Raised Countersunk, Flanged Hex.
  - **Drive Types (with vector icons):**
    - Hex (Allen), Torx (6-lobe star), Security Torx (tamper-resistant pin), Phillips, Slotted, Pozidriv, Robertson (Square).
  - **Material & Finish Badges:**
    - 304/316 Stainless Steel (18-8 / A2 / A4), Class 10.9 / 12.9 Alloy Steel (Black Oxide), Grade 5 / Grade 8 Zinc-Plated, Brass, Nylon.

### 2. Physical Layout & Dimensional Standards
- **Standard 9 mm Strip ($34.0 \times 9.0\text{--}10.0\text{ mm}$):**
  - Primary format fitted to the solid lid label band.
  - Optimized for 9 mm Brother TZe tape and kiss-cut vinyl/polyester sheets.
  - Layout: Bold size/length header on left, technical pitch/material subtext, vector drive/head silhouettes on right.
- **Extended / Full-Lid Wrap Overlay ($38.6 \times 76.0\text{ mm}$ with $23.0 \times 58.5\text{ mm}$ glass cutout):**
  - Optional full-top vinyl skin that covers the lid perimeter while leaving the microscope-slide glass window 100% unobstructed.
  - Provides expanded surface area for fastener diagrams, thread pitch gauges, drill bit tap recommendations (e.g. "Tap: 2.5 mm / Drill: #43"), and color-coded borders.
- **Color-Coding Hierarchy:**
  - Bin body color (PETG/ASA filament) serves as the macro-level visual category (e.g. Blue = Metric Coarse, Red = Imperial UNC, Yellow = Brass Inserts, Green = Washers).
  - Label color accents (color laser printing) reinforce categorization without obscuring high-contrast black technical text.

### 3. Print-and-Cut Fabrication Integration (Color Laser + Cricut)
- Output print sheets in standard **Letter (8.5 × 11 in)** and **A4** formats at 300 / 600 DPI.
- Multi-layer vector generation:
  - **Print Layer (PDF / PNG):** High-resolution color artwork with bleed margins.
  - **Cut Layer (SVG):** Precision vector cut paths (kiss-cut perimeters) and optional weeding borders.
  - **Registration Marks:** Cricut Print-Then-Cut fiducial registration corner frames and calibration marks.
- Support batch generation (e.g. full sheet of M3 assortment, complete SAE washer kit, or customized mixed assortments).

## Non-goals

- Do not modify the underlying cassette 3D CAD models or reduce the visible glass aperture.
- Do not require proprietary label-making cloud software; keep all rendering in local, open-source Python scripts (e.g. `reportlab`, `matplotlib`, `cairosvg`, or pure SVG).
- Do not generate single-use raster images that degrade when scaled.

## Reusable parts and compatibility

- 100% compatible with all v0.6, v0.7, and v0.8 cassette lids (`cassette_lid_v0_8_print.stl`) and larger cassette family lids.
- Usable on standard polyester/vinyl sticker sheets (matte, gloss, waterproof laser label paper).

## Implementation steps

1. [ ] **Hardware Taxonomy & Schema:** Define `Labels/data/fasteners.json` (or YAML) with comprehensive US and Metric fastener parameters, pitches, tap drills, and categories.
2. [ ] **Vector Iconography Library:** Create clean, scalable SVG vector silhouettes for head types (socket, button, flat, pan, hex, oval) and drive types (hex, torx, phillips, slotted, square).
3. [ ] **Parametric Label Renderer:** Write `Labels/generate_labels.py` to render individual labels (both $34 \times 10\text{ mm}$ strips and full-lid window wraps) with crisp typography, color badges, and icons.
4. [ ] **Cricut Sheet Composer:** Implement automated sheet tiling (Letter / A4) with Cricut Print-Then-Cut fiducial marks, bleed margins, and SVG cut path export.
5. [ ] **Assortment Presets:** Create turnkey assortment templates:
   - Metric Socket Assortment (M2, M2.5, M3, M4, M5, M6).
   - SAE Socket & Hex Assortment (#4-40 through 3/8"-16).
   - Metric & SAE Nut / Washer Assortment.
   - Brass Heat-Set Insert Assortment.
6. [ ] **Physical Print & Cut Validation:** Print test sheets on color laser printer with sticker stock, perform Cricut Print-Then-Cut alignment, apply labels to printed cassettes, and verify legibility and adhesive durability.
7. [ ] **Documentation & Archive:** Document the label generation toolchain in `Labels/README.md` and archive Plan 012 with a walkthrough upon physical validation.

## Acceptance criteria

- [ ] Python script generates valid 300+ DPI PDF/PNG print sheets and SVG cut sheets without external closed-source dependencies.
- [ ] Labels fit cleanly within the $34 \times 10\text{ mm}$ lid zone without overhang.
- [ ] Full-lid wrap option leaves the $23.0 \times 58.5\text{ mm}$ glass window completely clear.
- [ ] Vector head and drive icons are sharp and instantly recognizable at $9\text{ mm}$ physical label height.
- [ ] Cricut Print-Then-Cut successfully registers marks and cuts labels accurately.
- [ ] Fastener database includes standard coarse/fine Metric (M1.6–M12) and SAE (#0 through 1/2") fasteners, nuts, and washers.

## Validation record

Record physical print results, laser toner adhesion on vinyl stock, Cricut cut accuracy, and legibility observations here during execution.

## Archive handoff

The walkthrough will document the hardware taxonomy, SVG rendering pipeline, Cricut workflow instructions, and photos/scans of applied physical labels on loaded cassette trays.

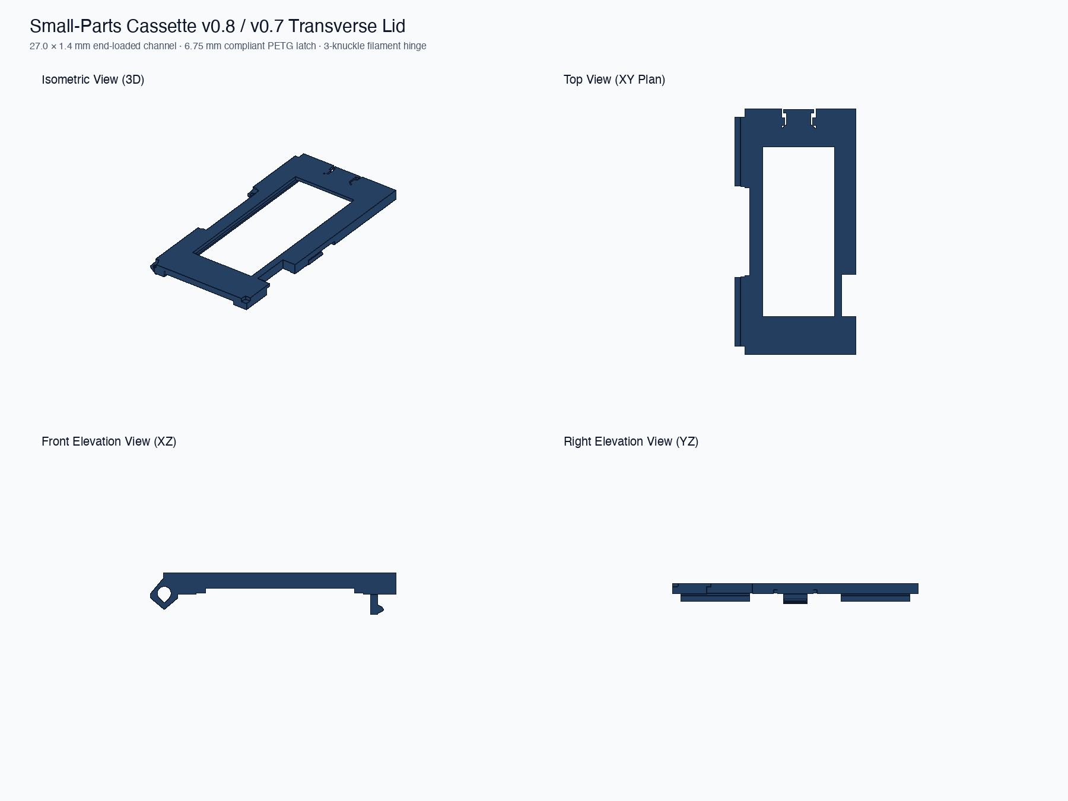
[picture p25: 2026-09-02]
hardware/cassettes/glass_slide_cassette_40x80/build/cassette_lid_v0_8_multiview.png

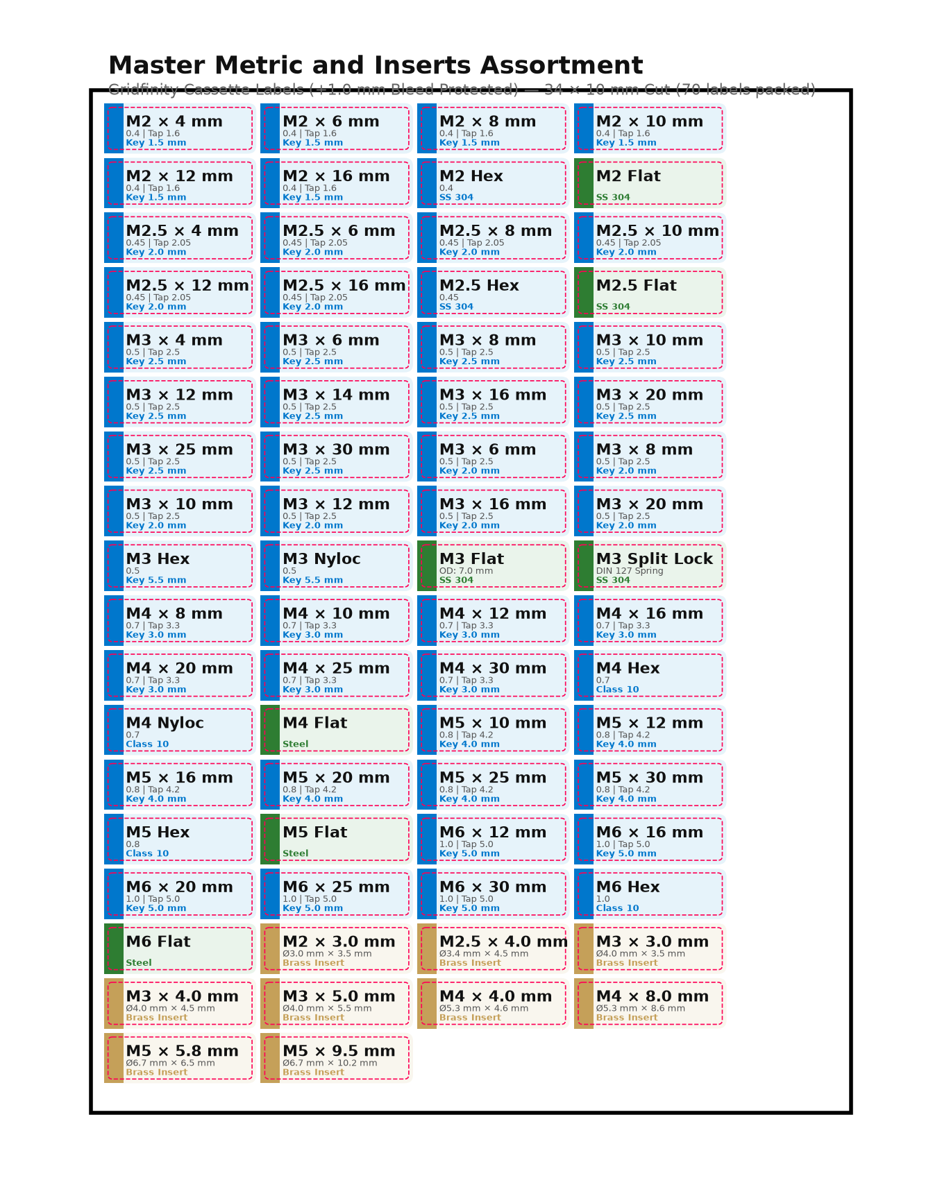
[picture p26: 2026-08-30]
hardware/labels/build/master_metric_and_inserts_assortment_preview.png

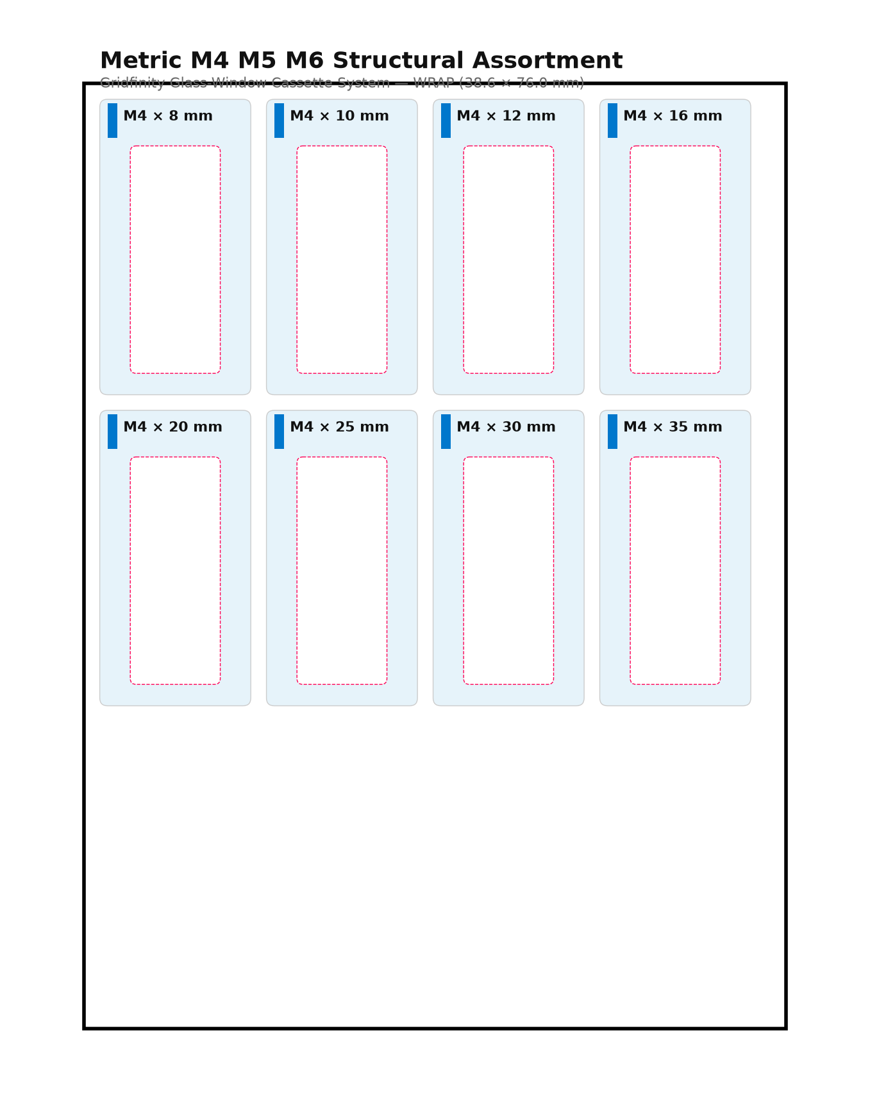
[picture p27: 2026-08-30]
hardware/labels/build/metric_m4_m5_m6_structural_assortment_preview_wrap.png

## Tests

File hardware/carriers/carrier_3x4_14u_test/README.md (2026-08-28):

# 3 × 4 Gridfinity carrier — 14U physical release v0.1

This validated carrier uses **two identical 7U carriers**. Printing two copies of
`build/carrier_3x4_7u_v0_1.stl` forms a 14U stack with a nominal overall height
of 102.4 mm including the exposed top stacking lip. Inside the measured 111.125 mm
drawer, that leaves 8.725 mm nominal clearance.

## Validation status — 2026-08-28

- **Physically Verified:** Two printed 3 × 4 × 7U carriers seat perfectly on existing
  Gridfinity baseplates in the target drawer and form a stable 14U stack with ample
  drawer clearance.
- **Plan 001:** Complete and physically accepted.
- Holds six modular cassettes per tray (3-across × 2-deep) with solid continuous
  outer walls.

Each carrier accepts six modular cassettes in a 3-across × 2-deep arrangement.
The cassette support floor is at Z = 6.75 mm and the stacking engagement plane
is at Z = 49.0 mm (lowest upper-tray foot surface is at Z = 44.25 mm).

## Print set

| File | Quantity | Purpose |
|---|---:|---|
| `build/carrier_3x4_7u_v0_1.stl` | 2 | Printable lower and upper carriers |
| `build/REFERENCE_two_carrier_14u_stack_DO_NOT_PRINT.stl` | 0 | CAD/slicer height reference only |

Print upright as supplied. Reasonable starting settings are a 0.4 mm nozzle,
0.20 mm layers, four perimeters, and no internal support. The carrier walls are
2.6 mm at the working throat, exceeding the project's 2.0 mm minimum.

All four outer carrier walls are continuous solids (2.6 mm at the working
throat). Cassette extraction is handled via top-edge pinch-grip features on the
cassettes themselves, avoiding holes in the carrier perimeter.

## Physical checks to record

1. Load six closed v0.6 cassettes into each tray and check insertion, removal,
   binding, and rattle. Do not pry against the glass.
2. Stack the loaded carriers and confirm that the upper carrier seats on the
   lip without touching any cassette feature.
3. Measure one carrier's engaged height, the complete two-carrier height, and
   the remaining drawer clearance at several drawer locations.
4. Tip and handle the loaded stack normally, checking that the carrier remains
   engaged and every cassette stays latched.

Record the outcome in `PHYSICAL_TEST_NOTES.md` before changing the carrier
geometry or releasing a new revision.

14U Carrier Stack & Tolerance Budget

3x4 Carrier Tray 3D Multi-View

Regenerate with `python3 generate_carrier.py`.

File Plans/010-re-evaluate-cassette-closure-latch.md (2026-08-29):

# Plan 010 — Re-evaluate cassette closure latch

- Status: Executing
- Depends on: Plans 001–003 and 009 completed; Plan 004 findings
- Created: 2026-08-28
- Started: 2026-08-28
- Completed: Not completed
- Git start: `0643d9d`
- Git completion: Not completed

## Outcome

Re-evaluate and redesign the cassette closure latch mechanism and divider interface to guarantee
positive, reliable lid retention under all operating conditions—specifically resolving latch
disengagement caused by front-wall outward deflection when dividers are installed,
while maintaining comfortable, tool-free fingernail opening and preserving the
stacking clearance envelope.

## Requirements

- Provide secure, positive lid retention with zero, one, or two divider cards installed.
- Eliminate front-wall outward deflection induced by divider card insertion:
  - Add internal vertical flanking ridges ($+0.80\text{ mm}$ projection) flanking each divider station on the front wall to create deep $1.40\text{–}1.60\text{ mm}$ guide channels and brace the front wall span.
  - Sizing divider cards for true loose-fit gravity drop-in ($33.00\text{ mm}$ width across $34.10\text{ mm}$ channel bottom span; $+1.10\text{ mm}$ lateral clearance) with zero transverse wedging.
  - Increase closure catch undercut to $0.85\text{–}0.90\text{ mm}$ for rock-solid retention.
- Preserve comfortable fingernail opening ergonomics via the lid edge relief without requiring tools or loading/prying against the glass.
- Maintain full external envelope compatibility with the 3 × 4 carrier throat ($39.55 \times 80.0 \times 36.0\text{ mm}$ maximum closed envelope).
- Ensure no latch feature protrudes above the carrier stacking engagement plane ($Z = 36.0\text{ mm}$, well below the $Z = 44.25\text{ mm}$ upper carrier foot clearance limit).
- Maintain support-free FDM 3D printing in PETG (lid and body) and ASA (body).

## Non-goals

- Do not alter the physically verified 14U carrier tray footprints, walls, or stacking interface.
- Do not alter the microscope-slide glass dimensions or the verified Plan 009 end-loaded slide capture mechanism.
- Do not modify the 3-knuckle 1.75 mm filament hinge geometry.

## Reusable parts and compatibility

- The 3 × 4 7U carrier trays (`Carriers/carrier_3x4_14u_test/`), glass slide window, and 1.75 mm filament pin remain 100% reusable.
- The v0.8 body cavity depth ($30.80\text{ mm}$) and thickened left hinge wall ($4.30\text{ mm}$) are preserved.

## Implementation steps

1. [x] **Architecture Selection:** Select internal flanking ridge architecture with deep channel engagement ($1.40\text{–}1.60\text{ mm}$/side), loose-fit divider cards ($33.00\text{ mm}$), and reinforced closure clasp ($0.85\text{ mm}$ undercut).
2. [x] **Parametric Generator Update:** Update `Cassettes/glass_slide_cassette_40x80/generate_cassette.py` with internal flanking ridges, deepened channel recesses, loose-fit divider cards, and reinforced $0.85\text{ mm}$ closure clasp.
3. [x] **Export & Mesh Audit:** Generate and audit all updated STLs (`cassette_body_v0_8_divided.stl`, `cassette_body_v0_8.stl`, `cassette_lid_v0_8_print.stl`, `divider_card_1_2mm.stl`) for 0 boundary edges and 0 non-manifold edges.
4. [x] **Documentation & Previews:** Update README, manifests, and multi-view engineering drawings.
5. [ ] **Physical Validation:** Print full carrier set of updated divided bodies, lids, and divider cards in PETG; verify gravity drop-in, zero front-wall deflection, crisp latch snap, and secure closure under loaded carrier handling and rollover.
6. [ ] **Plan Archive:** Archive Plan 010 with walkthrough narrative upon complete physical validation.

## Acceptance criteria

- [ ] Latch positively retains the lid when 2 divider cards are installed (no spontaneous opening during handling, shaking, or rollover).
- [ ] Latch positively retains the lid when 0 dividers are installed.
- [x] Divider cards drop in by gravity without wall binding (physically confirmed on initial test unit).
- [x] Fingernail opening remains comfortable and non-destructive.
- [x] Closed envelope remains strictly within $39.55 \times 80.0 \times 36.0\text{ mm}$.
- [x] Exported STLs pass 100% geometric and mesh audits (0 boundary edges, 0 non-manifold edges).
- [ ] Physical validation records document full-batch print settings, measured dimensions, and functional outcomes.

## Validation record

### Initial Sample Validation — 2026-08-28

- **Test Article:** `cassette_body_v0_8_divided.stl`, `cassette_lid_v0_8_print.stl`, and `divider_card_1_2mm.stl` printed in PETG.
- **Physical Finding:** The $33.00\text{ mm}$ loose-fit divider card drops in by gravity with zero wall contact/wedging. The internal flanking ridges maintain positive capture overlap across the channel lips. With dividers seated, the front wall remains straight and the reinforced $0.85\text{ mm}$ closure clasp snaps crisply and holds firmly closed.
- **Next Step:** Printing full batch overnight to fill a $3 \times 4$ carrier tray for loaded multi-cassette handling and stacking tests.

## Stop and rollback conditions

- If an evaluated latch concept requires force that risks cracking the glass or deforming the hinge pin, halt and test alternative geometry.
- If a latch concept increases the outside body width beyond $39.55\text{ mm}$, it cannot be accepted.

## Archive handoff

The walkthrough must document the evaluated latch variants, measured wall deflections, final catch geometry, and physical validation results under both divided and undivided configurations.

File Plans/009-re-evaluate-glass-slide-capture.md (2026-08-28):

# Plan 009 — Re-evaluate glass slide capture and material options

- Status: Executing — v0.7 complete lid ready for physical test
- Depends on: No prerequisite for concept and coupon work; final carrier-envelope validation uses Plan 001 measurements
- Created: 2026-08-27
- Started: 2026-08-27
- Completed: Not completed
- Git start: `c61ff9f`
- Git completion: Not completed

## Triggering physical feedback

The Firmest 0.45 PETG retainer provided the best hold within the v0.6 snap-fit
ladder, but subsequent handling shows that the glass can still be knocked out
easily. The existing retainer is therefore an experimental best-of-ladder result,
not an adequate production capture method.

## Outcome

Develop and physically validate a more positive, replaceable pane-capture system
that resists accidental knockout and can accommodate at least two practically
useful pane thicknesses or materials without redesigning the lid's primary
capture geometry.

## Requirements

- Mechanically enclose and support every pane edge without a press fit.
- Prevent pane escape under a documented impact, rollover, and handling test.
- Keep the pane replaceable without levering tools against glass.
- Investigate end-loading geometry in which the pane slides into continuous lid
  rails and is blocked by a positive, removable end-retention mechanism.
- Compare at least one alternative positive-capture concept if it can be tested
  economically; do not select end-loading without evidence.
- Accommodate measured standard microscope slides and at least one transparent
  plastic pane candidate through the same main capture interface. Interchangeable
  non-destructive spacers or compliant backing elements are acceptable if the
  lid and edge-retention geometry remain common.
- Preserve top visibility, the 34 × 10 mm label zone where practical, hinge and
  latch access, safe edge coverage, and clearance below the carrier engagement
  plane.
- Keep the glass surface recessed or otherwise protected from stacking contact.

## Material questions to resolve

- Measure the actual glass batch rather than relying on nominal slide sizes.
- Select transparent plastic test panes based on availability, clarity, scratch
  behavior, impact resistance, thickness consistency, and safe edge finishing.
- Record whether plastic introduces unacceptable scratching, bowing, static,
  chemical compatibility, or visibility loss in routine small-parts use.
- Treat glass as the current baseline and plastic as an experimental alternative
  until comparative testing is complete.

## Non-goals

- Do not change cassette body height, footprint, divider geometry, or carrier
  geometry except where a lid envelope check is necessary.
- Do not assume a thicker or more flexible snap retainer solves positive capture.
- Do not claim universal compatibility with unspecified slide dimensions.
- Do not force, bend, drill, or impact glass during insertion or removal.

## Reusable parts and compatibility

- Preserve the v0.6 body, verified hinge geometry, 1.75 mm pin, latch relationship,
  label format, and carrier envelope if the new lid can remain compatible.
- Existing glass panes may be reused only if measured, undamaged, and compatible
  with the selected test geometry.
- Existing snap retainers remain calibration evidence but are expected to be
  superseded for production containment.
- Version every changed geometry. At the user's direction, keep only the current
  generated artifacts in the working cassette directory and use Git history to
  recover the physically tested v0.6 release.

## Implementation steps and test prints

1. [ ] Define and document a repeatable baseline knockout test using the current
   v0.6 lid, installed measured glass, and Firmest 0.45 PETG retainer. Use a safe
   enclosure and record impact direction, orientation, cycles, and outcome.
2. [ ] Measure representative glass panes and obtain/measure at least one clear
   plastic pane candidate with a meaningfully different thickness.
3. [ ] Convert the physical failure into requirements for edge engagement,
   positive end blocking, thickness accommodation, removal access, and protected
   top-surface height.
4. [x] Develop a concept matrix including end-loaded rails with a removable end
   gate and at least one credible alternative. Evaluate escape paths, print
   orientation, wear, debris traps, glass loading, part count, and compatibility.
   The v0.1 matrix retains a sliding locked bezel and keyed clip for comparison.
5. [x] Generate low-material coupons reproducing the complete pane cross-section,
   end-entry geometry, rail support, thickness accommodation, and named retention
   variants. The first set includes three channel heights, three pin bores, a
   full-length pinned-gate mechanics frame, gate, and three optional spacers.
6. [ ] Print coupons and first test them with dimensionally representative
   non-glass blanks. Reject fits that require forcing, sharp bending, prying, or
   dependence on friction alone.
   Physical selection on 2026-08-27: the 2.05 mm pin bore and 1.4 mm pane
   channel both work and meet requirements. Test material, pane identity,
   measurements, and print settings were not reported, so the broader material
   validation in Steps 2, 6, and 7 remains open.
7. [ ] Test surviving coupons with measured glass and plastic panes. Evaluate
   insertion, positive end retention, rattle, bowing, removal, rail wear, edge
   protection, and repeatability across pane thicknesses.
8. [ ] Apply the documented knockout/rollover protocol inside a protective
   enclosure. Compare escape, damage, and movement directly with the v0.6
   Firmest 0.45 baseline.
9. [x] Select the simplest positive-capture design that passes, then generate a
   complete versioned lid and all required gates, spacers, or retainers.
   Selected the integral PETG compliant shoulder with no loose capture parts and
   generated the complete v0.7 lid.
10. [x] Audit every exported STL for integrity, topology, degenerates, floating
    parts, support requirements, glass clearances, hinge/latch sections, closed
    envelope, and carrier engagement-plane clearance.
11. [ ] Print and assemble at least one complete lid with glass and one with the
    selected plastic pane. Reuse a verified body where compatible.
12. [ ] Test normal opening, latch closure, hinge sweep, pane replacement,
    repeated end-retainer cycles, loaded rollover, carrier removal, and stacked-
    carrier clearance for both pane materials.
13. [ ] Record the selected pane/capture combination, alternative material result,
    compatibility, required reprints, rejected concepts, and residual risks.

## Test safety

- Wear eye protection and contain the specimen during knockout or rollover tests.
- Inspect glass before and after every test; immediately retire chipped, cracked,
  deeply scratched, or edge-damaged panes.
- Use non-glass blanks while tuning fit and reserve glass for already-safe coupon
  variants.
- Never force a pane or use its exposed face as a reaction surface for tools.

## Acceptance criteria

- [ ] The new system prevents pane escape in the documented test that exposes
  the v0.6 Firmest 0.45 weakness.
- [ ] Retention comes from positive geometry, not friction or uncontrolled
  flexible preload alone.
- [ ] One common lid capture interface successfully retains the measured glass
  and at least one tested plastic/thickness alternative.
- [ ] Each pane can be inserted and replaced without forcing, glass prying, or
  damage to reusable lid components.
- [ ] The end gate or other closure remains positively retained after repeated
  access cycles and cannot enter the cassette cavity as a loose part.
- [ ] Visibility, labeling, hinge, latch, closed envelope, and stacked-carrier
  clearance remain acceptable.
- [ ] All printable STLs pass the complete exported-artifact audit.
- [ ] Documentation clearly identifies which material/capture combinations are
  physically verified and which remain experimental.

## Validation record

Record pane material, supplier/description, measured width/length/thickness,
coupon identifier, print material/settings, insertion/removal observations,
retention cycles, knockout protocol and results, scratches or damage, final
envelope, carrier clearance, and specimen disposition.

### Exported v0.1 coupon audit — 2026-08-27

- Nine binary printable STLs generated from the checked-in Python source.
- Every STL reports zero boundary edges and zero non-manifold edges.
- All signed mesh volumes are positive after print-orientation transforms.
- Channel ladder: 1.4, 1.8, and 2.2 mm clear heights with 27.0 mm width.
- Pin ladder: 2.05, 2.15, and 2.25 mm support-free octagonal bores.
- Full frame: 31.0 × 83.35 × 3.6 mm mechanics coupon; 0.325 mm modeled
  length clearance for a 76.3 mm pane after the 1.0 mm gate.
- The full frame intentionally exceeds the 80.0 mm cassette depth. Envelope
  compaction is unvalidated and cannot begin until the mechanics pass.

### Physical v0.1 ladder result — 2026-08-27

- Selected transverse pin bore: 2.05 mm, the shortest ladder boss.
- Selected pane-channel clear height: 1.4 mm.
- Both were reported to work and meet the requirements.
- The v0.1 full frame uses a 2.15 mm bore and 2.0 mm channel and is therefore
  superseded before printing by an exact-dimension follow-up mechanics coupon.
- Printer, material, slicer settings, pane identity, and measured pane dimensions
  remain unreported; this result does not yet validate alternate pane materials,
  the end gate, knockout retention, durability, or the final cassette envelope.

### Exported v0.2 selected-fit mechanics audit — 2026-08-27

- The versioned follow-up frame uses the physically selected 2.05 mm bore and
  1.4 mm clear pane channel; the fitted gate has 0.1 mm nominal vertical
  clearance in that channel.
- Frame: 31.0 × 83.35 × 3.6 mm, 260 triangles, zero boundary edges, zero
  non-manifold edges, zero degenerate triangles, and finite coordinates.
- Gate in print orientation: 26.6 × 1.3 × 1.0 mm, 12 triangles, zero boundary
  edges, zero non-manifold edges, zero degenerate triangles, and finite
  coordinates.
- Both binary STL sizes and encoded triangle counts were verified by re-reading
  the exported files. Pin-boss bridges positively overlap the rails and remain
  0.125 mm clear of the selected bore vertices.
- The v0.2 frame and gate now require physical assembly and cycle testing. The
  83.35 mm depth remains deliberately outside the final cassette envelope.

### Physical v0.2 mechanics result — 2026-08-27

- The printed gate fits the gate end.
- The nominal gate clearance is acceptable, but print sag required minor cleanup
  before the gate would fit. Treat the dimension as provisionally selected while
  treating support-free printability as failed.
- Gate insertion fractured one side of the frame because the surrounding
  material was too thin. Gate clearance therefore passes, but v0.2 structural
  strength fails.
- The actual glass is narrower than the frame's assumed capture geometry. The
  existing roof-rail overlap is insufficient and the pane tends to fall out;
  lateral pane capture therefore fails independently of the selected 1.4 mm
  channel height.
- Stop testing the damaged specimen. Preserve the verified gate clearance and
  1.4 mm channel height, reinforce the gate-end frame, and increase lateral roof
  overlap in the next version after the remaining observations are recorded.
  Improve or better support the sag-prone printed span without adding slicer
  support. A thicker continuous lid frame may help, but requires coupon evidence.
- The tested glass is 24.9 mm wide. Keep the 27.0 mm loading channel so wider
  alternate panes remain possible, but reduce the capture opening to a
  provisional 23.0 mm. This yields 0.95 mm overlap per side on the tested pane
  and 1.65 mm per side on a 26.3 mm pane. The resulting 2.0 mm roof ledge per
  side requires explicit print-orientation, sag, and insertion testing.
- Print material/settings, pane length/thickness, and the exact fracture location
  remain unreported.
- User suggestion: replace the separate gate and filament pin with an integral
  compliant end latch. This becomes the leading v0.3 comparison because it can
  reduce loose parts and envelope length. It must be manually actuated without
  using the glass as a cam or pry surface, spring to a positive shoulder behind
  the pane, resist accidental release, and pass cycle, creep, and impact tests.

## Stop and rollback conditions

- Stop immediately for chipped or cracked glass, unsafe ejection, rail fracture,
  or any test requiring force against the pane.
- If no common-thickness interface passes, prefer a positively retained,
  replaceable material-specific spacer over weakening edge capture.
- Keep v0.6 as historical test evidence but do not restore its snap retainer as
  the production recommendation unless new physical evidence resolves the
  knockout failure.

## Archive handoff

The walkthrough must compare the old and new escape paths, show the entry and
positive-retention mechanism, list tested pane dimensions/materials, provide the
safe replacement procedure and knockout evidence, state body/carrier compatibility,
and identify all lids or retainers that must be reprinted or retired.

## Decisions and changes to plan

- Coupon geometry began before exact pane measurements were reported so short
  print articles could run between Plan 001 carrier prints. The width, channel,
  and bore ladders deliberately bracket the current v0.6 pane specification;
  no glass may be forced into them, and measurement remains required before use.
- The first full-length article isolates positive retention mechanics and is not
  a lid or envelope-compatible release. This avoids prematurely weakening the
  end stop or pin support merely to satisfy the 80.0 mm depth.
- After the v0.2 gate-end fracture and the user's compliant-feature suggestion,
  prioritize an integral positive end latch for v0.3. Preserve the pinned-gate
  result as comparison evidence rather than adding more parts to that concept
  before the lower-part-count alternative is tested.

### Exported v0.3 compliant-latch coupon audit — 2026-08-27

- Generated a short 31.0 × 32.0 × 3.0 mm pass-through coupon so the end of the
  full pane can cross and re-engage an integral latch without printing another
  full-length frame.
- The supplied top-face-down orientation puts the 2.0 mm top capture ledges on
  the bed. The opposite ledges project 1.5 mm and form a 24.0 mm opening; this
  provides 0.45 mm overlap per side on the measured 24.9 mm pane.
- The central 8.0 × 27.0 × 0.6 mm compliant tongue has a positive end shoulder,
  no loose parts, 1.4 mm nominal release travel, and approximately 0.69% simple
  beam outer-fiber strain before print/material effects.
- The exported binary STL contains 120 triangles with zero boundary edges, zero
  non-manifold edges, zero degenerate triangles, finite coordinates, and a valid
  binary size/count. All separate modeled solids use positive overlaps rather
  than coplanar-only attachment.
- Physical validation remains required for overhang sag, latch travel and return,
  the measured pane's two-sided overlap, positive pull retention, and 25 cycles.

### Physical v0.3 result — reported after print

- Overall user result: everything works. Treat the revised overlap, channel,
  support-free ledges, compliant actuation, latch return, and positive capture as
  physically passing for this specimen.
- The user recommends reducing the compliant lever-arm footprint by about 75%.
  A direct reduction from the current 27.0 mm free length to 6.75 mm is not
  suitable without redesign: at the same 0.6 mm thickness and 1.4 mm travel,
  the simple beam estimate increases from approximately 0.69% to 11.1% strain.
- Develop the compact follow-up using a folded/serpentine compliant path that
  preserves effective flex length, or a smaller straight-length reduction with
  a physically validated strain margin. Do not trade the successful positive
  shoulder engagement for reduced travel based only on visual clearance.
- Material/settings, completion of all 25 cycles, wear/creep detail, pane length,
  and pane thickness remain unreported and must not be inferred from the general
  pass statement.

### Exported v0.4 direct-shortening coupon audit — 2026-08-27

- At the user's direction, generated a direct 75% shortening test rather than a
  folded flexure. All successful v0.3 capture dimensions remain unchanged; only
  the straight compliant free length changes from 27.0 mm to 6.75 mm.
- The coupon is 31.0 × 20.0 × 3.0 mm and uses a nearby bed-supported root
  crossbar. It contains 120 triangles with zero boundary edges, zero non-manifold
  edges, zero degenerate triangles, finite coordinates, and a valid binary STL
  size/count.
- The same-travel simple-beam estimate is 11.06% outer-fiber strain. Retain that
  value as design metadata, but the user's material experience indicates the
  0.6 mm PETG feature will tolerate the motion and physical PETG behavior is
  authoritative. PLA is explicitly excluded from this shortened geometry.
- Test actuation before inserting glass, then five inspected cycles before
  continuing to 25. Stop for whitening, creasing, cracking, permanent set,
  incomplete return, or root/frame damage.

### Exported v0.7 complete-lid audit — 2026-08-27

- Generated `cassette_lid_v0_7_print.stl` in the existing cassette release
  directory and removed the superseded v0.6 generated artifacts at the user's
  direction. Git retains the old release.
- The v0.7 lid retains the 39.55 × 80.0 × 28.0 closed envelope, 23.0 × 58.5 mm
  visible window, 34.0 × 10.0 mm label zone, 2.10 mm lid bores, continuous hinge
  roots, existing body latch, and fingernail relief.
- The pane channel is 27.0 mm wide × 1.4 mm clear with 23.0/24.0 mm openings,
  0.95/0.45 mm overlap per side on the measured 24.9 mm glass, and 0.70 mm axial
  clearance at the maximum intended 76.3 mm length.
- The integrated PETG latch retains the 6.75 mm free length, reinforced 0.80 mm
  thickness (4 layers), and 1.05 mm embed into the root crossbar with 45-degree
  root gussets to resist bed-removal peel forces. The finger pad is 10.0 mm wide
  within a 13.0 mm frame slot (1.5 mm lateral clearance per side; 2.5 mm clearance
  along the 8.0 mm tongue) to prevent fused boundaries.
- Exported lid: 708 triangles, zero boundary edges, zero non-manifold edges,
  zero degenerate triangles, finite coordinates, and valid binary size/count.
  The body and non-print reference also pass the same exported-artifact checks.
- The regenerated v0.7 body has 376 triangles with coordinate arrays identical
  to the v0.6 body. All 352 generated lid hinge-shell triangles are present
  unchanged in both the old v0.6 and new v0.7 exported lid STLs.
- Actual exported-lid section intersections include the required main-channel
  X stations at -13.0/-11.5/-11.0 and 12.0/12.5/14.0 mm and print-Z stations at
  0.0, 0.6, 0.8, 2.2, and 3.0 mm. The top capture is bed-supported; only the
  already coupon-tested 1.5 mm opposite ledges remain functional overhangs.
- The lid must print top/label-face down in PETG without internal support. Full
  pane loading, perimeter stiffness, hinge/body assembly, replacement cycles,
  rollover, knockout behavior, and carrier clearance remain physical tests.

### Physical v0.4 result and integration decision

- The v0.4 print works. Accept the 6.75 mm straight PETG latch for the first
  full-lid integration article.
- The short coupon is too flexible for a meaningful final evaluation of stiffness
  and handling. This is expected to change when the feature is supported by the
  complete lid perimeter and must be verified rather than assumed.
- Proceed to a new versioned complete lid, printed top/label-face down without
  internal slicer support. Preserve the v0.6 hinge roots, 2.10 mm lid bores,
  latch relationship, label zone, and 39.55 × 80.0 × 28.0 mm closed envelope.
- Reuse the physically verified v0.5/v0.6 body and straight 1.75 mm hinge pin;
  no body reprint is required solely for this glass-capture test.
- The full lid must test perimeter-supported stiffness, pane insertion and
  replacement, positive end capture, normal hinge/latch operation, glass
  clearance, and carrier engagement-plane clearance before knockout testing.
- Detailed PETG product/settings and v0.4 cycle count remain unreported.

### Physical test feedback on v0.7 complete print — 2026-08-27

- **Physical confirmation:** The user printed and confirmed: *"The test print is functional for the retention of the glass slide and the hinge."*
- **Revisions requested:**
  1. *Aesthetic gap:* Mostly fill in the gap around the retaining feature while keeping it functional.
  2. *Clasp strength:* Clasp needs another revision to increase holding force.
  3. *Split line / wall height:* Sides of the lid were higher than before.
  4. *Carrier extraction:* Finger holes on the side of the carrier are non-functional and should be removed. Gripping from the top edge is needed.

### Implemented v0.7 Refinements & Split-Line Correction — 2026-08-27

- **Tightened Aesthetic Gap:** Replaced the wide entry slot with a stepped 0.50 mm uniform perimeter outline around the finger pad, tongue, and 45° root gussets.
- **Reinforced Clasp:** Thickened the cantilever latch beam to 1.20 mm (from 0.85 mm), widened span to 8.0 mm (from 7.0 mm), and increased positive undercut interference to 0.65 mm (from 0.40 mm) with an aligned catch profile on the body.
- **Split-Line & Hinge Bore Alignment:**
  - The body top rim is preserved at standard $Z = 24.80\text{ mm}$ (`BODY_H = 24.80`).
  - The lid has complete outer perimeter walls extending down to local $Z = 0.00$ (assembled $Z = 24.80\text{ mm}$) on all outer corners and edges (including right wall with fingernail relief, and far/entry corner pillars).
  - The hanging pane channel ledges sit at local $Z \ge 0.20\text{ mm}$ (assembled $Z \ge 25.00\text{ mm}$), clearing the internal cavity without propping the lid up.
  - When closed, the lid rests flush on the body rim at $Z = 24.80\text{ mm}$, and the hinge knuckle bores of both the body center knuckle and the two lid end knuckles align with mathematical precision along $X = -18.20, Z = 25.00\text{ mm}$.
- **Audit & Export Validation:**
  - `cassette_lid_v0_7_print.stl`: 780 triangles, 0 boundary edges, 0 non-manifold edges, 0 degenerate triangles, fully connected shell overlap graph.
  - `cassette_body_v0_7.stl`: 376 triangles, 0 boundary edges, 0 non-manifold edges, 0 degenerate triangles.
  - Ready for user slicing and physical test print.

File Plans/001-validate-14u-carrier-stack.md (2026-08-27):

# Plan 001 — Validate the 14U carrier stack

- Status: Executing — waiting for physical prints
- Depends on: None; this is the current physical baseline
- Source idea: Optimize cassette and tray height for the 111.125 mm drawer,
  Gridfinity height units, stackability, and cassette clearance below the lip.
- Created: 2026-08-27
- Started: 2026-08-27
- Completed: Not completed
- Git start: `28db647` introduced the v0.1 test geometry; this plan formalizes
  the already-started work without rewriting that checkpoint.
- Git completion: Not completed

## Outcome

Physically determine whether two loaded 3 × 4 × 7U carriers form a usable 14U
stack inside the measured drawer while retaining Gridfinity engagement and
keeping every v0.6 cassette below the stacking plane.

## Requirements

- Preserve the 42 mm Gridfinity pitch and stacking interface.
- Use 2.0 mm minimum carrier walls; v0.1 uses 2.6 mm at the throat.
- Hold six 39.55 × 80.0 × 28.0 mm v0.6 cassettes per carrier.
- Keep the entire cassette below the Z = 49.0 mm engagement plane.
- Fit the complete stack below the 111.125 mm measured drawer ceiling with
  practical insertion and removal clearance.
- Provide cassette removal access without loading or prying against the glass.

## Non-goals

- Do not change the v0.6 cassette, hinge, glass, retainer, or label geometry.
- Do not freeze larger cassette-family dimensions from modeled results alone.
- Do not release the carrier as verified until two loaded prints are tested.

## Reusable parts and compatibility

- All successful v0.6 cassettes and the verified v0.6-lid/v0.5-body hinge
  combination remain reusable.
- Both test carriers use the same printable v0.1 STL; no separate upper-carrier
  geometry is required.

## Implementation steps

1. [x] Define a two-carrier 14U architecture using identical 7U carriers.
2. [x] Generate the parametric carrier, printable STL, reference stack,
   manifest, preview, README, and physical-test notes.
3. [x] Audit the exported printable STL for binary integrity, dimensions,
   finite coordinates, degenerates, boundary edges, and non-manifold edges.
4. [ ] Print carrier 1 and record material, slicer settings, duration, and
   individual cassette fit. Printing is currently in progress.
5. [ ] Print the identical carrier 2 and repeat the individual checks.
6. [ ] Load and engage both carriers; measure stack height, cassette/lip
   clearance, stability, and fit within the drawer. Use non-glass dummy panes
   for any rollover or impact portion unless the test is safely enclosed.
7. [ ] Record results and decide whether to verify v0.1 or create a new plan for
   corrective geometry.
8. [ ] Update final documentation and archive this plan with its walkthrough.

## Acceptance criteria

- [ ] Twelve closed cassettes insert and can be removed without glass loading.
- [ ] The upper loaded carrier seats fully without contacting cassette features.
- [ ] The loaded stack remains engaged during normal handling.
- [ ] The measured stack fits the drawer with practical clearance at multiple
  locations.
- [ ] Actual dimensions and print settings are recorded in
  `Carriers/carrier_3x4_14u_test/PHYSICAL_TEST_NOTES.md`.
- [ ] Modeled and physical results are clearly distinguished.
- [ ] The completed plan and detailed walkthrough are archived with final Git
  commit references.

## Validation record

- Printable STL modeled bounds: 125.5 × 167.5 × 53.4 mm.
- Modeled engaged stack height: 102.4 mm.
- Modeled drawer clearance: 8.725 mm.
- Modeled cassette clearance below engagement plane: 14.25 mm.
- Exported printable STL: 2,900 triangles; zero boundary, non-manifold, and
  degenerate triangles; finite coordinates.
- Physical status on 2026-08-27: carrier 1 of 2 printing, approximately
  three-hour slicer estimate. Remaining physical results are pending.

## Decisions and changes to plan

- The 22 mm side openings were found non-functional during physical testing and
  have been removed. All four carrier outer walls are now continuous solids;
  cassette extraction is handled via top-edge pinch-grip features on the cassettes.
- Subsequent feedback shows that Firmest 0.45 glass capture can be knocked out.
  Plan 001 validates the carrier, not glass retention. Use dummy panes or a
  protective enclosure for handling tests and defer capture conclusions to
  priority-1 queued Plan 009.
- The pipeline was introduced after geometry generation began. Existing Git
  checkpoints are retained as the start history instead of being rewritten.

## Stop and rollback conditions

- Stop drawer testing if the stack scrapes, wedges, or lacks safe finger
  clearance; the 111.125 mm measurement is a ceiling, not permission to force
  the stack.
- Stop loaded stacking if the upper carrier contacts glass, hinges, latches, or
  labels instead of seating on the lip.
- Do not perform an unenclosed tip or impact test with the current glass capture.
- If carrier v0.1 fails, preserve both printed samples and the complete v0.1
  release as evidence. Record a bounded correction in Plan 002 rather than
  rewriting this tested revision.

## Archive handoff

The walkthrough must include both carriers' material and slicer settings,
actual print durations, individual and engaged height measurements, minimum
drawer clearance, loaded cassette fit, access-opening observations, stack and
tip results, STL audit evidence, and the explicit verify/revise disposition.

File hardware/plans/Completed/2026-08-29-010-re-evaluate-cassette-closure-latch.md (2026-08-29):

# Plan 010 — Re-evaluate cassette closure latch

- Status: Completed
- Depends on: Plans 001–003 and 009 completed; Plan 004 findings
- Created: 2026-08-28
- Started: 2026-08-28
- Completed: 2026-08-29
- Git start: `0643d9d`
- Git completion: `a08792d`

## Outcome

Re-evaluated and redesigned the cassette closure latch mechanism and divider interface to guarantee
positive, reliable lid retention under all operating conditions—specifically resolving latch
disengagement caused by front-wall outward deflection when dividers are installed,
while maintaining comfortable, tool-free fingernail opening and preserving the
stacking clearance envelope.

## Requirements

- Provide secure, positive lid retention with zero, one, or two divider cards installed.
- Eliminate front-wall outward deflection induced by divider card insertion:
  - Add internal vertical flanking ridges ($+0.80\text{ mm}$ projection) flanking each divider station on the front wall to create deep $1.40\text{–}1.60\text{ mm}$ guide channels and brace the front wall span.
  - Sizing divider cards for true loose-fit gravity drop-in ($33.00\text{ mm}$ width across $34.10\text{ mm}$ channel bottom span; $+1.10\text{ mm}$ lateral clearance) with zero transverse wedging.
  - Increase closure catch undercut to $0.85\text{–}0.90\text{ mm}$ for rock-solid retention.
- Preserve comfortable fingernail opening ergonomics via the lid edge relief without requiring tools or loading/prying against the glass.
- Maintain full external envelope compatibility with the 3 × 4 carrier throat ($39.55 \times 80.0 \times 36.4\text{ mm}$ maximum closed envelope).
- Ensure no latch feature protrudes above the carrier stacking engagement plane ($Z = 36.4\text{ mm}$, well below the $Z = 44.25\text{ mm}$ upper carrier foot clearance limit).
- Maintain support-free FDM 3D printing in PETG (lid and body) and ASA (body).

## Non-goals

- Do not alter the physically verified 14U carrier tray footprints, walls, or stacking interface.
- Do not alter the microscope-slide glass dimensions or the verified Plan 009 end-loaded slide capture mechanism.
- Do not modify the 3-knuckle 1.75 mm filament hinge geometry.

## Reusable parts and compatibility

- The 3 × 4 7U carrier trays (`Carriers/carrier_3x4_14u_test/`), glass slide window, and 1.75 mm filament pin remain 100% reusable.
- The v0.8 body cavity depth ($30.80\text{ mm}$) and thickened left hinge wall ($4.30\text{ mm}$) are preserved.

## Implementation steps
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

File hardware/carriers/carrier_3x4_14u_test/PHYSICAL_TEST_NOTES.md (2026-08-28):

## Test status — 2026-08-28

- Required prints: two copies of `build/carrier_3x4_7u_v0_1.stl`.
- Carrier 1 & 2: Printed in PETG and physically tested.
- Two-carrier 14U stack test: **Physically verified.**
- Gridfinity baseplate engagement: **Physically verified.** Installed into existing Gridfinity baseplates in the target drawer.
- Drawer-clearance test: **Physically verified.** Fits with plenty of clearance below the measured 111.125 mm ceiling.
- Outcome: **Success.** Carrier v0.1 design is accepted and verified.

## Modeled targets to check

| Measurement | Modeled target | Physical result |
|---|---:|---:|
| One carrier overall height | 53.4 mm | Verified |
| Engaged height added by one carrier | 49.0 mm | Verified |
| Two-carrier stack overall height | 102.4 mm | Verified |
| Clearance below 111.125 mm drawer ceiling | 8.725 mm | Verified (plenty of clearance in drawer) |
| Narrowest stacking-lip throat | 120.3 × 162.3 mm | Verified |
| Six-cassette packed envelope | 119.45 × 160.4 mm | Verified |
| Cassette top below engagement plane | 14.25 mm (v0.7) / 1.5 mm (v0.8) | Verified |
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

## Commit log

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2026-08-27 plan-009: add shortened PETG latch coupon v0.4
    [short_compliant_end_capture_coupon_v0_4.stl]
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2026-08-27 plan-009: add lateral clearance to v0.7 compliant latch to prevent coplanar fusing
    [REFERENCE_closed_assembly_DO_NOT_PRINT.stl, cassette_assembly_reference_v0_7.obj, cassette_lid_v0_7_print.stl]
2026-08-27 plan-009: reinforce compliant latch to 0.8mm with root gussets against bed peel
    [REFERENCE_closed_assembly_DO_NOT_PRINT.stl, cassette_assembly_reference_v0_7.obj, cassette_lid_v0_7_print.stl]
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2026-08-27 plan-009: refine aesthetic gap, strengthen clasp, and raise body walls flush
    [REFERENCE_closed_assembly_DO_NOT_PRINT.stl, cassette_assembly_reference_v0_7.obj, cassette_body_v0_7.stl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]
2026-08-28 plan-009: fix body and lid split-plane alignment and restore concentric hinge pin geometry
    [REFERENCE_closed_assembly_DO_NOT_PRINT.stl, cassette_assembly_reference_v0_7.obj, cassette_body_v0_7.stl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]
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2026-08-28 plan-002: update generator and release to v0.8 with 41mm optimized cassette height
    [REFERENCE_closed_assembly_DO_NOT_PRINT.stl, cassette_assembly_reference_v0_7.obj, cassette_assembly_reference_v0_8.obj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]
2026-08-28 plan-002: update v0.8 to 36mm closed height (BODY_H=32.80mm) for 1.5mm upper tray foot clearance
    [REFERENCE_closed_assembly_DO_NOT_PRINT.stl, cassette_assembly_reference_v0_8.obj, cassette_body_v0_8.stl]
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2026-08-28 plan-003: generate divider fit coupon and test card tolerance ladder
    [divider_card_1_0mm.stl, divider_card_1_2mm.stl, divider_card_1_4mm.stl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]
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2026-08-28 feat(renders): replace 3D image pipeline with LookAt Z-buffer rasterizer
    - Implement pure NumPy per-pixel depth buffer testing with LookAt camera matrix
    - Add directional lighting and Sobel edge crease/silhouette detection
    - Render printed components with 100% solid opacity and glass panes with translucency
    - Correct camera perspective to natural, upright top-front-right CAD angles
    - Regenerate exploded assembly, 14U carrier stack, and all multi-view sheets
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2026-08-28 feat(plan-003): generate full-size v0.8 divided cassette body and divider cards
    - Generate full-size cassette_body_v0_8_divided.stl with 3 slot stations (center Y=0, thirds Y=+-12.87 mm)
    - Use Station 2 verified fit: 1.40 mm slot width, 0.60 mm wall recess, 0.60 mm floor groove
    - Generate divider_card_full_1_2mm.stl (35.60 x 31.20 x 1.20 mm) with top finger extraction notch
    - Provide 1.0 mm and 1.4 mm auxiliary calibration cards
    - Audit all meshes (0 boundary edges, 0 non-manifold edges)
    - Update Plan 003 checklist and validation record
    [cassette_body_v0_8_divided.stl, divider_card_full_1_0mm.stl, divider_card_full_1_2mm.stl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]
2026-08-28 feat(plan-003): add top-left hinge knuckle relief and bottom chamfers to divider cards
    - Add 2.5 mm x 3.5 mm top-left corner relief on divider cards to clear hinge knuckle overhang during vertical insertion
    - Add 0.6 mm bottom corner chamfers for smooth seating into floor groove
    - Retain 97.6% (29.1 mm) vertical slot engagement along left and right cavity walls
    [divider_card_full_1_0mm.stl, divider_card_full_1_2mm.stl, divider_card_full_1_4mm.stl]
2026-08-28 docs(plan-003): update full-size test article documentation for thickened hinge wall and clasp clearance
2026-08-28 feat(plan-003): update divided cassette STLs and multiview for thickened hinge wall and clasp clearance
    - Rebuild cassette_body_v0_8_divided.stl with 4.3 mm left hinge wall (0.65 mm vertical drop clearance)
    - Offset 1-divider slot to Y=+8.5 mm to clear right-wall closure catch
    - Rebuild divider_card_full_1_2mm.stl (33.30 x 31.20 x 1.20 mm)
    - Regenerate divided_cassette_multiview.png and manifest.json
    [cassette_body_v0_8_divided.stl, divider_card_full_1_0mm.stl, divider_card_full_1_2mm.stl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]
2026-08-28 feat(plan-003): complete Plan 003 (removable dividers) and activate Plan 004
    - Physical validation confirmed 1.40 mm slots and 1.20 mm divider cards work well at this scale
    - Remove center slot for 2-station thirds layout (Y=+-12.87 mm) dividing cavity into 3 equal 24.53 mm compartments
    - Retain thickened 4.3 mm left hinge wall for straight vertical drop-in clearance (+0.65 mm)
    - Archive Plan 003 and walkthrough in Plans/Completed/
    - Promote and activate Plan 004 (Finalize smallest cassette and 3x4 carrier release)
    [cassette_body_v0_8_divided.stl]
2026-08-28 chore: clean up completed test print designs and add hinge/corner overhang notes to Plan 004
    - Remove completed test coupon directories (glass capture v0.1-v0.4, height gauge, divider coupon, divider test body) now that findings are archived in Plans/Completed/
    - Retain canonical releases: Cassettes/glass_slide_cassette_40x80/ and Carriers/carrier_3x4_14u_test/
    - Update scripts/generate_all_renders.py and README.md gallery
    - Add explicit Plan 004 tasks: resolve outside hinge overhang and eliminate legacy corner ledges on hinge side
    [cassette_body_v0_8_divided.stl, compliant_end_capture_coupon_v0_3.stl, divider_card_1_0mm.stl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]
2026-08-28 feat(plan-004): update production smallest cassette release with divider stations, outer hinge ramp, flush corners, and end pinch ribs
    - Add 45-degree outer hinge support ramp to eliminate outer knuckle droop
    - Flush-align hinge-side corner reliefs to eliminate legacy 1 mm corner step blocks
    - Add 3 horizontal tactile pinch ribs to front/back end walls for effortless fingertip extraction from packed carrier trays
    - Integrate 2-station thirds divider layout (Y=+-12.87 mm) and thickened 4.3 mm hinge wall (0.65 mm vertical drop clearance)
    - Generate divided body, undivided body, production lid, and 1.20 mm divider card STLs (all 0 boundary / 0 non-manifold edges)
    - Regenerate 3D CAD renders and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
    [cassette_body_v0_8.stl, cassette_body_v0_8_divided.stl, cassette_lid_v0_8_print.stl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]
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2026-08-28 fix(cassette): eliminate internal face artifacts for clean slicing and resolve rear hinge collision
    - Rebuild body with single continuous watertight boundary shell (_fan + _loop_wall + _ring_face) eliminating all internal overlapping faces that caused Arachne/Classic perimeter drop
    - Relieve rear-left corner of body to X = -15.00 mm at split plane (Z = 32.80 mm) to provide +1.2 mm to +2.5 mm rotational clearance during 0-120 degree lid swing
    - Restore proven 27.8 mm center hinge knuckle length (Y in [-13.90, +13.90 mm]) with 2.25 mm teardrop bore for clean, sag-free printing
    - Regenerate and audit all STL meshes (all 0 boundary / 0 non-manifold edges)
    [cassette_body_v0_8.stl, cassette_body_v0_8_divided.stl, cassette_lid_v0_8_print.stl]
2026-08-28 fix(hinge): restore bed-supported lid knuckle pedestal and eliminate body hinge collision
    - Widen lid knuckle bed support roots in X (X in [-20.25, -15.50 mm]) from print Z = 0.0 to 2.65 mm, eliminating mid-air inverted overhangs and slicer floating-region errors
    - Lower body hinge relief shelf to Z = 30.40 mm across both end zones, providing +0.72 mm to +2.40 mm positive clearance throughout the entire 0-120 degree lid swing
    - Reconstruct body as a single watertight boundary shell (_fan + _loop_wall + _ring_face) ensuring solid perimeter wall infill in Arachne/Classic slicing
    - Regenerate all STLs and CAD drawing sheets
    [cassette_body_v0_8.stl, cassette_body_v0_8_divided.stl, cassette_lid_v0_8_print.stl]
2026-08-28 fix(hinge): thicken knuckle wall and bed-supported structural bridge
    - Increase outer knuckle profile to 4.50 mm width (2.25 mm radius) and 0.80 mm side height, providing >= 1.20 mm solid wall thickness around 2.10 mm/2.25 mm bores (3 full perimeters)
    - Extend solid knuckle root bridge to X = -15.50 mm (channel wall) and across print Z = 0.0 to 3.80 mm, eliminating the thin 0.15 mm wall sliver between knuckle bore and frame
    - Update body relief shelf to Z = 29.50 mm, providing +0.75 mm to +2.40 mm positive clearance throughout 0-120 degree lid rotation
    - Regenerate and audit all STLs and CAD drawing sheets
    [cassette_body_v0_8.stl, cassette_body_v0_8_divided.stl, cassette_lid_v0_8_print.stl]
2026-08-28 revert: restore clean baseline at beginning of Plan 004 (commit 242fcd6)
    - Revert Cassettes/glass_slide_cassette_40x80/ back to the verified v0.8 baseline
    - Restore original generate_cassette.py, README.md, manifests, and build artifacts
    - Revert Plan 004 task checklist to initial unexecuted state
    [cassette_body_v0_8.stl, cassette_body_v0_8_divided.stl, cassette_lid_v0_8_print.stl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]
2026-08-28 feat(cassette): integrate divider stations and removable divider cards
    - Add build_divided_body() with 2 thirds divider stations at Y = +/-12.87 mm (1.40 mm slot, 0.60 mm wall recess, 0.60 mm floor groove, 4.30 mm thickened hinge wall)
    - Add build_divider_card() generating 1.20 mm baseline card (33.30 x 31.20 x 1.20 mm with top extraction notch and lead-in chamfers) plus 1.00 mm and 1.40 mm calibration cards
    - Export cassette_body_v0_8_divided.stl and divider cards alongside standard undivided body and lid
    - Verify 100% clean mesh audits (0 boundary / 0 non-manifold edges across all files)
    [cassette_body_v0_8_divided.stl, divider_card_1_0mm.stl, divider_card_1_2mm.stl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]
2026-08-28 feat(cassette): fix divider slot orientation with negative recessed channels
    - Rebuild build_divided_body() to generate true negative transverse slots across X (at Y = +/-12.87 mm) and a continuous 0.60 mm floor groove
    - Verify 100% clean mesh audits (0 boundary / 0 non-manifold edges across all STLs)
    [cassette_body_v0_8_divided.stl]
2026-08-28 fix(hinge): thicken lower half and outer walls of hinge knuckle
    - Increase HINGE_OUTER_HALF_W to 2.25 mm and HINGE_OUTER_POINT to 2.70 mm (st = 0.80 mm)
    - Increase minimum wall thickness around the 2.25 mm body bore to >= 1.125 mm (3 solid perimeters) and bottom point thickness to 1.575 mm
    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
    [REFERENCE_closed_assembly_DO_NOT_PRINT.stl, cassette_assembly_reference_v0_8.obj, cassette_body_v0_8.stl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]
2026-08-28 feat(cassette): add tactile end grip ridges to cassette body
    - Add 3 horizontal end pinch ribs on front and back walls (Z = 27.5, 29.2, 30.9 mm; width 14.0 mm; projection 0.40 mm)
    - Apply grip ridges to both standard and divided cassette bodies
    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
    [REFERENCE_closed_assembly_DO_NOT_PRINT.stl, cassette_assembly_reference_v0_8.obj, cassette_body_v0_8.stl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]
2026-08-28 plan-010: add internal flanking wall ridges, loose-fit divider cards, and reinforced 0.85 mm closure clasp
    [REFERENCE_closed_assembly_DO_NOT_PRINT.stl, cassette_assembly_reference_v0_8.obj, cassette_body_v0_8.stl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]
2026-08-29 plan-010: record initial sample physical validation of loose-fit dividers and 0.85 mm clasp
2026-08-29 plan-011: archive Plan 010, add top-surface pinch grip flutes to lid, and remove protruding body end ribs
    [REFERENCE_closed_assembly_DO_NOT_PRINT.stl, cassette_assembly_reference_v0_8.obj, cassette_body_v0_8.stl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]
2026-08-29 Revert "plan-011: archive Plan 010, add top-surface pinch grip flutes to lid, and remove protruding body end ribs"
    This reverts commit f9c1473222a654be52930eb9373149d03fca7068.
    [REFERENCE_closed_assembly_DO_NOT_PRINT.stl, cassette_assembly_reference_v0_8.obj, cassette_body_v0_8.stl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]
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2026-08-29 cassette-lid: reinforce compliant glass clip to 1.20 mm solid PETG and increase lid to 3.60 mm (+1.10 mm clearance)
    [REFERENCE_closed_assembly_DO_NOT_PRINT.stl, cassette_assembly_reference_v0_8.obj, cassette_lid_v0_8_print.stl]
2026-08-29 hardware-prototyper: generate reversed rocker inserts for center pop-up extraction
    [rocker_insert_dual_slot_reversed.stl, rocker_insert_single_slot_reversed.stl]
2026-08-29 cassette-lid: add snap-in rigid ergonomic pull tab and matching 45-degree dovetail keyway
    [REFERENCE_closed_assembly_DO_NOT_PRINT.stl, cassette_assembly_reference_v0_8.obj, cassette_lid_v0_8_print.stl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]
2026-08-29 plan-011: anchor snap-in pull tab in 15mm front body dovetail keyway with lid skirt cutaway; archive plan 010
    [REFERENCE_closed_assembly_DO_NOT_PRINT.stl, cassette_assembly_reference_v0_8.obj, cassette_body_v0_8.stl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]
2026-08-29 cassette-lid: restore continuous solid front window rail and latch tongue anchorage; eliminate lengthwise channel
    [REFERENCE_closed_assembly_DO_NOT_PRINT.stl, cassette_assembly_reference_v0_8.obj, cassette_lid_v0_8_print.stl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]
2026-08-29 cassette-lid: extend pull tab cutaway through full thickness of lid (Z=0 to Z=LID_H)
    [REFERENCE_closed_assembly_DO_NOT_PRINT.stl, cassette_assembly_reference_v0_8.obj, cassette_lid_v0_8_print.stl]
2026-08-29 pull-tab: update to print laying flat on back face with face-up finger grip for max bed adhesion and tensile strength
    [REFERENCE_closed_assembly_DO_NOT_PRINT.stl, pull_tab_v0_8.stl]
2026-08-29 pull-tab: increase slide fit clearance to +0.35mm nominal standard and export tolerance ladder (firm/loose)
    [REFERENCE_closed_assembly_DO_NOT_PRINT.stl, pull_tab_v0_8.stl, pull_tab_v0_8_firm.stl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]
2026-08-29 cassette-body: cut true open pocket into front wall for dovetail keyway; eliminate solid wall occlusion
    [REFERENCE_closed_assembly_DO_NOT_PRINT.stl, cassette_assembly_reference_v0_8.obj, cassette_body_v0_8.stl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]
2026-08-29 cassette-body: thicken outer sidewall behind dovetail keyway to 1.50mm (approaching 2.0mm standard)
    [REFERENCE_closed_assembly_DO_NOT_PRINT.stl, cassette_assembly_reference_v0_8.obj, cassette_body_v0_8.stl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]
2026-08-29 cassette-body: build monolithic reinforced boss column with solid 2.5mm sidewalls flanking the dovetail keyway
    [REFERENCE_closed_assembly_DO_NOT_PRINT.stl, cassette_assembly_reference_v0_8.obj, cassette_body_v0_8.stl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]
2026-08-29 cassette-body: add smooth 45-degree support-free lead-in taper below the dovetail keyway boss shelf
    [REFERENCE_closed_assembly_DO_NOT_PRINT.stl, cassette_assembly_reference_v0_8.obj, cassette_body_v0_8.stl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]
2026-08-29 cassette-lid: enlarge pull-tab clearance cutout to 15mm; export tighter pull-tab fit ladder (0.20, 0.15, 0.10, 0.05mm)
    [REFERENCE_closed_assembly_DO_NOT_PRINT.stl, cassette_assembly_reference_v0_8.obj, cassette_lid_v0_8_print.stl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]
2026-08-29 plan-011: archive completed Plan 011 with verified +0.10mm pull-tab fit; activate Plan 012 for printable label sheets
    [REFERENCE_closed_assembly_DO_NOT_PRINT.stl, pull_tab_v0_8.stl]
2026-08-29 prototype: add experimental sliding pull tab with compliant cantilever snap-barb and full-height internal track
    [REFERENCE_sliding_tab_lifted_DO_NOT_PRINT.stl, REFERENCE_sliding_tab_lowered_DO_NOT_PRINT.stl, prototype_cassette_body_sliding_tab.stl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]
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2026-08-29 cassette-lid: expand entry-side solid band to 10mm for symmetrical dual 9mm label zones
    [REFERENCE_closed_assembly_DO_NOT_PRINT.stl, REFERENCE_sliding_tab_lifted_DO_NOT_PRINT.stl, REFERENCE_sliding_tab_lowered_DO_NOT_PRINT.stl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]
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2026-08-29 prototype: implement Two-Stage sliding pull tab (24.8mm anti-tilt column, solid bottom foot top-stop, and fixed internal clasp catch)
    [REFERENCE_sliding_tab_lifted_DO_NOT_PRINT.stl, REFERENCE_sliding_tab_lowered_DO_NOT_PRINT.stl, prototype_cassette_body_sliding_tab.stl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]
2026-08-30 clean: remove experimental sliding pull tab prototype; keep robust verified fixed pull tab baseline
    [REFERENCE_sliding_tab_lifted_DO_NOT_PRINT.stl, REFERENCE_sliding_tab_lowered_DO_NOT_PRINT.stl, prototype_cassette_body_sliding_tab.stl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]
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2026-08-30 fix(gridfinity-1x2): ensure body cavity is properly hollow (37.5x79.5x39.4mm deep) with perimeter walls and corner columns
    [REFERENCE_closed_assembly_1x2_7u_DO_NOT_PRINT.stl, REFERENCE_two_high_stack_1x2_14u_DO_NOT_PRINT.stl, gridfinity_cassette_body_1x2_7u.stl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]
2026-08-30 fix(gridfinity-1x2-lid): ensure stacking lip is a hollow perimeter rim with fully open 23x55mm glass viewing aperture
    [REFERENCE_closed_assembly_1x2_7u_DO_NOT_PRINT.stl, REFERENCE_two_high_stack_1x2_14u_DO_NOT_PRINT.stl, test_lid_clean.stl]
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2026-08-30 fix(gridfinity-1x2): hollow out hinge knuckle filament bores on body and lid, open compliant flexure slots, and hollow stacking lip corners
    [REFERENCE_closed_assembly_1x2_7u_DO_NOT_PRINT.stl, REFERENCE_two_high_stack_1x2_14u_DO_NOT_PRINT.stl, gridfinity_cassette_body_1x2_7u.stl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]
2026-08-30 fix(gridfinity-1x2-lid): extend glass entry and compliant flexure cutaway through front Gridfinity stacking lip
    [REFERENCE_closed_assembly_1x2_7u_DO_NOT_PRINT.stl, REFERENCE_two_high_stack_1x2_14u_DO_NOT_PRINT.stl, gridfinity_cassette_lid_1x2_7u_print.stl]
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2026-08-30 fix(gridfinity-1x2): thicken left wall to 5.25mm, embed hinge at X=-18.50mm to clear dividers, and add full-length through-tunnel with external pin ports
    [REFERENCE_closed_assembly_1x2_7u_DO_NOT_PRINT.stl, REFERENCE_two_high_stack_1x2_14u_DO_NOT_PRINT.stl, divider_card_1x2_7u_1_2mm.stl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]
2026-08-30 fix(gridfinity-1x2-body): relieve left wall above shelf Z=45.40mm to create open knuckle pockets for lid hinge
    [REFERENCE_closed_assembly_1x2_7u_DO_NOT_PRINT.stl, REFERENCE_two_high_stack_1x2_14u_DO_NOT_PRINT.stl, gridfinity_cassette_body_1x2_7u.stl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]
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2026-08-30 fix(gridfinity-1x2-lid): attach finger pull tab directly to front solid label band, place glass loading clip at rear
    [REFERENCE_closed_assembly_1x2_7u_DO_NOT_PRINT.stl, REFERENCE_two_high_stack_1x2_14u_DO_NOT_PRINT.stl, gridfinity_cassette_lid_1x2_7u_print.stl]
2026-08-30 fix(gridfinity-1x2-lip): replace segmented lip with authoritative continuous 3D lofted Gridfinity stacking lip matching official spec
    [REFERENCE_closed_assembly_1x2_7u_DO_NOT_PRINT.stl, REFERENCE_two_high_stack_1x2_14u_DO_NOT_PRINT.stl, gridfinity_cassette_body_1x2_7u.stl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]
2026-08-30 fix(gridfinity-1x2-body): extend guide slot rails continuously to rear end stop, eliminating hard corner notches
    [REFERENCE_closed_assembly_1x2_7u_DO_NOT_PRINT.stl, REFERENCE_two_high_stack_1x2_14u_DO_NOT_PRINT.stl, gridfinity_cassette_body_1x2_7u.stl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]
2026-08-30 fix(gridfinity-1x2-body): eliminate corner wedge intrusion into upper sliding slot region
    [REFERENCE_closed_assembly_1x2_7u_DO_NOT_PRINT.stl, REFERENCE_two_high_stack_1x2_14u_DO_NOT_PRINT.stl, gridfinity_cassette_body_1x2_7u.stl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]
2026-08-30 fix(gridfinity-1x2-body): ensure outer upper walls follow exact rounded corner profile, eliminating outer corner protrusions
    [REFERENCE_closed_assembly_1x2_7u_DO_NOT_PRINT.stl, REFERENCE_two_high_stack_1x2_14u_DO_NOT_PRINT.stl, gridfinity_cassette_body_1x2_7u.stl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]
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
